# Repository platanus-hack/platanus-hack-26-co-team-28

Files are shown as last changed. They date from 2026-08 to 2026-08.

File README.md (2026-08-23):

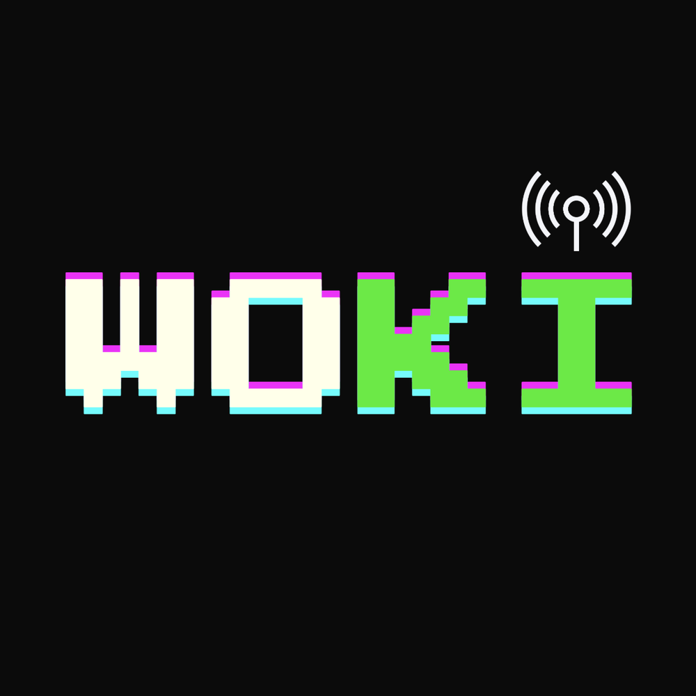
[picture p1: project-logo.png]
WOKI


# WOKI · Red de emergencia sin internet

**Track: 🚨 Emergencies · team-28 · Platanus Hack 26 Bogotá**







> Pedir ayuda y coordinar rescates sin internet, con visibilidad remota cuando vuelve la red.

Cuando un terremoto tumba la red celular, pedir ayuda deja de ser un problema de interfaz y se
vuelve un problema de comunicación. WOKI abre un camino local entre la persona afectada y el puesto
de mando, sin depender de internet.

```text
Celular → WiFi local → TTGO Esclavo → LoRa 915 MHz → TTGO Maestro → USB
                                                                     ↓
                                                     Centro Python + SQLite
                                                                     ↓ internet disponible
                                                        Vercel → Supabase
```

## Servicios locales y offline

| Servicio | Red o conexión | Dirección local | Qué permite hacer |
|---|---|---|---|
| Punto de ayuda | WiFi abierto **`[AFECTADOS] RED DE AYUDA WOKI`** | Portal cautivo; acceso manual en `https://ayuda.homiapp.xyz/` o `192.168.4.1` | Pedir ayuda, compartir la ubicación o reportarse a salvo desde cualquier celular, sin instalar una app |
| Portal del recurso | WiFi abierto **`RECURSO_<ID>`**, por ejemplo `RECURSO_GRUA07` | `http://192.168.4.1` | Recibir una misión o broadcast y confirmar su aceptación por LoRa |
| LoRa Maestro | Radio LoRa 915 MHz + USB serial | No publica una URL; usa `/dev/ttyUSB0` en Raspberry Pi o `/dev/cu.usbserial-*` en macOS | Conectar los nodos de campo con el Centro local |
| Command Center local | Raspberry Pi o laptop del puesto de mando | `http://localhost:8080` | Operar solicitudes, mapa, recursos, broadcasts y personas a salvo con SQLite, aun sin internet |
| Diagnóstico local | Mismo equipo del Centro | `http://localhost:8080/health` y `http://localhost:8080/api/v1/overview` | Verificar el Centro e integrar clientes locales |

Todos estos servicios operan sin internet. La dirección `192.168.4.1` se repite porque cada nodo
crea su propia red WiFi aislada: el celular debe conectarse primero al SSID correcto. Por seguridad,
el instalador expone el Centro solo en la misma laptop o Raspberry. Compartirlo en la LAN requiere
iniciarlo deliberadamente con `--host 0.0.0.0` y un `--api-token`; entonces se abre en
`http://<IP-DEL-CENTRO>:8080`.

## Todos los enlaces públicos

| Experiencia | URL | Qué demuestra | Alcance |
|---|---|---|---|
| **Entrega principal** | [Hub WOKI](https://woki-hub.vercel.app) | Entrada, onboarding y réplica online | URL oficial del concurso |
| Configuración guiada | [Preparar kit](https://woki-hub.vercel.app/setup) | Instalación del Maestro y Esclavo, voz y piezas 3D | Simulable sin dispositivos |
| Centro online | [Command Center](https://woki-hub.vercel.app/command-center) | Módulos operacionales con datos sincronizados | Réplica de solo lectura |
| Centro Python | [Demo en Render](https://woki-command-center-demo.onrender.com) | Centro local interactivo con datos sintéticos | Sin hardware ni sincronización externa; puede tardar en despertar |
| Diseño físico | [Visor 3D](https://woki-lora-enclosures.vercel.app) | Archivos STL/3MF listos para descargar e imprimir | Extensión física opcional |
| Flujo LoRa | [Visualización](https://lora.uprizing.me) | Recorrido conceptual entre celulares, nodos y Centro | Apoyo visual, no dependencia operacional |

El campo `deploy-url` de [`platanus-hack-project.jsonc`](./platanus-hack-project.jsonc) apunta al
Hub principal. Los demás despliegues son evidencia complementaria.

## Frictionless por diseño

- **Instalación asistida:** el onboarding visual entrega prompts breves y especializados para que
  ChatGPT, Claude u otro agente de IA acompañe el setup. Para perfiles técnicos, dos comandos
  instalan Arduino CLI, ESP32, librerías, firmware y Python sin requerir Arduino IDE.
- **Operación con triage:** el Centro prioriza la demanda y recomienda cómo distribuir recursos
  compatibles; el operador humano conserva la decisión sobre cada despacho crítico.
- **Acceso ciudadano sin app:** al conectarse a **`[AFECTADOS] RED DE AYUDA WOKI`** se abre el
  portal cautivo para pedir ayuda en pocos pasos. Los tags NFC/QR están definidos para instalarse
  en columnas y puntos seguros y facilitar el ingreso a la red; esta capa física aún debe validarse
  en campo.

## Cómo funciona

### 1. Portal local, sin app

El nodo afectado ofrece una red WiFi abierta y un portal servido por el ESP32. La persona elige
`RESCATE`, `MEDICO`, `FUEGO`, `AGUA` o `GRUA`, o se reporta a salvo. Después puede compartir GPS o
describir el lugar manualmente. La pantalla sigue el estado: recibida, aceptada, en ruta y resuelta.

### 2. LoRa bidireccional

Las placas LilyGO TTGO LoRa32 transportan paquetes cortos por SX1276 a 915 MHz. El protocolo usa
destino, identificador de mensaje, ACK, deduplicación, CAD y reintentos. El Centro recibe reportes y
también envía despachos, estados y broadcasts a los recursos.

### 3. Centro local como fuente de verdad

Una Raspberry Pi o laptop ejecuta el Centro Python. SQLite conserva solicitudes, recursos,
timeline, personas a salvo y una outbox durable. El mapa, triage y dashboard operan offline. El
sistema recomienda recursos compatibles, pero una persona autoriza cada despacho crítico.

```text
PENDIENTE → ACEPTADA → EN_CURSO → RESUELTA
                    ↘ CANCELADA
```

### 4. Sincronización eventual

Cuando vuelve internet, el Centro envía su outbox al endpoint autenticado de Vercel. Supabase
ingiere cada evento de forma idempotente y el Hub muestra una réplica de solo lectura. Si Vercel,
Supabase o internet fallan, la operación local continúa y la cola reintenta después.

### 5. Onboarding guiado

El Hub guía nueve pasos desde la descarga del proyecto hasta la verificación completa, incluyendo
antenas, Maestro, Esclavo, WiFi local y piezas imprimibles. El modo simulación permite entender el
recorrido sin disponer todavía del hardware.

## Estado demostrado

| Capacidad | Estado |
|---|---|
| Portal cautivo y envío desde celular | Validado en hardware |
| LoRa, ACK y canal bidireccional | Validado en hardware |
| SOS, triage, despacho, aceptación, trayecto y resolución | Implementado y probado automáticamente |
| Centro Python, SQLite y mapa offline | Implementado |
| Outbox, ingesta idempotente y Hub online | Implementado y desplegado |
| Onboarding, voz en español y prompts de soporte | Implementado y desplegado |
| NFC y QR para descubrir la red | Definido, todavía no implementado |
| Carcasas y bandejas 3D | Diseñadas; validar tolerancias físicas antes de campo |

## Stack tecnológico

| Capa | Tecnología | Responsabilidad |
|---|---|---|
| Hardware | LilyGO TTGO LoRa32 T3 V1.6.1, ESP32-PICO-D4, SX1276 | Nodos de campo y Gateway Maestro |
| Firmware | C++/Arduino, RadioLib, WiFi SoftAP | Portal local y protocolo LoRa 915 MHz |
| Centro offline | Python 3, SQLite WAL, pyserial | Radio, persistencia, triage, API y sincronizador |
| Mapas | Leaflet, VectorGrid, MBTiles, OpenStreetMap/Geofabrik | Cartografía local y online |
| Hub online | Next.js 16, React 19, TypeScript, Bun | Onboarding y Command Center sincronizado |
| Datos online | Supabase Postgres, RLS y RPC idempotente | Réplica segura de eventos operacionales |
| Despliegue | Vercel y Render | Hub principal y demo aislada del Centro Python |
| Onboarding | ElevenLabs Multilingual v2 + prompts para ChatGPT/Claude | Guía de voz y acompañamiento de instalación |
| Diseño físico | OpenSCAD, STL/3MF y Three.js | Carcasas y visor de piezas imprimibles |

## Probarlo

### Camino guiado

Abre <https://woki-hub.vercel.app/setup>. El modo simulación está activo por defecto.

### Camino técnico

Clona el repositorio y conecta siempre la antena de 915 MHz antes de energizar una placa.

```bash
git clone https://github.com/platanus-hack/platanus-hack-26-co-team-28.git
cd platanus-hack-26-co-team-28
```

Prepara el Gateway Maestro y el Centro en macOS o Linux:

```bash
bash lora-emergencia/scripts/instalar_maestro.sh
```

Prepara un nodo Esclavo/Recurso:

```bash
bash lora-emergencia/scripts/instalar_esclavo.sh
```

Sin hardware, inicia solamente el Centro con datos sintéticos:

```bash
cd lora-emergencia/center
python3 center.py --demo
```

⚠️ **Nunca energices una placa sin la antena enroscada.** Transmitir sin antena puede dañar el
amplificador de radio.

## Documentación

| Quiero… | Leer |
|---|---|
| El relato para jurados | [`project-description.md`](project-description.md) |
| La topología completa | [`docs/ARQUITECTURA-CONEXIONES.md`](docs/ARQUITECTURA-CONEXIONES.md) |
| Operar el Centro y sincronizar | [`docs/OPERAR-SINCRONIZACION.md`](docs/OPERAR-SINCRONIZACION.md) |
| Revisar el hardware compatible | [`lora-emergencia/docs/HARDWARE.md`](lora-emergencia/docs/HARDWARE.md) |
| Entender el protocolo de radio | [`lora-emergencia/docs/PROTOCOLO-MINIMO.md`](lora-emergencia/docs/PROTOCOLO-MINIMO.md) |
| Preparar el portal cautivo | [`lora-emergencia/docs/PORTAL-CAUTIVO-E2E.md`](lora-emergencia/docs/PORTAL-CAUTIVO-E2E.md) |
| Fabricar las piezas 3D | [`lora-emergencia/diseno-3d/README.md`](lora-emergencia/diseno-3d/README.md) |
| Navegar toda la documentación | [`docs/README.md`](docs/README.md) |

Cada capacidad se marca como **implementada**, **validada en hardware**, **definida** o
**investigada**. No usamos “funciona” para algo que solo está diseñado.

## Equipo

- Juan Ortega ([@juanortega10](https://github.com/juanortega10))
- Nicolas Vargas ([@MrUprizing](https://github.com/MrUprizing))
- Jhomar Astuyauri Herencia ([@asther0](https://github.com/asther0))
- Emmy Daniela Arias Pardo ([@estparcae](https://github.com/estparcae))
- Manuel Torres ([@amunm9](https://github.com/amunm9))

**WOKI funciona cuando internet no funciona.**

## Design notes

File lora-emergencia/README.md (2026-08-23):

# lora-emergencia

Red de nodos de emergencia. Comunicación entre placas **LilyGO TTGO LoRa32** por LoRa 915 MHz, para llevar reportes cortos desde una zona sin señal hasta un centro de operaciones.

Este repo tiene el firmware que ya funciona entre dos placas, los scripts para flashear y leer, y la documentación para seguir avanzando.

> La entrada principal del proyecto y el orden vigente de lectura están en
> [`../README.md`](../README.md) y [`../docs/README.md`](../docs/README.md). Los sketches
> `nodo_tx`, `gateway_rx` y el documento `docs/PROTOCOL.md` son referencias legacy; el demo
> actual usa el protocolo direccionado de `docs/PROTOCOLO-MINIMO.md`.

---

## Estado actual (qué ya funciona)

- ✅ Enlace LoRa de una vía entre 2 placas. Verificado en hardware.
- ✅ Enlace bidireccional con ACK. El gateway confirma cada reporte.
- ✅ Toolchain macOS con `arduino-cli` + RadioLib.

Pruebas reales medidas entre 2 placas a ~20 cm:

Una vía (gateway recibe el reporte):
```
RECV|a3f21c|atrapado|apto401|604232|RSSI:-23.00|SNR:9.50
```

Bidireccional (el nodo recibe el ACK de vuelta):
```
[NODO] ACK recibido. RSSI:-21.00 SNR:9.25
```

La cadena completa: nodo → LoRa 915 → gateway → ACK → nodo. Con pérdidas ocasionales que dispara el reintento, comportamiento normal de LoRa sin CAD.

---

## Hardware

- 2× **LilyGO TTGO LoRa32**, modelo **T3 V1.6.1**, banda **915 MHz** (chip **SX1276**).
- La placa integra ESP32 (WiFi + BT) + radio LoRa SX1276 + conector SMA + batería JST + micro-USB.
- Antena 915 MHz (viene en la caja o se compra aparte).
- Cable **micro-USB de datos** (no de solo carga).

**Regla de oro:** nunca energizar una placa sin la antena enroscada. Transmitir sin antena daña el amplificador de forma permanente.

Ver [`docs/HARDWARE.md`](docs/HARDWARE.md) para pines y detalles.

---

## Estructura del repo

```
lora-emergencia/
├── README.md                 este archivo
├── nodo_tx/                  firmware: solo transmisor (test más simple)
├── gateway_rx/               firmware: solo receptor (test más simple)
├── nodo_bidir/               firmware: nodo con ACK (bidireccional)
├── gateway_bidir/            firmware: gateway con ACK (bidireccional)
├── nodo_portal/              firmware MVP: WiFi "AYUDA" + portal cautivo + LoRa
├── nodo_recurso/             firmware: recurso que recibe despachos/broadcasts + web local
├── center/
│   ├── center.py             command center offline del puesto de mando
│   ├── command_core.py       dominio, protocolo y persistencia SQLite
│   ├── CENTRO.md             guía operativa Raspberry ↔ gateway ↔ recursos
│   └── TOOLCHAIN.md          instalación, compilación y diagnóstico
├── diseno-3d/                módulos físicos, CAD paramétrico y STL/3MF
│   ├── MODULOS.md            centro maestro, nodo de campo y energía
│   ├── cad/                   fuente OpenSCAD
│   └── exports/               archivos listos para laminar
├── scripts/
│   ├── flash.sh              compilar y subir un firmware a una placa
│   ├── monitor.sh            leer el serial de una placa
│   └── pi_reader.py          leer y parsear el gateway desde la Raspberry Pi
└── docs/
    ├── SETUP.md              instalar el entorno paso a paso
    ├── HARDWARE.md           placa, pines, antena
    ├── PROTOCOL.md           formato de mensajes y parámetros LoRa
    ├── ARCHITECTURE.md       diseño del sistema y roadmap
    └── TROUBLESHOOTING.md    errores reales y cómo se resolvieron
```

---

## Quickstart

### 1. Instala el entorno (una sola vez)

```bash
brew install arduino-cli
arduino-cli config init
arduino-cli config add board_manager.additional_urls https://raw.githubusercontent.com/espressif/arduino-esp32/gh-pages/package_esp32_index.json
arduino-cli core update-index
arduino-cli core install esp32:esp32     # descarga grande (~500 MB), tarda
arduino-cli lib install RadioLib
```

Detalle completo en [`docs/SETUP.md`](docs/SETUP.md).

### 2. Encuentra el puerto de tu placa

Conecta la placa (con antena) y corre:

```bash
arduino-cli board list
```

Busca algo como `/dev/cu.usbserial-XXXXXXXX` (macOS) o `/dev/ttyUSB0` (Linux/Pi).

### 3. Flashea y prueba el enlace de una vía

Con dos placas y dos puertos:

```bash
# Placa 1 = transmisor
./scripts/flash.sh nodo_tx /dev/cu.usbserial-AAAA

# Placa 2 = receptor
./scripts/flash.sh gateway_rx /dev/cu.usbserial-BBBB

# Lee el receptor: deben aparecer las lineas RECV|...
./scripts/monitor.sh /dev/cu.usbserial-BBBB
```

### 4. Prueba el enlace bidireccional con ACK

```bash
./scripts/flash.sh gateway_bidir /dev/cu.usbserial-BBBB
./scripts/flash.sh nodo_bidir    /dev/cu.usbserial-AAAA
./scripts/monitor.sh /dev/cu.usbserial-AAAA   # el nodo muestra "ACK recibido"
```

---

## Los 4 firmwares

| Firmware | Rol | Qué hace |
|---|---|---|
| `nodo_tx` | Transmisor | Envía un reporte cada 5 s. El test más simple |
| `gateway_rx` | Receptor | Recibe y lo imprime con RSSI y SNR |
| `nodo_bidir` | Nodo con ACK | Envía, espera confirmación, reintenta 3 veces con backoff |
| `gateway_bidir` | Gateway con ACK | Recibe, imprime, y confirma de vuelta al nodo |

Empieza siempre por `nodo_tx` + `gateway_rx`. Si el enlace de una vía funciona, todo lo demás es software.

---

## MVP de emergencia (ciclo completo)

El flujo mínimo: un civil pide ayuda desde su celular, sin app, y el reporte llega al puesto de mando.

```
📱 civil → WiFi "AYUDA" → NODO (portal) → LoRa → GATEWAY → USB → CENTRO (dashboard)
```

Componentes:
- **Nodo** (`nodo_portal`): red WiFi abierta `AYUDA` + portal cautivo (sin app, sin JS). Botones: agua, médico, rescate, a salvo + detalle. Envía por LoRa y espera ACK.
- **Gateway** (`gateway_bidir`): recibe el reporte, responde ACK, lo imprime por serial.
- **Centro** (`center/center.py`): lee el gateway y muestra un tablero en vivo con contadores y color por tipo.

### Cómo correrlo

```bash
# 1. Placa del nodo (crea la red AYUDA)
./scripts/flash.sh nodo_portal /dev/cu.usbserial-AAAA

# 2. Placa del gateway (conectada a la Mac o a la Pi)
./scripts/flash.sh gateway_bidir /dev/cu.usbserial-BBBB

# 3. Centro: lee el gateway y abre el tablero
pip install pyserial          # o: pip install pyserial --break-system-packages
python3 center/center.py /dev/cu.usbserial-BBBB
# abre http://localhost:8080

# 4. Con el celular: conéctate a la red WiFi "AYUDA".
#    El portal se abre solo. Pide ayuda. El reporte aparece en el tablero.
```

Modo sin hardware para probar el tablero:
```bash
python3 center/center.py --demo
```

### Estado verificado

- Nodo: `SoftAP 'AYUDA' en 192.168.4.1` + `LoRa OK`. ✅
- Gateway: recibe + ACK. ✅
- Centro: tablero + API de reportes. ✅
- Falta probar en un teléfono real el disparo del portal cautivo (iOS lo abre solo; Android a veces pide abrir el navegador en `192.168.4.1`).

---

## Parámetros LoRa (deben coincidir en TODAS las placas)

```cpp
radio.begin(915.0, 125.0, 7, 5, 0x12, 20, 8);
//          freq   BW    SF CR sync pwr preamble
```

**La falla nº1 de LoRa:** si un solo parámetro difiere entre dos placas, no se oyen y **no hay ningún mensaje de error**. Si no recibes nada, revisa esto primero.

Ver [`docs/PROTOCOL.md`](docs/PROTOCOL.md).

---

## Próximos pasos (para el equipo)

1. **Validar el loop físico vigente:** portal HTTPS → LoRa → centro → estados de vuelta al ciudadano.
2. **Publicar el Hub online:** réplica de consulta en Vercel + Supabase.
3. **Sincronizar con outbox:** enviar Eventos operacionales sin bloquear SQLite ni el flujo local.
4. **Hacer reproducible el portal HTTPS:** plantilla segura de credenciales y compilación limpia desde un clon.
5. **Escalar el borde:** agregación, identidad derivada del dispositivo y pruebas con múltiples nodos separados.

Ver el diseño completo y el roadmap en [`docs/ARCHITECTURE.md`](docs/ARCHITECTURE.md).

---

## Si algo no funciona

Lee [`docs/TROUBLESHOOTING.md`](docs/TROUBLESHOOTING.md). Los errores reales que ya resolvimos:
- Subida falla a 921600 → usa `UploadSpeed=115200` (los scripts ya lo hacen).
- El puerto no aparece → driver USB o cable de solo carga.
- No recibe nada → los 6 parámetros LoRa no coinciden.

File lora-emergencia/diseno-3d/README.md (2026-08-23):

# Diseño 3D · sistema físico WOKI

Kit mecánico del centro LoRa y los nodos de campo. La carpeta contiene archivos
STL/3MF, fuente OpenSCAD, cotas, lista de compra y pruebas pendientes.

## Qué se fabrica

- **Centro maestro:** marco y pies para la pantalla, bandeja de servicio para
  Raspberry Pi 4 + TTGO maestro y cuna del power bank.
- **Nodo demo:** base, tapa abierta y placa universal de batería.
- **Nodo de campo:** bandeja interna para una caja comercial Hammond IP68. La
  caja sellada no se imprime: eso evita afirmar resistencia al agua sin ensayos.

La selección no imprimible y sus fuentes están en
[`ABASTECIMIENTO.md`](ABASTECIMIENTO.md). La arquitectura está en
[`MODULOS.md`](MODULOS.md) y el dictamen de suficiencia en
[`VERIFICACION.md`](VERIFICACION.md).

## Ver el inventario

```bash
python3 -m http.server 8090 --directory lora-emergencia/diseno-3d
```

Abre <http://localhost:8090> o la copia pública:
<https://woki-lora-enclosures.vercel.app>.

Cada tarjeta permite abrir la pieza en un visor 3D. Dentro del modal se puede
rotar arrastrando, acercar con la rueda o un pellizco, desplazar con clic derecho
o dos dedos y recuperar el encuadre con **Reiniciar vista**. El visor carga los
STL y Three.js desde esta misma carpeta, sin depender de un CDN o de Internet.

## Generar y validar

```bash
cd lora-emergencia/diseno-3d
make all
make validate
make previews
```

OpenSCAD genera ocho geometrías distintas; `pantalla_pie` se imprime dos veces.
Cada pieza tiene STL y 3MF. El validador comprueba dimensiones, componentes y
aristas manifold sin dependencias externas de Python.

## Estado de certeza

- Raspberry Pi 4 y TTGO T3 V1.6.1: hardware confirmado.
- Pantalla: coincidencia visual fuerte con Waveshare 7inch HDMI LCD (C); el CAD
  usa el dibujo oficial y ranuras de tolerancia, pero falta leer la etiqueta
  trasera de la unidad real antes de imprimir el marco definitivo.
- Energía del nodo: solo batería 1S protegida; el TTGO no incorpora BMS.
- Uso con lluvia: caja comercial IP68 + bandeja interna impresa.
- Ningún ajuste se considera validado hasta imprimirlo contra el hardware real.

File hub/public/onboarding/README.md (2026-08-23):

# Imágenes del onboarding WOKI

Estas imágenes no contienen instrucciones incrustadas. El texto, los indicadores y las
flechas interactivas deben superponerse desde la interfaz para poder corregirlos sin
regenerar los recursos.

| Archivo | Uso sugerido | Mensaje principal |
| --- | --- | --- |
| `kit-overview.webp` | Inventario inicial | Verifica que tienes las placas, antenas, cables, Raspberry Pi, batería y celulares. La pantalla externa no es necesaria. |
| `antenna-first.webp` | Preparación de cada TTGO | Conecta la antena antes de suministrar energía o conectar USB. |
| `connect-local-wifi.webp` | Nodo civil o de recurso | Desde el celular, conéctate directamente a `AYUDA` o `RECURSO_<ID>`. Es normal que el teléfono indique “sin internet”. Si el portal no abre solo, visita `http://192.168.4.1`. |
| `command-center-wiring.webp` | Centro local | Conecta el gateway por USB de datos a la Raspberry Pi, alimenta la Pi y abre el Centro desde el celular en la red local. |
| `system-topology.webp` | Explicación final | Los celulares hablan por Wi-Fi local con WOKI; los nodos hablan por LoRa; solo el Centro sincroniza eventualmente con internet. |

Código de color sugerido para las superposiciones:

- Azul: Wi-Fi local.
- Verde lima: LoRa.
- Naranja: USB, datos o alimentación.
- Gris punteado: sincronización online opcional.

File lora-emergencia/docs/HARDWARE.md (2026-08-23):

# HARDWARE · LilyGO TTGO LoRa32 T3 V1.6.1

## La placa

- Modelo: **LilyGO TTGO LoRa32**, silkscreen **T3_V1.6.1**.
- SoC: **ESP32-PICO-D4** (WiFi 2.4 GHz + Bluetooth + doble núcleo).
- Radio LoRa: **Semtech SX1276**, banda **915 MHz** (también existe versión 868).
- Conector de antena: **SMA** (dorado).
- Alimentación: micro-USB, o batería LiPo por conector JST 1.25.
- Controles: interruptor ON/OFF, botón RST, botón BOOT.
- Chip USB-serial: CP2102 o CH9102 según el lote (macOS moderno los reconoce solos).

## Pines LoRa (SX1276) para RadioLib

Estos son los pines usados en todos los firmwares del repo:

| Función | GPIO |
|---|---|
| SCK  | 5  |
| MISO | 19 |
| MOSI | 27 |
| CS / NSS | 18 |
| RST  | 23 |
| DIO0 | 26 |
| DIO1 | 33 |

En código:

```cpp
#include <RadioLib.h>
SPI.begin(5, 19, 27, 18);                    // SCK, MISO, MOSI, CS
SX1276 radio = new Module(18, 26, 23, 33);   // CS, DIO0, RST, DIO1
```

## Antena

- Enrosca la antena 915 MHz en el conector SMA **antes** de energizar.
- **Nunca transmitas sin antena.** El SX1276 se daña de forma permanente.
- Una antena látigo de 915 MHz mide ~7-8 cm. Una de ~17 cm suele ser de 433 MHz (no sirve).

## Alimentación en campo

- Un nodo activo (WiFi AP + LoRa) consume ~120-250 mA.
- Un powerbank de 20.000 mAh lo mantiene más de 24 h.
- Aviso: algunos powerbanks se apagan solos cuando el consumo baja de 50-100 mA. Con el nodo activo no pasa, pero pruébalo con el powerbank real.

## OLED

Algunas T3 V1.6.1 traen pantalla OLED (I2C, SDA 21 / SCL 22) y otras no. Los firmwares vigentes `gateway_bidir`, `nodo_portal_https` y `range_movil` la detectan antes de usarla; la operación principal no depende de que esté presente.

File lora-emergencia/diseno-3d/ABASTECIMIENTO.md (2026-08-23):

# Abastecimiento y compatibilidad

Investigación cerrada el **23 de agosto de 2026**. Precio y stock pueden cambiar;
las cotas y parámetros eléctricos se enlazan a fabricante siempre que existe.

## Compra recomendada

### Un centro maestro

| Cant. | Componente exacto o especificación | Decisión |
|---:|---|---|
| 1 | Raspberry Pi 4 Model B existente | Reutilizar |
| 1 | [Carcasa oficial Raspberry Pi 4](https://www.raspberrypi.com/products/raspberry-pi-4-case/) | Comprar si la Pi sigue expuesta |
| 1 | [Ventilador oficial para esa carcasa](https://www.raspberrypi.com/products/raspberry-pi-4-case-fan/) | Comprar; incluye disipador 18 × 18 × 10 mm |
| 1 | Pantalla existente, candidata [Waveshare 7inch HDMI LCD (C)](https://www.waveshare.com/wiki/7inch_HDMI_LCD_%28C%29) | Reutilizar; confirmar etiqueta trasera |
| 1 | TTGO T3 V1.6.1 maestro existente | Reutilizar |
| 1 | [Baseus Adaman 65 W, 20.000 mAh](https://www.baseus.com/products/adaman-power-bank-65w-20000mah) | Candidato principal: 74 Wh, 154 × 65 × 27 mm, USB-C 5 V/3 A |
| 1 | Cable USB-C a USB-C de 3 A, 0,3–0,5 m | Power bank → Raspberry |
| 1 | Cable micro-HDMI macho a HDMI macho, 0,3–0,5 m | Raspberry → pantalla |
| 2 | Cable USB-A a micro-USB **de datos**, corto | Pantalla táctil y TTGO serie |
| 4 | Correas de velcro 15–20 mm | Dos para Pi, dos para power bank |
| 4 | M3 × 12 + arandela; 4 separadores M3 de 12–18 mm | Pantalla y bandeja |

La Raspberry Pi 4 requiere una fuente recomendada de 3 A y admite hasta 1,2 A
totales para periféricos USB. La pantalla declara 500 mA; por eso la validación
eléctrica de pantalla + TTGO es obligatoria.

### Cada nodo de campo

| Cant. | Componente exacto o especificación | Decisión |
|---:|---|---|
| 1 | [TTGO T3 LoRa32 V1.6.1 915 MHz](https://lilygo.cc/products/lora3) | Placa existente; SMA estándar |
| 1 | [Hammond 1554F2GYCL](https://www.hammfg.com/part/1554F2GYCL) | Policarbonato IP68, 119 × 89 × 61 mm, tapa transparente |
| 1 | [Amphenol 095-902-569-006](https://www.amphenolrf.com/en-us/part/095-902-569-006/9316/) | SMA 50 Ω, RG-316, 153 mm, pasamuros IP67 |
| 1 | Antena 915 MHz incluida por LILYGO | Se conecta al pasamuros; nunca transmitir sin antena |
| 1 | [LiPo protegida 2.000 mAh](https://www.adafruit.com/product/2011) **o** [Li-ion protegida 4.400 mAh](https://www.adafruit.com/product/354) | Compacta 60 × 36 × 7 mm o extendida 69 × 37 × 18 mm |
| 1 | Pigtail JST-GH 1,25 mm incluido con TTGO | Adaptar a batería; verificar polaridad |
| 2 | Correas de velcro 10–15 mm | Una TTGO, una batería |
| 4 | M3 × 8 mm | Bandeja a insertos internos Hammond |
| 1 | Prensaestopa IP68 adicional, si se agrega cable externo | Dimensionar al cable real; preferir ningún cable |

## Por qué se seleccionó así

### Pantalla

La foto coincide en orejas verdes, HDMI/USB laterales y proporción con la
Waveshare C. El fabricante indica panel de 164,9 × 106,96 × 8 mm, 2,5 W, 5 V y
500 mA; el dibujo mecánico amplía la envolvente con PCB/orejas a 164,9 × 124,27
mm. El marco usa ranuras para tolerancia, pero la etiqueta sigue siendo la prueba
definitiva de revisión.

### Raspberry y refrigeración

Usar la carcasa y el ventilador oficiales convierte la Pi en un submódulo
protegido, con flujo probado de hasta 1,4 CFM. La bandeja impresa lo sujeta con
correas y no comprime directamente la PCB.

### Energía del nodo

LILYGO dice expresamente que T3 V1.6.1 **no tiene BMS** y exige batería con
protección. También especifica 3,7 V y carga de 500 mA. Las dos baterías elegidas
incorporan protección; la de 4.400 mAh admite carga lenta a 500 mA.

Los conectores no coinciden: Adafruit usa JST-PH 2,0 mm y LILYGO JST-GH 1,25 mm.
No forzar ni invertir un conector. Empalmar el pigtail suministrado, aislar cada
conductor y verificar con multímetro positivo/negativo antes de enchufar.

### Protección de campo

La Hammond mantiene un grado IP real y ofrece insertos M3. El pasamuros Amphenol
evita transferir palanca de la antena al SMA de la placa. Una carcasa FDM abierta
se conserva únicamente para mesa/demo.

## Disponibilidad observada

- Adafruit: baterías de 2.000 y 4.400 mAh figuraban disponibles al consultar.
- Hammond: la referencia tiene distribución por DigiKey/Mouser; el fabricante
  publica dibujo, STEP/IGES y repuestos de junta/tornillos.
- Baseus: la referencia exacta puede variar por país; si no está disponible,
  aceptar solo un reemplazo de 20.000 mAh con salida USB-C sostenida de 5 V/3 A,
  tres salidas y dimensiones medidas antes de imprimir la cuna.
- Baterías enviadas internacionalmente pueden tener restricciones. Priorizar un
  proveedor local que declare **PCM/BMS**, voltaje, medidas y polaridad.

## No comprar todavía

- Baterías sin ficha, celdas 18650 sueltas o paquetes sin protección.
- Conectores “JST” sin indicar familia y paso.
- Antena RP-SMA: la selección es SMA estándar de 50 Ω.
- Una segunda caja impresa “impermeable”; duplica trabajo y no prueba IP.
- GPS físico para el nodo: el flujo actual acepta ubicación del celular y no
  requiere rastreo continuo.

## Criterio para aceptar sustitutos

1. Igual voltaje y corriente, nunca solo “mismos watts”.
2. Medidas documentadas y tolerancia de al menos 0,7 mm por lado en CAD.
3. Batería 1S protegida y polaridad verificada.
4. Radio/antena 915 MHz, 50 Ω y SMA estándar.
5. Caja de campo con certificación IP del fabricante, no del vendedor.
6. Cable USB de datos cuando transporta táctil o serial; uno de carga no basta.

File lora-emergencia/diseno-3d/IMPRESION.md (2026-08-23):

# Fabricación e impresión

## Archivos

| Equipo | Pieza | Cantidad | STL / 3MF |
|---|---|---:|---|
| Centro | Bandeja RPi4 + TTGO | 1 | `centro_bandeja` |
| Centro | Marco trasero de pantalla | 1 | `pantalla_marco` |
| Centro | Pie inclinado | 2 | `pantalla_pie` |
| Centro | Cuna Baseus 20 Ah | 1 | `centro_powerbank` |
| Nodo demo | Base TTGO | 1 | `nodo_base` |
| Nodo demo | Tapa abierta | 1 | `nodo_tapa` |
| Nodo demo | Placa universal de batería | 1 | `bateria_placa` |
| Nodo campo | Bandeja interna Hammond IP68 | 1 | `nodo_bandeja_ip68` |

Cada nombre existe en `exports/stl/` y `exports/3mf/`. Los 3MF contienen la
geometría; el perfil del laminador se define según la impresora disponible.

## Perfil inicial

- PETG para piezas finales; PLA solo para pruebas de ajuste interiores.
- Boquilla 0,4 mm; capa 0,20 mm; 3 perímetros; 20–25 % gyroid.
- 5 capas superiores e inferiores para marco y pies.
- Sin soportes con la orientación exportada.
- Compensación de elephant foot: 0,15–0,20 mm si está disponible.
- No escalar los modelos en el laminador.

## Orden recomendado

1. Imprimir `pantalla_pie` una vez y probar el canal con una tira de 3,2 mm.
2. Confirmar etiqueta/cotas de pantalla; imprimir `pantalla_marco`.
3. Imprimir `centro_bandeja` y verificar carcasa RPi4, USB, HDMI y SMA.
4. Comprar la batería elegida y la caja Hammond.
5. Imprimir `nodo_bandeja_ip68`; presentar piezas sin batería conectada.
6. Solo después imprimir el resto del kit.

## Montaje y pruebas

- M3 con arandela para pantalla y caja Hammond; no sobreapretar plástico/PCB.
- Separadores de 12–18 mm entre marco de pantalla y bandeja de electrónica.
- Velcro de 15–20 mm; una correa por componente en el nodo.
- Mantener radios suaves en HDMI, USB y coaxial; ningún cable sostiene peso.
- Ensayo térmico de dos horas con WiFi/LoRa activos.
- Ensayo de autonomía completo y registro de reinicios/bajo voltaje.
- Ensayo de salpicadura solo con la caja comercial cerrada y electrónica de
  prueba. Perforar la caja puede invalidar su grado IP si el pasamuros no sella.

Los modelos son manifold e imprimibles, pero aún no tienen ajuste físico
verificado ni certificación de impacto, fuego o estanqueidad.

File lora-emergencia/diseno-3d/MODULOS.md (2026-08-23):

# WOKI · módulos físicos

El sistema necesita dos equipos, no una colección abierta de accesorios.

## 1. Centro maestro

| Elemento | Selección | Integración mecánica |
|---|---|---|
| Computador | Raspberry Pi 4 Model B | Carcasa oficial + ventilador oficial; sujeta con dos correas a `centro_bandeja` |
| Pantalla | Candidata Waveshare 7inch HDMI LCD (C) | `pantalla_marco` + 2 × `pantalla_pie` |
| Radio maestro | TTGO T3 V1.6.1, 915 MHz | Dock de `centro_bandeja` |
| Energía móvil | Baseus Adaman 65 W, 20.000 mAh | `centro_powerbank` + dos correas |
| Antena | SMA 915 MHz incluida | Exterior, siempre conectada antes de transmitir |

### Cableado del centro

```text
Power bank USB-C ──────────────> USB-C de Raspberry Pi 4 (5 V / 3 A)
Raspberry micro-HDMI ──────────> HDMI estándar de pantalla
Raspberry USB-A ───────────────> micro-USB de pantalla (táctil + 5 V)
Raspberry USB-A ───────────────> micro-USB TTGO (datos serie + 5 V)
```

La pantalla requiere 500 mA y el límite total oficial de periféricos USB de la
Raspberry Pi 4 es 1,2 A. Pantalla y TTGO deben probarse juntos bajo carga. Si hay
avisos de bajo voltaje se debe usar un hub USB alimentado, no improvisar un cable
en Y. El power bank seleccionado entrega 5 V/3 A por USB-C.

### Piezas del centro

| Pieza | Medida exterior | Cantidad | Rol |
|---|---:|---:|---|
| `pantalla_marco` | 170 × 129 × 3,2 mm | 1 | Marco trasero ventilado; patrón 148,9 × 114,96 mm |
| `pantalla_pie` | 54 × 46 × 16 mm | 2 | Soporte de mesa con inclinación de 12° |
| `centro_bandeja` | 168 × 76 × 10,65 mm | 1 | Carcasa RPi4 por correas + dock TTGO |
| `centro_powerbank` | 161,2 × 72,2 × 7 mm | 1 | Cuna abierta para batería central |

`pantalla_marco` supone la Waveshare candidata. Antes de imprimir se debe
confirmar la etiqueta posterior o medir 164,9 × 124,27 mm de envolvente y
148,9 × 114,96 mm entre centros. No bloquea HDMI, micro-USB ni el interruptor.

## 2. Nodo de campo

| Elemento | Selección | Integración mecánica |
|---|---|---|
| Radio | TTGO T3 V1.6.1, 915 MHz | Bandeja interna, lado independiente |
| Batería | 3,7 V 1S protegida, 2.000 o 4.400 mAh | Correa separada; nunca comprimir |
| Envolvente | Hammond 1554F2GYCL, policarbonato | Caja comercial IP68 de 119 × 89 × 61 mm |
| Antena exterior | SMA 915 MHz | Pigtail Amphenol IP67 a pasamuros |
| Transporte | Pies/pole-mount Hammond o correa exterior | No perforar fuera del plan de sellado |

### Dos configuraciones deliberadas

- `nodo_base` + `nodo_tapa` + `bateria_placa`: demo interior, accesible y rápida.
- `nodo_bandeja_ip68` dentro de Hammond 1554F2GYCL: candidato para campo.

La bandeja IP68 mide 106 × 75 × 5 mm, usa el patrón nominal de insertos M3 de
100 × 68 mm y separa TTGO y batería. La caja admite 54,5 mm de altura interior;
un pack de 69 × 37 × 18 mm cabe junto a la placa, pero debe probarse físicamente.

## 3. Decisiones de energía

### Nodo

- Ligero: LiPo protegida Adafruit 2.000 mAh, 60 × 36 × 7 mm.
- Mayor autonomía: Li-ion protegida Adafruit 4.400 mAh, 69 × 37 × 18 mm.
- El conector de esas baterías es JST-PH 2,0 mm; el TTGO usa JST-GH 1,25 mm.
  Se utiliza el pigtail incluido por LILYGO, con empalme aislado y polaridad
  verificada con multímetro antes de conectar.
- No usar celdas 18650 sueltas, baterías sin protección ni paquetes hinchados.

La autonomía no se promete a partir de la capacidad nominal. Debe medirse con
portal WiFi, OLED y radio LoRa en el patrón operativo real.

### Centro

El power bank Baseus de 74 Wh da margen para la Raspberry, la pantalla y el TTGO,
pero la autonomía debe medirse. Conectar todo antes de encender, ya que cambiar
la carga de una fuente USB-PD multipuerto puede renegociar la alimentación.

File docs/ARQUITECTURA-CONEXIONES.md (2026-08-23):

# WOKI · arquitectura de conexiones electrónicas y de software

Este documento es la fuente de verdad visual del sistema completo. Separa tres
escalas que no deben mezclarse en un solo dibujo: topología operacional, montaje
eléctrico y módulos de software.

Estado reconstruido desde el firmware, el command center y la documentación el
2026-08-23.

Entregables visuales listos:

- [Fuente editable draw.io con tres páginas](diagramas/woki-arquitectura.drawio).
- [Lámina vectorial SVG](diagramas/woki-arquitectura-sistema.svg).
- [Lámina PNG para presentaciones](diagramas/woki-arquitectura-sistema.png).

## 1. Decisión de representación

- **Mermaid en este repositorio** conserva la arquitectura junto al código, se
  puede revisar en Git y se puede pegar en draw.io para obtener un lienzo editable.
- **draw.io / diagrams.net** es la salida recomendada para la lámina de presentación:
  permite importar Mermaid, incorporar las imágenes del diseño 3D y exportar SVG o PNG.
- **KiCad** será la fuente de verdad eléctrica si se agrega una placa propia,
  distribución de potencia, sensores o un RTC cableado. El esquema actual usa placas
  integradas y cables comerciales, por lo que la tabla de conexiones es suficiente.
- **Excalidraw** sirve para discutir ideas en vivo, pero no como fuente de verdad final:
  sus conexiones y etiquetas se mantienen manualmente.

Referencias oficiales:

- Mermaid: <https://mermaid.js.org/syntax/architecture.html>
- Importar Mermaid en draw.io: <https://www.drawio.com/docs/tutorials/diagrams-from-code/>
- Diagramas técnicos en draw.io: <https://www.drawio.com/docs/getting-started/technical-diagrams/>
- Editor de esquemas de KiCad: <https://docs.kicad.org/10.0/en/eeschema/eeschema.pdf>
- Vistas breadboard/esquema de Fritzing: <https://fritzing.org/learning/get-started/project-view>
- Excalidraw: <https://github.com/excalidraw/excalidraw>
- Structurizr DSL, si WOKI crece a múltiples centros: <https://docs.structurizr.com/>

## 2. Leyenda de estado

| Marca | Significado |
|---|---|
| `ACTUAL` | Existe en el código o montaje vigente. |
| `VALIDAR` | Está diseñado, pero requiere prueba con hardware real. |
| `PROPUESTO` | Recomendación de arquitectura todavía no implementada. |
| `FUTURO` | Extensión deliberadamente fuera del circuito operacional offline. |

## 3. Vista 1 · sistema completo

```mermaid
flowchart LR
  classDef actual fill:#e8f5e9,stroke:#2e7d32,color:#172117
  classDef validar fill:#fff8e1,stroke:#a66a00,color:#2b2100
  classDef futuro fill:#eef3ff,stroke:#3559a8,color:#101b35,stroke-dasharray: 5 4
  classDef persona fill:#f5f5f5,stroke:#5f6368,color:#171717

  subgraph CAMPO[Campo]
    CIVIL[Celular del afectado]:::persona
    NODO_CIVIL["ACTUAL · Nodo civil<br/>TTGO T3 V1.6.1<br/>Portal WiFi + LoRa"]:::actual
    RECURSO[Celular del recurso]:::persona
    NODO_RECURSO["ACTUAL · Nodo recurso<br/>TTGO T3 V1.6.1<br/>Portal de misión + LoRa"]:::actual

    CIVIL <-->|"WiFi 2.4 GHz · HTTP/HTTPS<br/>metros"| NODO_CIVIL
    RECURSO <-->|"WiFi 2.4 GHz · HTTP<br/>metros"| NODO_RECURSO
  end

  subgraph CENTRO[Centro local · autoridad operacional]
    GW["ACTUAL · Gateway activo<br/>TTGO T3 V1.6.1"]:::actual
    GW_B["VALIDAR · Gateway de respaldo<br/>apagado o RF inactivo"]:::validar
    PI["ACTUAL · Raspberry Pi 4<br/>Python + reglas + HTTP"]:::actual
    DB[("ACTUAL · SQLite<br/>estado + historial")]:::actual
    MAPA[("ACTUAL · mapa offline<br/>MBTiles opcional")]:::actual
    UI["ACTUAL · Dashboard local<br/>pantalla / navegador"]:::actual
    RTC["PROPUESTO · RTC para Pi<br/>hora válida sin internet"]:::futuro

    GW <-->|"micro-USB de datos<br/>serial 115200 + 5 V"| PI
    GW_B -. "conmutación manual en demo" .-> PI
    PI <--> DB
    PI <--> MAPA
    PI <-->|"HTTP local + SSE"| UI
    RTC -. "I2C / HAT" .-> PI
  end

  NODO_CIVIL <-->|"LoRa 915 MHz · canal único<br/>SF7 / BW125 / CR 4/5 / sync 0x12"| GW
  NODO_RECURSO <-->|"LoRa 915 MHz · canal único<br/>ACK + reintento + CAD"| GW

  subgraph ONLINE[Extensión online]
    SYNC["ACTUAL · Outbox + SyncWorker<br/>local, opt-in"]:::actual
    INGESTA["VALIDAR · Ingesta idempotente<br/>código Vercel, sin despliegue verificado"]:::validar
    CLOUD[("VALIDAR · Supabase<br/>migración escrita, no aplicada aquí")]:::validar
    HUB["VALIDAR · Hub Next.js<br/>solo lectura, sin despliegue verificado"]:::validar
    SYNC -->|"HTTPS por lotes"| INGESTA --> CLOUD --> HUB
  end

  PI -->|"evento + outbox en transacción local"| SYNC
```

### Regla de autoridad

El Centro local decide y conserva el estado operacional. El Hub online recibe una
réplica eventualmente consistente; no participa en el camino crítico `SOS → despacho →
aceptación → resolución`.

## 4. Vista 2 · conexiones físicas y energía

En los TTGO, ESP32, SX1276 y el OLED opcional comparten la misma PCB. Los GPIO de
la tabla siguiente son conexiones internas de la placa, no jumpers que deban cablearse.

```mermaid
flowchart TB
  classDef energia fill:#fff3e0,stroke:#b85c00,color:#2c1700
  classDef equipo fill:#e8f5e9,stroke:#2e7d32,color:#172117
  classDef accesorio fill:#f5f5f5,stroke:#5f6368,color:#171717
  classDef riesgo fill:#ffebee,stroke:#b3261e,color:#2c0907

  subgraph NODO[Montaje de cada nodo civil o recurso]
    PB_N["Opción A · power bank 5 V<br/>salida USB"]:::energia
    LIPO["Opción B · LiPo protegida 3.7 V<br/>polaridad JST verificada"]:::energia
    TTGO_N["TTGO T3 V1.6.1<br/>ESP32-PICO-D4 + SX1276"]:::equipo
    ANT_N["Antena 915 MHz"]:::accesorio
    TEL["Celular<br/>sin conexión física"]:::accesorio
    REGLA_N["Usar una ruta de alimentación validada<br/>No energizar sin antena"]:::riesgo

    PB_N -->|"micro-USB · 5 V"| TTGO_N
    LIPO -->|"JST 1.25 · 3.7 V"| TTGO_N
    TTGO_N ---|"SMA"| ANT_N
    TEL <-->|"WiFi 2.4 GHz"| TTGO_N
    REGLA_N -.-> TTGO_N
  end

  subgraph PUESTO[Montaje del centro]
    PWR_PI["Fuente/power bank dedicado<br/>5 V / 3 A continuos para Pi"]:::energia
    PWR_SCREEN["Fuente de pantalla<br/>según modelo y consumo medido"]:::energia
    PI4["Raspberry Pi 4"]:::equipo
    DISPLAY["Pantalla táctil HDMI<br/>modelo pendiente"]:::equipo
    TTGO_GW["TTGO gateway"]:::equipo
    ANT_GW["Antena 915 MHz"]:::accesorio
    WAN["Ethernet, tether USB o<br/>adaptador WiFi para upstream"]:::accesorio
    POWER_RULE["No repartir una fuente 5 V / 3 A<br/>entre Pi y pantalla sin presupuesto medido"]:::riesgo

    PWR_PI -->|"USB-C · energía"| PI4
    PWR_SCREEN -->|"entrada indicada por fabricante"| DISPLAY
    PI4 -->|"HDMI · imagen"| DISPLAY
    PI4 <-->|"USB · táctil"| DISPLAY
    PI4 <-->|"USB-A a micro-USB<br/>datos seriales + energía"| TTGO_GW
    TTGO_GW ---|"SMA"| ANT_GW
    WAN <-->|"red opcional"| PI4
    POWER_RULE -.-> PWR_PI
  end
```

### Matriz de conexiones externas

| Origen | Destino | Cable / medio | Transporta | Estado y regla |
|---|---|---|---|---|
| Power bank del nodo | TTGO de campo | USB-A → micro-USB | 5 V | `ACTUAL`; usar cable corto y probar autoapagado del power bank. |
| LiPo protegida | TTGO de campo | JST 1.25 | 3.7 V | `VALIDAR`; comprobar polaridad del lote antes de conectar. Es alternativa al power bank. |
| TTGO de campo | Antena | SMA | RF 915 MHz | `ACTUAL`; conectar antes de energizar. |
| Celular | TTGO de campo | WiFi 2.4 GHz | Portal y acciones | `ACTUAL`; no hay cable ni LoRa en el celular. |
| Fuente del centro | Raspberry Pi 4 | USB-C | 5 V / 3 A | `ACTUAL`; reserva esta capacidad para la Pi. |
| Raspberry Pi | TTGO gateway | USB-A → micro-USB de datos | 5 V + USB serial | `ACTUAL`; no usar cable de solo carga. |
| Raspberry Pi | Pantalla | HDMI | Video | `VALIDAR`; depende del modelo final. |
| Raspberry Pi | Pantalla | USB | Eventos táctiles | `VALIDAR`; la alimentación de la pantalla debe presupuestarse aparte. |
| TTGO gateway | Antena | SMA | RF 915 MHz | `ACTUAL`; separar físicamente de HDMI, reguladores y metal. |
| Raspberry Pi | Red externa | Ethernet, tether USB o adaptador WiFi | Internet eventual | `PROPUESTO`; no debe compartir el camino crítico offline. |
| Raspberry Pi | RTC compatible | HAT o I2C | Hora persistente | `PROPUESTO`; evita eventos con hora incorrecta después de reiniciar sin internet. |

### Conexiones internas documentadas del TTGO

| Función | GPIO |
|---|---:|
| SX1276 SCK | 5 |
| SX1276 MISO | 19 |
| SX1276 MOSI | 27 |
| SX1276 CS / NSS | 18 |
| SX1276 RST | 23 |
| SX1276 DIO0 | 26 |
| SX1276 DIO1 | 33 |
| OLED SDA, cuando existe | 21 |
| OLED SCL, cuando existe | 22 |

## 5. Vista 3 · arquitectura de software propuesta

El objetivo es conservar módulos profundos: pocas operaciones en su interfaz y la
complejidad de radio, reglas y persistencia localizada detrás de ellas.

```mermaid
flowchart LR
  classDef campo fill:#eef7ee,stroke:#2e7d32,color:#172117
  classDef seam fill:#fff8e1,stroke:#a66a00,color:#2b2100
  classDef centro fill:#eef3ff,stroke:#3559a8,color:#101b35
  classDef validar fill:#fff8e1,stroke:#a66a00,color:#2b2100,stroke-dasharray: 5 4
  classDef futuro fill:#f3efff,stroke:#6a4bbc,color:#201539,stroke-dasharray: 5 4

  subgraph FIRMWARE[Firmware de campo]
    PORTAL["Portal civil<br/>DNS + HTTP/HTTPS + GPS"]:::campo
    RESOURCE_UI["Portal del recurso<br/>misión + acciones"]:::campo
    FIELD_RADIO["Transporte LoRa<br/>frame + CAD + ACK + retry"]:::campo
    PORTAL --> FIELD_RADIO
    RESOURCE_UI --> FIELD_RADIO
  end

  subgraph RADIO_SEAM[Seam de transporte]
    CONTRACT["Interface FieldLink<br/>receive · send_directed<br/>broadcast · health"]:::seam
    SERIAL["Adapter SerialLoRa<br/>SerialGateway + TTGO gateway"]:::seam
    DEMO["Adapter DemoLink<br/>sin hardware"]:::seam
    CONTRACT --- SERIAL
    CONTRACT --- DEMO
  end

  subgraph LOCAL[Centro local]
    HTTP["Adapter HTTP local<br/>rutas versionadas + SSE"]:::centro
    OPS["Módulo Operations<br/>ingest · decide · snapshot"]:::centro
    TRIAGE["Módulo Triage<br/>reglas deterministas"]:::centro
    STORE["Implementación local<br/>SQLite + eventos + estado"]:::centro
    MAP["Módulo Cartography<br/>MBTiles + fallback"]:::centro
    WEB["Dashboard local<br/>HTML/CSS/JS"]:::centro

    HTTP --> OPS
    OPS --> TRIAGE
    OPS <--> STORE
    HTTP --> MAP
    WEB <-->|"HTTP + SSE"| HTTP
  end

  FIELD_RADIO <-->|"LoRa"| SERIAL
  CONTRACT <--> OPS

  subgraph REPLICA[Extensión online futura]
    OUTBOX["ACTUAL · Implementación interna<br/>evento + outbox en una transacción"]:::centro
    SYNC_ADAPTER["ACTUAL · Adapter HTTPS<br/>batch idempotente + backoff"]:::centro
    REMOTE["VALIDAR · Réplica online<br/>código Vercel + migración Supabase"]:::validar
    OUTBOX --> SYNC_ADAPTER --> REMOTE
  end

  STORE -.-> OUTBOX
```

### Interfaces recomendadas

#### Módulo `FieldLink`

Interface externa pequeña:

```text
receive(FieldFrame, LinkMetrics)
send_directed(FieldCommand) -> DeliveryResult
broadcast(FieldCommand) -> TransmissionResult
health() -> LinkHealth
```

La implementación oculta USB serial, correlación de ACK, reintentos, CAD, RSSI/SNR
y reconexión. Este seam ya es real porque existen dos adapters: radio física y demo.

#### Módulo `Operations`

Interface externa pequeña:

```text
ingest(FieldFrame, LinkMetrics) -> IngestResult
decide(OperationalCommand, Actor) -> DecisionResult
snapshot(Query) -> OperationalView
```

La implementación debe ocultar transiciones, idempotencia, reserva durante despacho,
triage, historial, escritura SQLite y creación de eventos sincronizables. El dashboard
no debe conocer frames de radio ni ejecutar SQL.

#### Persistencia

No se propone una interface abstracta para SQLite todavía: solo existe una
implementación necesaria. Se mantiene como seam interno de `Operations`. Introducir un
repositorio genérico ahora aumentaría superficie sin aportar un segundo adapter real.

#### Sincronización

El evento operacional y su fila de outbox ya se escriben en la misma transacción local.
`SyncWorker` reintenta el mismo `event_id`, exige HTTPS y solo confirma IDs que el remoto
devuelve explícitamente. El endpoint remoto ya existe en el worktree, valida lotes y usa la
función idempotente de Supabase; todavía falta verificar migración, secretos, despliegue y
flujo real de extremo a extremo.

## 6. Vista 4 · secuencia crítica de extremo a extremo

```mermaid
sequenceDiagram
  autonumber
  actor C as Civil
  participant N as Nodo civil
  participant G as TTGO gateway
  participant R as Raspberry / Operations
  participant D as SQLite
  actor O as Operador
  participant NR as Nodo recurso
  actor RR as Responsable del recurso

  C->>N: POST SOS por WiFi local
  N->>G: SOS por LoRa
  G-->>N: ACK técnico
  G->>R: RX frame + RSSI + SNR por USB serial
  R->>D: idempotencia + reporte + evento
  D-->>R: commit local
  R-->>O: actualización HTTP/SSE
  O->>R: autorizar despacho
  R->>D: reservar solicitud y recurso
  R->>G: TX DISP por USB serial
  G->>NR: DISP por LoRa
  NR-->>G: ACK técnico
  G-->>R: ACK correlacionado
  R->>D: marcar DESPACHADA + evento
  RR->>NR: aceptar en portal local
  NR->>G: ACC por LoRa
  G-->>NR: ACK técnico
  G->>R: RX ACC
  R->>D: marcar ACEPTADA + evento
  R-->>N: ST de estado, best effort repetido
```

ACK técnico significa “la radio receptora recibió el frame”; no significa que una
persona leyó o aceptó la misión.

## 7. Contratos entre capas

| Seam | Contrato vigente | Garantía | Limitación actual |
|---|---|---|---|
| Celular civil ↔ nodo | WiFi abierto, DNS cautivo, HTTP/HTTPS, `/report`, `/status` | Formulario sin app instalada | HTTPS depende de certificado provisionado y comportamiento del SO. |
| Celular recurso ↔ nodo recurso | WiFi `RECURSO_<ID>`, HTTP `/api/state` y `/api/action` | Control local de la misión | Sin autenticación; cualquier cliente cercano al AP puede accionar. |
| Nodo ↔ gateway | `ORIGEN|DESTINO|TIPO|MSGID|payload` | ACK dirigido, tres intentos, backoff, CAD | Sin cifrado ni autenticación; canal único half-duplex. |
| Gateway ↔ Pi | líneas UTF-8 a 115200 baud | `TX`, `RX`, `ACK`, `TX_SENT`, `TX_ERROR` | Un solo gateway activo; failover no automatizado. |
| HTTP ↔ Operations | rutas `/api/v1/*` y SSE `/api/v1/events` | Validación y comandos explícitos | El frontend y el token para uso en LAN necesitan cerrar su flujo de autenticación. |
| Operations ↔ SQLite | transacciones locales, WAL | Estado persiste tras reinicio | La tarjeta SD de la Pi sigue expuesta a corte abrupto y desgaste. |
| Centro ↔ sincronizador | `sync_outbox` + lotes HTTPS | Evento durable, backoff y ACK explícito | `ACTUAL`; falta probarlo contra un endpoint desplegado. |
| Sincronizador ↔ Hub | evento inmutable con `event_id` | Ingesta idempotente implementada en el worktree | Endpoint, Hub y migración existen como código; falta despliegue y E2E remoto. |

## 8. Hallazgos que cambian la arquitectura

1. **`NODE_ID` está fijo en el firmware civil.** Dos nodos flasheados igual colisionan.
   Antes de desplegar varios, derivar o provisionar un ID único y conservarlo en NVS.
2. **La secuencia del nodo recurso no persiste.** Reinicia en `1`; después de un reboot
   puede chocar con la deduplicación del gateway o del centro.
3. **La deduplicación del gateway solo recuerda el último ID de hasta 16 peers y se pierde
   al reiniciar.** La autoridad final debe deduplicar de forma durable y considerar una
   identidad de sesión/arranque.
4. **Los frames y los portales de recurso no están autenticados.** Un actor cercano puede
   falsificar un nodo o cambiar una misión. Esto es aceptable solo para demo controlado.
5. **El GPS periódico del recurso está definido, pero el firmware vigente solo emite `HB`;
   no captura ni envía `POS` desde el celular.** No debe dibujarse como capacidad actual.
6. **La Raspberry Pi 4 no conserva una hora confiable por sí sola tras un reinicio largo sin
   red.** Como el historial usa timestamps locales, conviene agregar un RTC compatible.
7. **El hotspot del centro no está automatizado en el repositorio.** Una pantalla conectada
   directamente funciona; para varios navegadores hace falta configurar AP/router local.
8. **La pantalla y su consumo siguen sin modelo.** No se puede cerrar el BOM de energía ni
   el CAD del centro hasta medirla.
9. **La protección contra agua, tirones de SMA y cortes de energía no está validada.** Las
   piezas 3D actuales son de prototipo supervisado, no de campo.
10. **El flujo online ya existe como código, pero no está cerrado operacionalmente.** Hay
    outbox, worker, endpoint Vercel, Hub Next.js y migración Supabase; todavía faltan aplicar
    la migración, configurar secretos limitados, desplegar y probar el E2E remoto. El flujo
    offline no debe depender de ellos.

## 9. Arquitectura propuesta por incrementos

### Incremento A · demo confiable

- Un gateway activo y uno de respaldo apagado, con conmutación manual ensayada.
- IDs únicos provisionados en cada placa y etiquetas físicas coincidentes.
- Dos fuentes conocidas: Pi y pantalla; medir consumo durante dos horas.
- Una LiPo protegida o power bank por nodo, nunca una combinación improvisada.
- Un diagrama impreso con los puertos y cables de cada equipo.
- Prueba real `SOS → ACK → despacho → aceptación → resolución` después de cada flasheo.

### Incremento B · prototipo de campo

- RTC, apagado seguro/UPS para Pi y respaldo verificable de SQLite.
- Autenticación de nodos y comandos con clave por dispositivo y contador anti-replay.
- Autenticación del portal de recurso y del dashboard en red local.
- Persistencia de secuencia y boot/session ID en todos los nodos.
- GPS `POS` del recurso implementado y etiquetado con fuente, precisión y antigüedad.
- Carcasa, SMA, temperatura y autonomía validados con el BOM real.

### Incremento C · visibilidad online

- [x] Evento operacional + outbox en la misma transacción SQLite.
- [x] Worker HTTPS opt-in con lotes, backoff y ACK explícito.
- [x] Migración de tablas, RLS cerrado y función idempotente escrita para Supabase.
- [x] Endpoint Vercel que valida el token y llama la función de ingesta.
- [x] Hub Next.js de solo lectura con estado degradado.
- [ ] Aplicar y verificar la migración en un proyecto Supabase aislado.
- [ ] Vista anonimizada de consulta; las tablas base permanecen cerradas.
- [ ] Desplegar y probar `Centro → Vercel → Supabase → Hub` con pérdida y recuperación de red.
- [ ] Recomendaciones remotas vuelven al centro; nunca ejecutan asignaciones directamente.

### Incremento D · escala

- Medir airtime, colisiones y cobertura con múltiples nodos separados físicamente.
- Solo después de medir, decidir entre agregación, más canales/concentrador o mesh.
- No adoptar una librería mesh antes de que dos topologías reales exijan ese seam.

## 10. Cómo convertir este documento en una lámina con imágenes

1. Abrir <https://app.diagrams.net> o draw.io Desktop.
2. Usar `Arrange → Insert → Advanced → Mermaid` y pegar una de las vistas anteriores.
3. Para la lámina ejecutiva, usar la **Vista 1** y reemplazar los bloques por imágenes de:
   - `lora-emergencia/diseno-3d/assets/centro_bandeja.png`
   - `lora-emergencia/diseno-3d/assets/nodo_base.png`
   - `lora-emergencia/diseno-3d/assets/bateria_placa.png`
4. Mantener los nombres de los medios sobre las flechas: `WiFi 2.4 GHz`, `LoRa 915 MHz`,
   `USB serial 115200`, `HTTP + SSE` y `HTTPS eventual`.
5. Exportar SVG para documentación y PNG 2× para la presentación. Conservar el `.drawio`
   en el repositorio si el equipo empieza a editarlo manualmente.

Para un taller rápido puede usarse Excalidraw; para el entregable técnico final, draw.io
es mejor porque alinea conectores, importa Mermaid y conserva el diagrama editable.

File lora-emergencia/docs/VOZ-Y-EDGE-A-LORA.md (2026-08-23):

# Voz y edge hacia LoRa · Dónde corre la transcripción y qué más cabe

Documento accionable para el equipo. Aterriza cada opción al hardware real (LILYGO
T3 V1.6.1, ESP32-PICO-D4, radio SX1276) y al demo actual (portal cautivo
`AYUDA_AQUI_RESCATISTA_911`, cert de `ayuda.homiapp.xyz`, GPS del celular, frame
`ORIGEN|DESTINO|TIPO|MSGID|payload`).

---

## 1. Resumen ejecutivo (5 líneas)

1. La transcripción de voz corre en el navegador del celular, nunca en el ESP32. El
   ESP32-PICO-D4 tiene ~520 KB de SRAM sin PSRAM; el modelo de dictado más pequeño
   (Whisper tiny) pesa ~75 MB. No cabe. Es un hecho físico.
2. En el celular hay dos caminos: Web Speech API on-device de Chrome 139+ en Android
   (usa el motor SODA del sistema, sin enviar audio a la nube) y Vosk-browser con
   `vosk-model-small-es-0.42` (~39 MB) como respaldo 100% offline.
3. El reto real no es correr el modelo. Es servir 40-75 MB sin internet por un SoftAP
   de ~1-2 Mbps. La solución es precargar el bundle en el celular antes del demo.
4. Para meter más texto en LoRa, usa el esquema híbrido: código de plantilla (1-2 B) +
   slots binarios (GPS, n, severidad) + texto libre opcional con Unishox2. Una frase de
   ~116 bytes baja a ~11 bytes.
5. La regla del sistema: procesa rico en el borde (voz, foto, formulario), manda un ID
   corto por LoRa. El audio nunca cruza el radio.

---

## 2. Transcripción de voz: navegador del celular vs ESP32

**Veredicto:** la transcripción corre en el navegador del celular. El ESP32 solo sirve
el HTML/JS del portal (pocos KB) y reenvía los bytes por LoRa. El ESP32 no sirve ningún
modelo de voz.

### Tabla de opciones

| Opción | Dónde corre | Offline | Español | Viabilidad 1-10 | Esfuerzo | Límite principal |
|---|---|---|---|---|---|---|
| Web Speech API on-device (Chrome 139+, Android) | navegador-celular | Parcial | Sí, motor SODA `es-ES`/`es-US` | 6 | Bajo | El paquete de voz offline del SO se descarga UNA vez con internet. iOS/Safari manda audio a Apple, no hay modo on-device. |
| Web Speech API por red (por defecto) | navegador-celular | No | Sí, alta calidad | 2 | Bajo | Manda audio a Google/Apple. Sin internet no transcribe. Solo sirve como fallback con datos. |
| Vosk-browser (`vosk-model-small-es-0.42`) | navegador-celular | Sí | Sí, offline real | 6 | Medio | Servir ~40-50 MB (wasm + modelo) sin internet. Corre bien para dictado corto. |
| Whisper.cpp a WASM | navegador-celular | Sí | Sí, multilingüe | 3 | Alto | tiny ~75 MB (~31 MB con Q5_1). El demo oficial pide desktop rápido. Lento en gama media. |
| transformers.js (Whisper-tiny ONNX) | navegador-celular | Sí | Sí (tiny). Moonshine solo inglés | 3 | Alto | WebGPU irregular en móvil; con WASM la latencia sube. Bundle ~50-120 MB. |

### La verdad sobre el reto offline

- **Web Speech API por defecto NO es offline.** Chrome manda audio a Google, Safari a
  Apple. Chrome 139 (2025) agregó `SpeechRecognition.available({langs, processLocally:true})`
  y `SpeechRecognition.installOnDevice(...)`, que usan el motor SODA del sistema. Ese
  modelo del SO se descarga UNA vez con internet o Google Play; después transcribe sin red.
  En el demo, si el celular nunca instaló el paquete de voz offline en español (el mismo
  del dictado sin internet de Gboard), no funciona sin internet.
- **En iPhone queda descartada para offline.** Safari no tiene modo on-device. Siempre
  manda audio a servidores de Apple. Requiere internet.
- **Los modelos WASM pesan 39-75 MB y no caben en el ESP32.** El ESP32-PICO-D4 tiene 4 MB
  de flash total, ~1-2 MB libres. Hay que servirlos desde la microSD del T3 o precargarlos
  en el cache del navegador antes de perder internet.
- **Aviso de hardware crítico:** en la T3 V1.6.1 la microSD y el radio SX1276 comparten el
  mismo bus SPI. Servir un archivo grande desde SD y transmitir LoRa a la vez chocan.
  Sepáralos en el tiempo: primero el celular baja el bundle, luego la placa opera LoRa.
- **El SoftAP da ~1-2 Mbps útiles y un solo cliente.** Bajar 40-50 MB tarda varios minutos
  y bloquea a otros usuarios.

### Camino recomendado para el demo

Estrategia de dos capas:

- **Capa principal:** Web Speech API on-device de Chrome (Android 139+). El ESP32 no sirve
  nada, la transcripción es en tiempo real, y no viaja audio por el WiFi. Requiere preparar
  el celular con una sola conexión a internet antes del demo.
- **Capa de respaldo 100% offline:** Vosk-browser con `vosk-model-small-es-0.42` (~39 MB),
  servido desde la microSD o precargado en el navegador con un service worker.

**Trade-off honesto:** la capa principal depende de que el celular ya tenga el paquete de
voz del SO. La capa de respaldo no depende del SO, pero exige mover ~40 MB al celular antes
del evento. Whisper WASM y transformers.js quedan descartados para móvil por peso y latencia.
Moonshine queda descartado por ser solo inglés.

Fuentes:
- Web Speech API: https://developer.mozilla.org/en-US/docs/Web/API/SpeechRecognition
- Chrome on-device: https://developer.chrome.com (Intent to Ship On-device Web Speech API, blink-dev)
- Vosk-browser: https://github.com/ccoreilly/vosk-browser
- whisper.cpp: https://github.com/ggml-org/whisper.cpp
- transformers.js: https://huggingface.co/docs/transformers.js

---

## 3. ESP32: por qué la transcripción libre NO corre, y qué SÍ

**Veredicto:** la transcripción libre de voz dentro del ESP32-PICO-D4 es imposible. Lo
único realista en la placa es keyword spotting de N comandos fijos con TensorFlow Lite
Micro, y eso pide un micrófono I2S extra que el T3 no trae.

### Por qué la transcripción libre no corre

- El PICO-D4 no tiene PSRAM útil. Sin PSRAM quedan ~520 KB de SRAM. El WiFi SoftAP + el
  portal HTTPS + LoRa ya ocupan buena parte de esa SRAM.
- Whisper tiny son ~39 M parámetros, ~75 MB en int8. No cabe en 520 KB ni de lejos.
- No existe ningún modelo de dictado abierto que corra en este SoC. Es un hecho físico,
  no una limitación de esfuerzo.

### Qué SÍ se puede

- **Keyword spotting con TensorFlow Lite Micro.** El ejemplo `micro_speech` usa un modelo
  de ~18 KB. Puedes entrenar un modelo propio con 4-10 comandos en español (AYUDA, ATRAPADO,
  HERIDO, AGUA, FUEGO), ~18-50 KB en int8. Entra audio del micrófono I2S por I2S, sale la
  clase detectada, la mapeas a un `TIPO` del frame LoRa.
- **Hardware que falta:** el T3 no tiene micrófono. Necesitas un INMP441 I2S (~2 USD), 3
  pines GPIO libres + 3.3V. Audio a 16 kHz, 16 bit, mono.
- **Precisión:** razonable solo con vocabulario cerrado y poco ruido. En ruido de terremoto
  real la precisión baja y hay riesgo alto de falsos positivos.

### Qué NO aplica

- **ESP-SR de Espressif (WakeNet / MultiNet):** descartado. Pide PSRAM, apunta al ESP32-S3
  con SIMD, y solo soporta chino e inglés. No hay modelo en español.

### Tabla ESP32

| Opción | Dónde | Offline | Español | Viabilidad | Esfuerzo | Nota |
|---|---|---|---|---|---|---|
| Botones de comandos en el portal (sin STT) | navegador-celular | Sí | Perfecto | 10 | Bajo | Cero mic, cero RAM en el ESP32. Ya es el patrón del demo. |
| TFLM keyword spotting (N comandos) | esp32 | Sí | Sí, entrenando muestras propias | 5 | Alto | ~18-50 KB. Pide INMP441. Compite por SRAM con WiFi+HTTPS+LoRa. |
| ESP-SR WakeNet (wake word) | esp32 | Sí | No | 2 | Alto | Pide PSRAM. Solo chino/inglés. Descartado. |
| ESP-SR MultiNet (comandos) | esp32 | Sí | No | 1 | Alto | Pide PSRAM y ESP32-S3. Descartado. |
| Whisper libre en el ESP32 | esp32 | Sí | Irrelevante | 1 | Alto | Físicamente imposible. No lo intentes. |

Fuentes:
- esp-tflite-micro: https://github.com/espressif/esp-tflite-micro
- esp-sr: https://github.com/espressif/esp-sr

**Recomendación para el ESP32:** NO pongas STT en la placa. Usa los botones de comandos que
el portal ya sirve. Respeta el frame `ORIGEN|DESTINO|TIPO|MSGID|payload` con cero riesgo.

---

## 4. Enviar texto por LoRa: esquema recomendado

**Esquema recomendado:** híbrido = código de plantilla (1-2 B) + slots binarios
(n=1B, GPS=8B, severidad=1B) + texto libre opcional comprimido con Unishox2.

### Ejemplo literal con una frase española

Frase `S`:

```
Hay dos personas atrapadas bajo una losa de concreto en la calle Bolivar numero 45,
una sangra mucho, envien grua
```

~112 caracteres, 4 tildes (Bolívar, número, envíen, grúa).

| Codificación | Bytes | Reducción vs crudo |
|---|---|---|
| Crudo UTF-8 | ~116 | 0% |
| Transliteración (quitar tildes) + Unishox2 | ~54 | ~53% |
| Unishox2 | ~58 | ~50% |
| Plantilla + slots | ~11 | ~90% |

### Cómo se arman los 11 bytes

```
0x07  n=2   [GPS lat/lon: 2x int32 escalado 1e7]   sev=hemorragia
1 B   1 B   8 B                                     1 B
```

- `0x07` = código de la plantilla "Hay {n} personas atrapadas bajo losa de concreto,
  {sev}, envien grua".
- Si usas texto de calle en vez de GPS, "Bolivar 45" agrega ~10 bytes.

### Por qué así

- **Un código de 1 byte reconstruye una frase canónica de 40-80 caracteres** en el centro.
  256 códigos con 1 byte, 65536 con 2 bytes. El diccionario es el mismo array compilado en
  el firmware y en el centro, indexado por el código.
- **Unishox2** comprime frases latinas a ~40-55% del original. Corre en ESP32 (repo
  `siara-cc/Unishox2`, un solo `.c/.h`, ~20 KB de flash) y en el navegador (port JS/WASM).
  El celular comprime, el ESP32 reenvía los bytes, el centro descomprime.
- **Transliteración antes de comprimir:** `String.normalize('NFD')` quita diacríticos. Pasa
  cada tilde de 2 bytes a 1 byte, mejora Unishox2, y ayuda al match con plantillas ASCII.
- **Smaz, gzip y brotli son peores aquí.** Smaz usa codebook en inglés y a veces expande el
  español. gzip tiene ~18 bytes de cabecera fija. Brotli deja ~100-110 bytes en 120 bytes
  de entrada y su encoder pesa mucho en ESP32.

### Airtime a SF7 (BW 125 kHz, CR 4/5)

| Mensaje | Bytes | Airtime |
|---|---|---|
| Plantilla + slots | ~15 | ~43 ms |
| Unishox2 | ~62 | ~113 ms |
| Paquete lleno | 200 | ~318 ms |

Mensajes cortos bajan airtime y colisiones entre las 2 placas. El multi-paquete (fragmentar
con `MSGID + frag_index + frag_total`) queda solo como último recurso: 2-3 paquetes de 200
bytes cuestan ~640-950 ms y suman reintentos.

Fuente: https://github.com/siara-cc/Unishox2

---

## 5. Qué más bajo el mismo principio (edge -> texto corto -> LoRa)

El cuello de botella del sistema es el canal LoRa, no el CPU del celular. Meshtastic frena
sobre 25% de utilización = ~15 s de aire por minuto para TODA la malla. Por eso las ideas
que REDUCEN mensajes o meten más info por byte valen más que la ML vistosa. Lista priorizada:

### Nivel 1 · Alto valor, esfuerzo bajo, 100% offline

1. **Triage por reglas + plantillas + texto predictivo.** Valor: colapsa la entrada rica a
   `plantilla_id` + categoría + severidad, sin modelo de ML. Offline: total, léxico JS de
   ~2-5 KB en español. LoRa: cabe en 30-40 bytes. Ataca el dolor medido (Haití: solo 4.5%
   de 80.000 SMS fue accionable).
2. **De-duplicación en el borde.** Valor: el celular hashea (categoría, GPS redondeado ~50 m,
   ventana de tiempo). Si ya hay un evento igual reciente, suprime el envío o lo marca
   "+1 confirma". Offline: sí, lógica interna. LoRa: elimina paquetes, protege el techo de 25%.
3. **Fusión de prioridad a 1 byte.** Valor: combina categoría + severidad + espera + flags
   (niño/herido/atrapado) en UN score de triage. El centro ordena la cola por ese byte.
   Offline: sí, cálculo numérico. LoRa: 1 byte lleva la decisión completa.

### Nivel 2 · Alto valor, esfuerzo bajo-medio

4. **Phrasebook por ID (traducción offline).** Valor: catálogo cerrado de ~200 frases; LoRa
   manda solo `frase_id` (1-2 B); cada receptor la muestra en SU idioma (español, inglés,
   wayuu, embera). La traducción es un lookup local, no un modelo. Offline: sí. LoRa: 1-2 B.
5. **Plus code / QR + geocodificación inversa local.** Valor: `BarcodeDetector` nativo (o
   jsQR ~50 KB) lee un QR pre-impreso en albergues; `open-location-code` (~15 KB) decodifica
   un plus code offline; una tabla de barrios convierte GPS a "Barrio X". Offline: sí. LoRa:
   cabe en los 8 bytes de lat/lon que ya se mandan.
6. **Codificación inteligente de GPS (geohash/delta).** Valor: posición como delta desde un
   punto base de sesión o geohash truncado. Baja de 8 a 3-5 bytes con ~10-30 m de precisión.
   Offline: sí. LoRa: libera espacio y reduce airtime.

### Nivel 3 · ML que cabe en el edge

7. **Voz -> keyword spotting offline (speech-commands TFJS).** Valor: reconoce palabras
   sueltas para usuarios que no escriben o tienen las manos ocupadas. Offline: sí, ~1-4 MB,
   cabe en flash del ESP32 sin microSD. LoRa: mapea la palabra a un enum de 1 byte. Requiere
   re-entrenar el set en español (el base viene en inglés).
8. **Compresión con diccionario de dominio.** Valor: para el campo de texto libre corto,
   diccionario estático de términos de desastre + Huffman en JS puro. Offline: sí. LoRa: mete
   más caracteres útiles en ~15-20 bytes. Ganancia modesta si el texto ya es corto.

### Nivel 4 · Trabajo futuro (no para 72h)

9. **Foto -> etiqueta "persona" (coco-ssd/mobilenet).** COCO no tiene clases "fuego" ni
   "derrumbe": solo "persona/carro/camión". Los modelos (16-28 MB) exigen microSD y tardan
   20-60 s en bajar por SoftAP. El humano tocando la categoría es más fiable.
10. **OCR de nota/cédula (Tesseract.js).** Útil para reunificación, pero OCR de manuscrito es
    poco fiable y el paquete `spa` pesa ~10 MB + ~2 MB de runtime, requiere microSD.
11. **pHash de foto de desaparecido.** Hash de ~8-16 bytes; da muchos falsos positivos con
    caras. Valor de concepto, no operativo en 72h.
12. **Shake-to-SOS por acelerómetro.** `DeviceMotion` (habilitado por el HTTPS del portal)
    dispara un SOS con el último GPS. Falsos disparos por movimiento normal. Valor bajo frente
    a un botón grande en pantalla.

Fuentes:
- speech-commands: https://github.com/tensorflow/tfjs-models/tree/master/speech-commands
- open-location-code: https://github.com/google/open-location-code
- coco-ssd: https://github.com/tensorflow/tfjs-models/tree/master/coco-ssd
- tesseract.js: https://github.com/naptha/tesseract.js

---

## 6. Recomendación para el demo

**Una feature de voz que suma wow sin romper el demo actual:** agrega un botón de dictado en
el portal cautivo que ya sirve la placa. El celular ya abre `AYUDA_AQUI_RESCATISTA_911`, ya
da GPS con `navigator.geolocation`, y el cert de `ayuda.homiapp.xyz` ya habilita el micrófono
por HTTPS (`getUserMedia`). El botón usa Web Speech API on-device de Chrome. El rescatista
dicta "hay dos atrapados en el sótano", el JS extrae categoría (RESCATE) y detalle, arma el
mismo payload `SOS` que ya usan los botones, y el ESP32 lo emite por LoRa sin cambios.

### Por qué esta y no otra

- Reutiliza el frame `SOS|cat|pri|lat|lon|lugar|detalle` que ya existe. Cero cambios en el
  firmware ni en el protocolo.
- La voz es solo otra forma de llenar el formulario. Si falla, los botones actuales siguen ahí.
- El audio nunca cruza el radio. Solo entra el texto corto al payload.

### Plan mínimo

1. Agrega un botón "Dictar" junto a los botones de categoría en el HTML del portal.
2. Al tocarlo, `SpeechRecognition` con `lang = 'es-ES'` y `processLocally: true`. Muestra el
   texto reconocido en un campo editable.
3. Un léxico JS de ~2-5 KB mapea palabras clave a `cat` (atrapado/rescate -> RESCATE,
   herido/sangra -> MEDICO, fuego -> FUEGO) y a `pri` (inconsciente/atrapado -> 0-1).
4. El texto reconocido va al slot `detalle`. El GPS ya viene de `navigator.geolocation`.
5. El POST del portal arma el mismo `SOS` de siempre. El ESP32 lo reenvía.

### Preparación previa (obligatoria)

- En el celular de prueba (Android, Chrome 139+), instala el paquete de voz offline en español
  con una conexión a internet ANTES del demo. Verifica el dictado sin internet de Gboard.
- Ten el respaldo Vosk precargado en el navegador por si el motor del SO no está.
- Regla del demo: durante el evento no debe viajar ningún MB por el SoftAP lento.

---

## 7. Riesgos y límites honestos

- **Web Speech on-device depende del SO.** Si el celular no instaló el paquete de voz offline
  en español, no transcribe sin internet. Prepáralo antes del demo con una conexión.
- **iPhone no sirve para voz offline.** Safari manda audio a Apple. Usa Android para la voz.
- **Servir el modelo sin internet es el cuello de botella.** El SoftAP da ~1-2 Mbps. Bajar
  40-50 MB tarda minutos y bloquea a otros. Precarga el bundle en el celular, no lo bajes en vivo.
- **microSD y LoRa comparten el bus SPI en la T3 V1.6.1.** Servir un archivo grande desde SD y
  transmitir LoRa a la vez chocan. Sepáralos en el tiempo.
- **En portal cautivo el celular suele ser un dispositivo nuevo sin cache.** No asumas cache
  previo. El respaldo Vosk necesita microSD o precarga explícita.
- **Ruido de terremoto baja la precisión de la voz.** El dictado de frases cortas rinde mejor
  que el de frases largas. Deja siempre los botones como respaldo.
- **STT en el ESP32 es frágil.** Keyword spotting solo cubre vocabulario cerrado, pide un
  INMP441 extra, compite por SRAM con WiFi+HTTPS+LoRa, y tiene riesgo alto de falsos positivos.
- **La ML de foto no distingue fuego ni derrumbe.** COCO solo da "persona" de forma fiable.
  No prometas detección de incendio o colapso.
- **El diccionario de plantillas debe estar sincronizado** en firmware y centro. Un código sin
  su frase en el centro produce un mensaje ilegible.

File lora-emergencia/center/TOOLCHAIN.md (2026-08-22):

# Toolchain y técnicas de desarrollo

Guía reproducible para preparar una Mac o Raspberry Pi, compilar los firmwares y verificar el command center. Compilar no modifica ninguna placa; `--upload` sí escribe firmware en el dispositivo seleccionado.

## 1. Instalar Arduino CLI

macOS:

```bash
brew install arduino-cli
```

Comprueba la instalación:

```bash
arduino-cli version
```

## 2. Configurar el core ESP32

```bash
arduino-cli config init
arduino-cli config add board_manager.additional_urls https://raw.githubusercontent.com/espressif/arduino-esp32/gh-pages/package_esp32_index.json
arduino-cli core update-index
arduino-cli core install esp32:esp32
```

El core es una descarga grande. Solo se instala una vez por máquina.

## 3. Instalar RadioLib

```bash
arduino-cli lib install RadioLib
arduino-cli lib list
```

## 4. Identificar las placas

Conecta las TTGO con antena 915 MHz y cable USB de datos:

```bash
arduino-cli board list
```

Puertos habituales:

- macOS: `/dev/cu.usbserial-...`
- Raspberry Pi/Linux: `/dev/ttyUSB0`

Nunca energices o transmitas con una placa sin antena.

## 5. Compilar sin flashear

Desde `lora-emergencia/`:

```bash
arduino-cli compile --fqbn esp32:esp32:ttgo-lora32 gateway_bidir
arduino-cli compile --fqbn esp32:esp32:ttgo-lora32 nodo_recurso
```

Esta es la verificación mínima después de cambiar firmware.

## 6. Compilar y flashear

```bash
./scripts/flash.sh gateway_bidir /dev/cu.usbserial-GATEWAY
./scripts/flash.sh nodo_recurso /dev/cu.usbserial-RECURSO
```

El script fija `UploadSpeed=115200`, que es más estable que 921600 en estas placas.

## 7. Monitor serial

```bash
./scripts/monitor.sh /dev/cu.usbserial-GATEWAY
```

Baud del proyecto: `115200`.

## 8. Command center

```bash
cd center
python3 -m unittest -v
python3 center.py --demo
```

Con hardware:

```bash
pip install -r requirements.txt
python3 center.py /dev/cu.usbserial-GATEWAY --db center.db
```

Abre `http://localhost:8080`. En Raspberry Pi, otros equipos de la misma red local pueden usar `http://<ip-de-la-pi>:8080`.

## Técnicas de firmware aplicadas

### Recepción no bloqueante

El gateway y el nodo recurso usan:

1. `setPacketReceivedAction()` para registrar una interrupción mínima.
2. `startReceive()` para mantener el SX1276 escuchando.
3. Una bandera `volatile` que el `loop()` consume fuera de la interrupción.
4. `readData()` únicamente desde el `loop()`, nunca desde la ISR.

Esto permite atender radio, USB serial y servidor web sin quedar detenido dentro de `receive()`.

### Cambio seguro RX → TX → RX

Antes de transmitir:

1. Se deshabilita la bandera de recepción.
2. Se limpia la acción de interrupción.
3. La radio pasa a `standby()`.
4. Se ejecuta CAD y se transmite.
5. Se restaura la interrupción y `startReceive()`.

La secuencia evita interpretar el fin de una transmisión propia como un paquete recibido.

### CAD

`scanChannel()` comprueba si el canal parece libre antes de transmitir. Reduce colisiones, pero no garantiza entrega; por eso siguen siendo necesarios ACK, timeout, reintentos e idempotencia.

### Serial estructurado

La Raspberry y el gateway intercambian líneas terminadas en `\n`:

```text
TX|<frame>
RX|<frame>|RSSI:x|SNR:y
ACK|origin|destination|message_id|RSSI:x|SNR:y
TX_SENT|origin|destination|type|message_id
TX_ERROR|message_id|code
```

Los logs humanos usan otros prefijos y no forman parte del contrato.

### Verificación proporcional

- Python: `compileall`, pruebas unitarias y arranque HTTP en modo demo.
- Firmware: compilación de cada sketch con el FQBN real.
- Hardware: prueba end-to-end con dos placas; la compilación no demuestra RF, ACK ni coexistencia WiFi/LoRa.

## Problemas frecuentes

- `arduino-cli: command not found`: instala la CLI y abre una terminal nueva.
- `platform not installed`: ejecuta `arduino-cli core install esp32:esp32`.
- `RadioLib.h: No such file`: ejecuta `arduino-cli lib install RadioLib`.
- Puerto ausente: cambia el cable o revisa el driver USB-serial.
- Upload inestable: usa el script con velocidad 115200.
- Compila pero no comunica: comprueba todos los parámetros LoRa en ambos sketches.

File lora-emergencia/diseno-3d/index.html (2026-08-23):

● WOKI · piezas 3D

Lista de compraPruebasOpenSCAD

Inventario

Prototipo beta v0.3
diseño verificado

Control de fabricación

# Inventario técnico

Piezas, medidas, cantidades y archivos listos para laminar.

CAD v0.3 · 2026-08-23

8Geometrías verificadas

16Archivos STL + 3MF

9Objetos físicos por kit

v0.3Primera iteración beta

## Centro maestro

Raspberry Pi 4 + pantalla + TTGO gateway + energía móvil.

4 geometrías · 5 impresiones

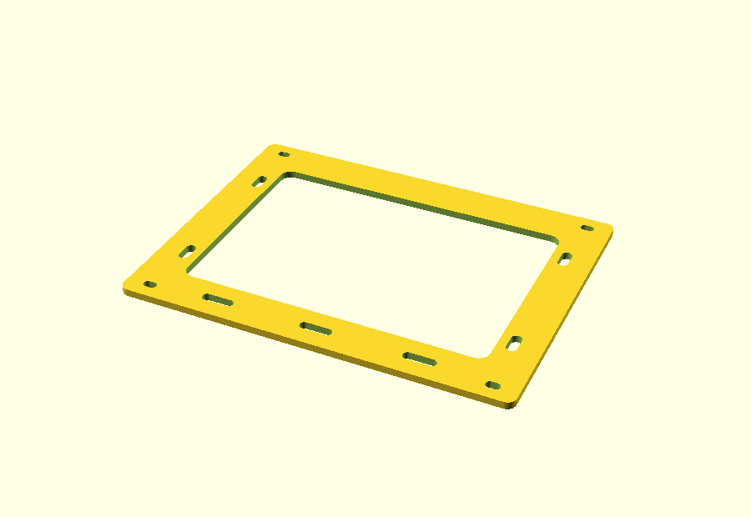
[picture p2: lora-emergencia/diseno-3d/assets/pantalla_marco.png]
Marco de pantalla
CTR-01 

X170,0 mm

Y129,0 mm

Z3,2 mm

### Marco trasero de pantalla

Beta v1

Patrón ranurado para Waveshare 7inch HDMI LCD (C), ventana de ventilación y gestión de cables.

Cantidad1

Patrón148,9 × 114,96

MaterialPETG

SoportesNo

STL3MF

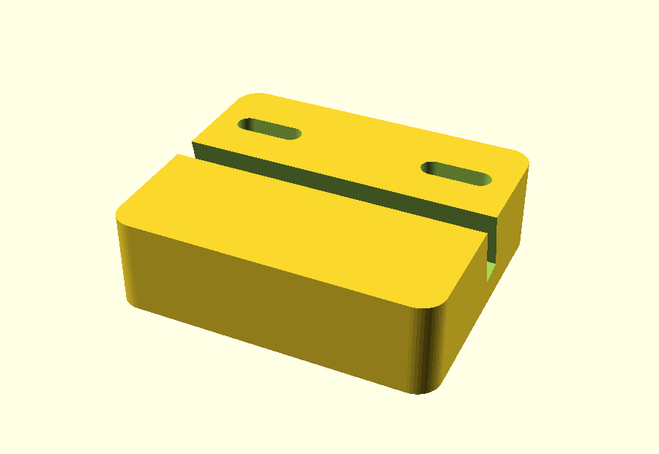
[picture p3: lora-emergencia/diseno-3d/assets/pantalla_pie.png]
Pie de pantalla
CTR-02 

X54,0 mm

Y46,0 mm

Z16,0 mm

### Pie inclinado

CAD listo

Canal a 12° para el marco. Se imprimen dos unidades y pueden asegurarse con bridas.

Cantidad2

Canal4,4 mm

MaterialPETG

SoportesNo

STL3MF

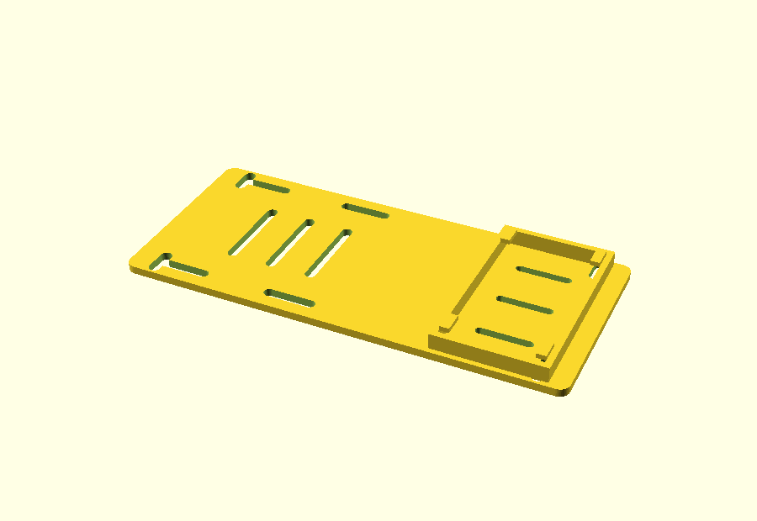
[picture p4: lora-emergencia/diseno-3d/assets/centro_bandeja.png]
Bandeja de electrónica
CTR-03 

X168,0 mm

Y76,0 mm

Z10,65 mm

### Bandeja Pi + TTGO

CAD listo

Sujeta la carcasa de la Raspberry con correas e integra un dock ventilado para el TTGO maestro.

Cantidad1

Fijación Pi2 correas

GatewayTTGO V1.6.1

SoportesNo

STL3MF

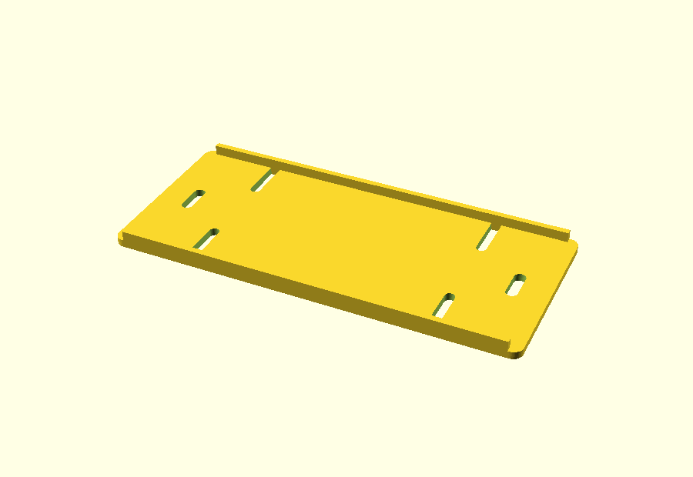
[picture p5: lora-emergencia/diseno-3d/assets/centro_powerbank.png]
Cuna de power bank
CTR-04 

X161,2 mm

Y72,2 mm

Z7,0 mm

### Cuna power bank

Beta v1

Rieles abiertos para Baseus Adaman 65 W / 20 Ah; conserva puertos y usa dos correas.

Cantidad1

Banco objetivo154 × 65 × 27

Correa≤ 20 mm

SoportesNo

STL3MF

## Nodo de campo

Prototipo abierto para demo y bandeja protegida para despliegue.

4 geometrías · 4 impresiones

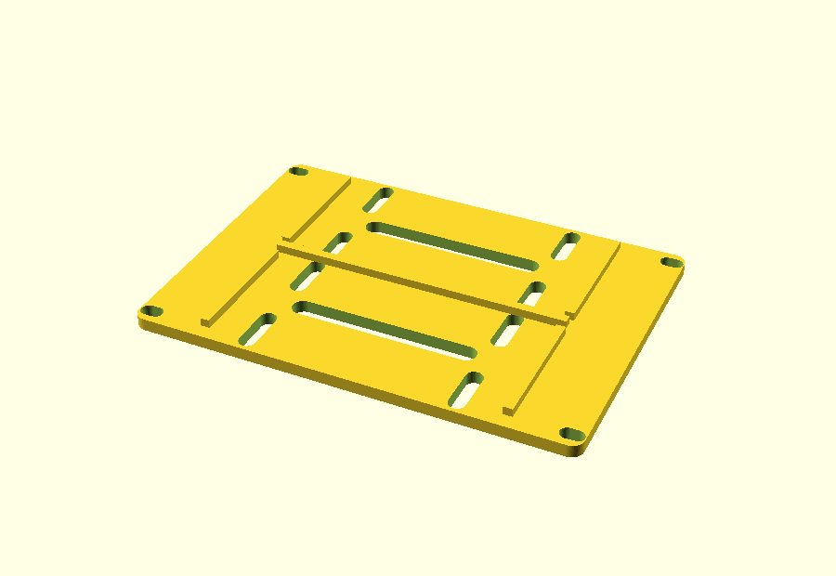
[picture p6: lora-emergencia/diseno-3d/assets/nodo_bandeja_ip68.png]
Bandeja IP68
NOD-01 

X106,0 mm

Y75,0 mm

Z5,0 mm

### Bandeja interna IP68

CAD listo

Organiza TTGO y batería en lados separados dentro de Hammond 1554F2GYCL.

Cantidad1

InsertosM3 · 100 × 68

Caja119 × 89 × 61

SoportesNo

STL3MF

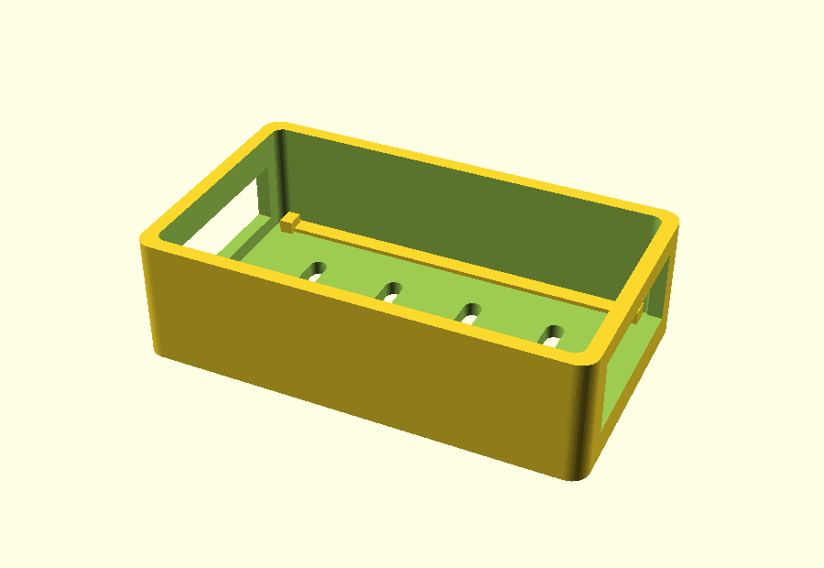
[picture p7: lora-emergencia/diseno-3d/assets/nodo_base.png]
Base TTGO demo
NOD-02 

X72,2 mm

Y42,2 mm

Z20,5 mm

### Base TTGO · demo

CAD listo

Rieles, ventilación y ventanas amplias. Es una pieza interior, no una carcasa impermeable.

Cantidad1

Holgura0,7 mm/lado

Pared2,4 mm

SoportesNo

STL3MF

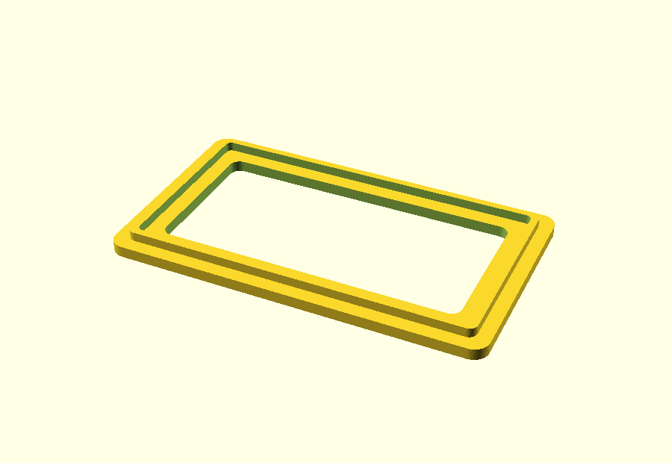
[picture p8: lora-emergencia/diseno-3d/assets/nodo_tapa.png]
Tapa TTGO demo
NOD-03 

X72,2 mm

Y42,2 mm

Z4,0 mm

### Tapa abierta · demo

CAD listo

Mantiene OLED y botones visibles. Prioriza acceso durante desarrollo, no sellado.

Cantidad1

Labio1,95 mm

MaterialPETG

SoportesNo

STL3MF

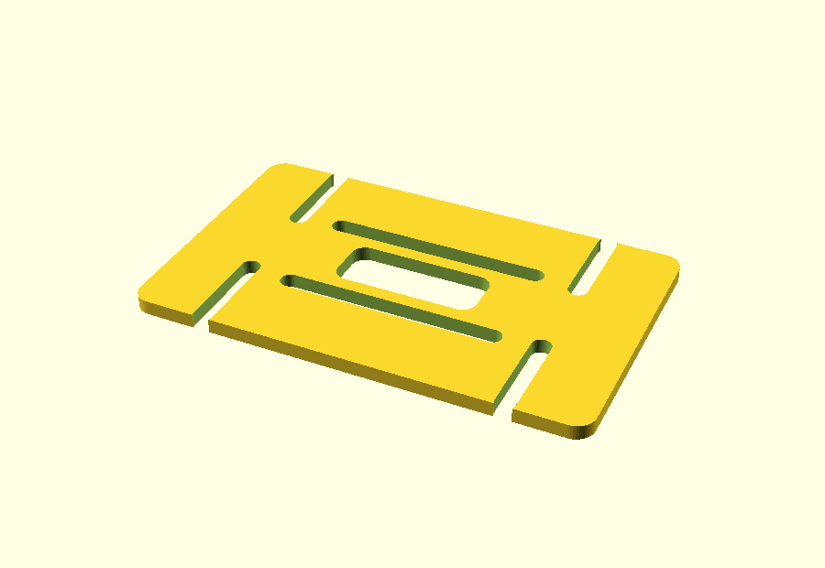
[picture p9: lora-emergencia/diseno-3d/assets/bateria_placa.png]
Placa de batería demo
NOD-04 

X94,0 mm

Y58,0 mm

Z3,0 mm

### Placa de batería · demo

CAD listo

Montaje universal por velcro para validar energía sin encerrar ni comprimir el pack.

Cantidad1

Correa≤ 20 mm

MaterialPETG

SoportesNo

STL3MF

## Componentes no imprimibles

Referencias elegidas para que el conjunto sea reproducible.

Ver compra detallada

Equipo | Componente | Especificación | Estado
Centro | Pantalla | Waveshare 7inch HDMI LCD (C), candidata visual | REFERENCIA BETA
Centro | Protección / térmica | Carcasa RPi4 + ventilador oficiales | SELECCIONADO
Centro | Energía | Baseus Adaman 65 W, 20 Ah, USB-C 5 V/3 A | SELECCIONADO
Nodo | Caja | Hammond 1554F2GYCL, policarbonato IP68 | SELECCIONADO
Nodo | Batería | 1S protegida, 2.000 o 4.400 mAh | 2 OPCIONES
Nodo | Pasamuros | Amphenol 095-902-569-006, SMA IP67, RG-316 | SELECCIONADO

## Estado del prototipo

Resumen de fabricación y próxima iteración.

### Base técnica completa

El sistema ya reúne piezas, referencias, cotas, cableado y criterios de sustitución. Las ocho mallas pasan validación geométrica.

- 8 geometrías verificadas.
- STL y 3MF listos para laminar.
- Componentes y medidas documentados.

### Validación física v1

La siguiente iteración concentra las comprobaciones de integración con el hardware real.

- Ajuste de pantalla y componentes.
- Autonomía y temperatura del conjunto.
- Radio y sellado con la caja cerrada.

## Documentos

Fabricación, abastecimiento y pruebas.

MódulosImpresiónCompraVerificación

WOKI · inventario técnico CAD v0.3 · prototipo beta

## Pieza 3D

Reiniciar vista ×

Cargando geometría…

Arrastrar: rotar · Rueda/pellizco: zoom · Clic derecho/dos dedos: mover

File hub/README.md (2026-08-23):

# WOKI Hub

Réplica online de solo lectura para los eventos producidos por el Centro local.

## Ejecutar

```bash
bun install
bunx vercel link
bunx vercel env pull .env.local --environment=development --yes
# Añade SUPABASE_SERVICE_ROLE_KEY a .env.local desde Supabase > API Keys.
bun run dev
```

Variables requeridas:

- `SUPABASE_URL`: URL del proyecto WOKI.
- `SUPABASE_SERVICE_ROLE_KEY`: clave privada de servidor; nunca llega al navegador.
- `WOKI_SYNC_TOKEN`: secreto independiente compartido con el Centro local.
- `ELEVENLABS_API_KEY`: clave privada para narrar los pasos.
- `ELEVENLABS_VOICE_ID`: voz elegida en ElevenLabs para la guía en español.

## Contratos

- `POST /api/sync`: ingesta autenticada por Bearer y confirmación por `event_id`.
- `GET /api/health`: indica si el runtime está configurado.
- `/`: acceso referencial sin autenticación; redirige al onboarding.
- `/setup`: onboarding visual de nueve pasos; inicia en simulación, explica la topología, embebe el visor 3D, no modifica dispositivos y permite copiar la guía para ChatGPT o Claude.
- `/command-center`: overview de la réplica online, con mapa y refresco cada 15 segundos.
- `/command-center/requests`: cola sincronizada de solicitudes con filtros.
- `/command-center/resources`: disponibilidad, señal y última conexión de los nodos.
- `/command-center/network`: trazabilidad de eventos entre la operación local y la réplica.
- `/command-center/broadcasts`: seguimiento de broadcasts y confirmaciones; su envío sigue siendo local.
- `/command-center/safe-people`: registros anonimizados y coordenadas aproximadas.
- `GET /api/onboarding/voice?step=...`: narración española con Eleven Multilingual v2.

El onboarding no forma parte del menú operacional. Desde `Configuración` se puede volver a abrir
desde el paso 1 cuando sea necesario preparar otro kit. Su encabezado permite copiar un prompt
autocontenido para que ChatGPT o Claude acompañen tanto a una persona técnica como no técnica. El
paso `Reconoce el kit` agrega otro prompt específico para comparar stock, compatibilidad, tiendas
cercanas y costo total en la moneda local, sin incluir productos agotados.

El endpoint acepta reintentos. Supabase aplica idempotencia mediante
`woki_ingest_event`; una confirmación duplicada sigue siendo válida para vaciar la outbox local.
El Centro redondea las posiciones antes de enviarlas y omite nombre/documento de personas a salvo.

La clave de ElevenLabs solo existe en el servidor. Los audios determinísticos por paso se cachean
para no consumir créditos cada vez que un operador repite una instrucción. Si el proveedor no está
configurado, la voz usa el sintetizador español del dispositivo.

El mapa online descarga mosaicos de OpenStreetMap porque el Hub sí dispone de internet. La
cartografía offline permanece en la laptop local y no se sube a Supabase.

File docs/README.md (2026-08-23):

# Guía de documentación

La documentación está ordenada por la pregunta que responde. El principio transversal es **local-first**: internet amplía WOKI, pero nunca habilita la operación básica.

## 1. Entender el valor

1. [`../README.md`](../README.md): propuesta, estado y forma de probar WOKI.
2. [`../project-description.md`](../project-description.md): relato corto para jurados.
3. [`../MISSION.md`](../MISSION.md): objetivo y prioridades.
4. [`../CONTEXT.md`](../CONTEXT.md): lenguaje del dominio.

## 2. Entender la arquitectura

1. [`ARQUITECTURA-CONEXIONES.md`](ARQUITECTURA-CONEXIONES.md): topología completa, conexiones eléctricas, módulos de software y diagramas editables.
2. [`ONLINE-SYNC.md`](ONLINE-SYNC.md): relación entre Centro local, Hub online y sincronización.
3. [`adr/0001-local-first-con-replica-online.md`](adr/0001-local-first-con-replica-online.md): decisión y trade-offs.
4. [`../lora-emergencia/center/ARCHITECTURE.md`](../lora-emergencia/center/ARCHITECTURE.md): módulos internos del command center.
5. [`../lora-emergencia/docs/PROTOCOLO-MINIMO.md`](../lora-emergencia/docs/PROTOCOLO-MINIMO.md): protocolo vigente del demo.

## 3. Ejecutar y demostrar

1. [`OPERAR-SINCRONIZACION.md`](OPERAR-SINCRONIZACION.md): guía para que Juan opere la laptop del Centro y valide offline → online.
2. [`../lora-emergencia/docs/PLAN-DEMO.md`](../lora-emergencia/docs/PLAN-DEMO.md): guion de tres minutos.
3. [`../lora-emergencia/center/README.md`](../lora-emergencia/center/README.md): ejecutar el centro.
4. [`../lora-emergencia/center/CENTRO.md`](../lora-emergencia/center/CENTRO.md): operación Raspberry ↔ gateway ↔ nodos.
5. [`../lora-emergencia/docs/PORTAL-CAUTIVO-E2E.md`](../lora-emergencia/docs/PORTAL-CAUTIVO-E2E.md): límites reales de portal y GPS.

## 4. Referencia e investigación

- `lora-emergencia/docs/PROTOCOL.md` documenta el protocolo inicial y es **legacy**.
- `lora-emergencia/docs/OSS-Y-PROTOCOLO.md` y `VOZ-Y-EDGE-A-LORA.md` son investigación, no capacidades implementadas.
- `lora-emergencia/diseno-3d/` contiene los módulos físicos y sus pendientes de validación dimensional.

## Regla editorial

Cada capacidad debe marcarse como una de estas:

- **Implementada:** existe en código y tiene verificación local.
- **Validada en hardware:** además existe evidencia con placas o teléfonos reales.
- **Definida:** existe una decisión o diseño, pero falta implementación.
- **Investigada:** se evaluó como alternativa; no forma parte del producto actual.

No usar “funciona” para una capacidad que solo está definida o investigada.

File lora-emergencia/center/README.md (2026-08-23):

# Command Center

Centro de operaciones offline para la red de emergencia LoRa. Esta carpeta contiene el prototipo existente (`center.py`) y las definiciones que guiarán su evolución hacia una aplicación operativa para Raspberry Pi.

## Objetivo

Permitir que un operador reciba y gestione reportes, visualice recursos en un mapa offline, asigne recursos a zonas o incidentes y envíe comunicaciones masivas a los nodos LoRa.

## Arquitectura acordada

```text
Celular del recurso o civil
        │ WiFi local
Nodo TTGO LoRa32
        │ LoRa 915 MHz
TTGO gateway activo ─── TTGO gateway de respaldo
        │ USB serial
Raspberry Pi
        ├── recepción y transmisión de radio
        ├── aplicación y reglas operativas
        ├── SQLite
        ├── cartografía offline
        └── dashboard web local
```

La Raspberry Pi contiene el command center. El TTGO central funciona como gateway especializado y no aloja el dashboard.

## Stack propuesto

| Capa | Elección | Motivo |
|---|---|---|
| Radio y backend | Python stdlib + pyserial opcional | Compatible con Python 3.9 y operación local sin servicios externos |
| Persistencia | SQLite | Archivo local, sin servidor externo y apto para operación offline |
| Interfaz | HTML, CSS y JavaScript vanilla | SPA local sin compilación, CDN ni conexión a internet |
| Mapa | Leaflet + VectorGrid local + Shortbread MBTiles | Calles offline de Bogotá; OSM raster online conserva autorización explícita por pestaña |
| Despliegue | Raspberry Pi | Ejecuta aplicación, almacenamiento y servidor web local |

El servidor expone la API versionada bajo `/api/v1` y mantiene temporalmente los endpoints legacy del prototipo.

## Capacidades previstas

- Recibir, validar, deduplicar y conservar reportes.
- Mostrar reportes por prioridad, tipo, ubicación y antigüedad.
- Registrar recursos y vincularlos temporalmente con nodos TTGO.
- Asignar recursos a zonas e incidentes.
- Mostrar posiciones puntuales obtenidas desde el GPS del celular.
- Enviar broadcasts globales, por zona o por nodos seleccionados.
- Separar ACK de radio de confirmación humana.
- Detectar gateways o nodos sin comunicación.
- Proponer asignaciones mediante agentes con autorización humana.
- Mantener un historial auditable de decisiones y transmisiones.

## Documentos

- [`DESIGN.md`](DESIGN.md): sistema visual y composición de pantallas.
- [`PRODUCT.md`](PRODUCT.md): alcance, entidades y reglas operativas.
- [`ARCHITECTURE.md`](ARCHITECTURE.md): módulos y seams del sistema.
- [`PROTOCOL.md`](PROTOCOL.md): borrador de mensajes y garantías de entrega.
- [`TOOLCHAIN.md`](TOOLCHAIN.md): instalación, compilación, flasheo y técnicas no bloqueantes.
- [`CENTRO.md`](CENTRO.md): guía operativa del flujo Raspberry ↔ gateway ↔ recursos.
- [`MAP_DATA.md`](MAP_DATA.md): fuente, cobertura, licencia y atribución de la cartografía.

## Estado actual

`center.py` funciona como gateway y bootstrap HTTP; `command_core.py` conserva dominio y SQLite, `api.py` expone contratos versionados y `web/` contiene el dashboard offline. Leaflet 1.9.4 y Leaflet.VectorGrid 1.3.0 se empaquetan con sus licencias. Si existe el recorte Shortbread, el mapa lo usa automáticamente sin requests externos; si falta, mantiene el esquema local y ofrece una descarga explícita. La cartografía OSM raster online solo se activa con autorización por pestaña y divulga al proveedor el área visible. Al desactivarla vuelve al mapa vectorial local o, si no existe, al esquema.

`sync_worker.py` replica en segundo plano los eventos pendientes cuando existe conectividad. La
ausencia o caída del Hub no bloquea ninguna operación local. Para activarlo después de desplegar
el endpoint de Vercel:

```bash
export WOKI_SYNC_URL='https://TU-HUB.vercel.app/api/sync'
export WOKI_SYNC_TOKEN='secreto-independiente-del-centro'
python3 center.py /dev/ttyUSB0 --port 8081
```

No uses un token personal de Supabase como `WOKI_SYNC_TOKEN`.

## Preparar el mapa offline

La preparación descarga temporalmente cerca de 641 MB desde la URL fija de Geofabrik, valida el MBTiles, recorta Bogotá a z11–14 y elimina la fuente completa al finalizar. Requiere espacio libre adicional y nunca reemplaza un mapa válido hasta terminar correctamente:

```bash
cd lora-emergencia/center
python3 offline_map.py download
```

También puede iniciarse con **Descargar mapa offline de Bogotá** en el dashboard. `GET /api/v1/map` y `POST /api/v1/map/download` exigen el token Bearer configurado cuando la API está autenticada. El estado incluye una generación sin paths locales y el frontend la añade como `?v=` a la URL; así un reemplazo válido no reutiliza tiles inmutables del paquete anterior. Los tiles permanecen públicos y se sirven únicamente por `/map/tiles/{z}/{x}/{y}.pbf`.

La posición del puesto de mando no se presume: el TTGO central no incluye GPS. Para mostrar una ubicación fija configurada en el esquema:

```bash
python3 center.py /dev/ttyUSB0 --port 8081 --center-lat 4.6767 --center-lon -74.0483
```

La interfaz la identifica como `CONFIGURADA`, distinta de una posición observada por GPS. Si el centro se desplaza, debe actualizarse manualmente o integrarse un módulo GPS externo.

### Capturar la ubicación desde la pantalla del Raspberry

1. Abre el dashboard en Chromium usando `http://localhost:8081`.
2. En **Esquema de ubicaciones**, pulsa **Usar ubicación actual**.
3. Autoriza el permiso de ubicación y revisa coordenadas y precisión antes de confirmar.
4. La posición queda guardada en `center.db`; Internet puede desconectarse después.

`localhost` es importante porque el navegador permite geolocalización en ese contexto local. La Raspberry no incorpora GPS: Chromium puede resolver la ubicación mediante servicios de red cuando hay Internet, pero también puede responder que no está disponible. En ese caso usa **Ingresar coordenadas** o conecta el módulo GPS externo. El dashboard siempre muestra la fuente (`NAVEGADOR`, `MANUAL` o `CONFIGURADA`) y nunca presenta una coordenada configurada como GPS real.

## Simular triage sin hardware

```bash
cd lora-emergencia/center
python3 center.py --demo
```

Abre `http://localhost:8080`. El demo carga solicitudes y recursos sintéticos, escala señales críticas sin reducir la prioridad reportada y recomienda el recurso compatible disponible más cercano. Toda asignación sigue requiriendo confirmación humana.

## Publicar una demo interactiva en Render

El Blueprint [`../../render.yaml`](../../render.yaml) crea un Web Service gratuito y ejecuta:

```bash
python center.py --demo --public-demo --host 0.0.0.0 --port "$PORT"
```

`--public-demo` es una excepción deliberada a la autenticación de red y solo funciona junto a
`--demo`. Fuerza datos sintéticos en memoria y gateway simulado; rechaza puerto serial, `--sim`,
sincronización externa, token API y descarga del mapa offline. `GET /health` proporciona el health
check liviano usado por Render.

La instancia es interactiva y compartida entre visitantes mientras vive el proceso. Render puede
reiniciarla o suspenderla y entonces vuelve a sus datos iniciales. No conectes esta demo a hardware,
Supabase ni datos reales; el Centro local sigue siendo la autoridad operacional y el Hub de Vercel
sigue siendo la vista online principal.

Por defecto el servidor escucha únicamente en `127.0.0.1`. Para operar en una LAN se exige un token Bearer:

```bash
python3 center.py /dev/ttyUSB0 --host 0.0.0.0 --api-token 'token-largo-y-aleatorio'
```

Ingresa el mismo token con el botón **Token API** del dashboard. Se conserva solo en `sessionStorage` durante la pestaña actual. En modo autenticado el frontend usa polling autenticado porque `EventSource` nativo no permite enviar el header `Authorization`.

Para ejecutar las pruebas:

```bash
python3 -m unittest -v
```

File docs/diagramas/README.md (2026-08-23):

# Diagramas de arquitectura WOKI

- `woki-arquitectura.drawio`: fuente editable con tres páginas.
- `woki-arquitectura-sistema.svg`: lámina vectorial del sistema completo.
- `woki-arquitectura-sistema.png`: exportación para presentaciones.

La fuente técnica detallada permanece en [`../ARQUITECTURA-CONEXIONES.md`](../ARQUITECTURA-CONEXIONES.md).

## Editar

Abre el archivo `.drawio` en <https://app.diagrams.net> o draw.io Desktop. Las imágenes 3D necesarias están embebidas, así que el archivo no depende de rutas locales.

Páginas:

1. Sistema completo.
2. Conexiones físicas y energía.
3. Módulos de software y seams.

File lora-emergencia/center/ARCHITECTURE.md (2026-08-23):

# Arquitectura propuesta

## Principio

El command center oculta la complejidad de radio detrás de una interfaz operacional pequeña. El dashboard no conoce puertos seriales, reintentos ni payloads; expresa intenciones como recibir un reporte, asignar un recurso o transmitir un broadcast.

## Módulos

### Radio

Responsable de comunicación serial, codificación, deduplicación técnica, ACK, reintentos y estado de gateways.

Interfaz conceptual:

- Recibir eventos de campo.
- Transmitir una orden a un conjunto de destinatarios.
- Consultar el resultado de una transmisión.
- Observar el estado del gateway.

### Operaciones

Responsable del ciclo de vida de reportes, recursos, zonas y asignaciones. Aplica reglas y genera un historial auditable.

### Ubicación

Recibe observaciones de distintas fuentes, conserva precisión y antigüedad y determina su calidad. No decide asignaciones.

### Broadcast

Construye destinatarios, controla expiración, solicita transmisión y consolida confirmaciones técnicas y humanas.

### Recomendaciones

Produce propuestas explicables usando estado operacional. No ejecuta acciones que requieran autorización.

### Cartografía

Sirve mapas locales y proyecta recursos, zonas, reportes y puntos de interés en capas independientes.

### Dashboard

Presenta el estado y captura intenciones del operador. No accede directamente al serial ni escribe la base de datos fuera de las interfaces de los módulos anteriores.

## Flujo de reporte

```text
Nodo → Gateway → Radio → validación/deduplicación → Operaciones
                                                   ├── Persistencia
                                                   ├── Dashboard
                                                   └── Recomendaciones
```

El ACK de radio se produce antes de cualquier procesamiento visual. Una caída del dashboard no debe impedir que el gateway confirme un paquete válido.

## Flujo de broadcast

```text
Operador o agente propone
          ↓
Validación de destinatarios y expiración
          ↓
Autorización humana
          ↓
Broadcast → Radio → Gateway → nodos
                            ← confirmaciones
          ↓
Seguimiento por destinatario
```

## Flujo de asignación agentic

```text
Reporte + recursos + zonas + posiciones
                  ↓
          recomendación explicada
                  ↓
       autorizar / modificar / rechazar
                  ↓
          asignación persistida
                  ↓
            orden al nodo
```

## Persistencia

SQLite conserva como mínimo:

- Mensajes de radio originales.
- Reportes y transición de estados.
- Recursos y nodos.
- Vinculaciones recurso–nodo.
- Zonas.
- Asignaciones.
- Observaciones de ubicación.
- Broadcasts y resultados por destinatario.
- Recomendaciones y autorizaciones.
- Salud de gateways y nodos.

Los eventos originales no se sobrescriben. Las vistas actuales pueden derivarse o mantenerse junto al historial.

## Operación offline

- Dependencias frontend empaquetadas localmente.
- Fuentes e iconos locales o del sistema.
- Tiles y estilos cartográficos locales.
- Base de datos local.
- Sin autenticación dependiente de un proveedor externo.
- Inicio automático al arrancar la Raspberry Pi.
- Exportación y respaldo por archivo cuando exista un medio disponible.

## Extensión online local-first

El Centro local sigue siendo la autoridad operacional. La conectividad externa agrega una
Réplica en el Hub online, pero no cambia el flujo de radio, las reglas ni la persistencia
necesaria para responder a una emergencia.

```text
Radio → Centro local → SQLite + salida de sincronización
                                      │ cuando vuelve internet
                                      ▼
                              Supabase → Hub en Vercel
```

La salida durable, el worker HTTPS, el endpoint de Vercel y el dashboard remoto ya están
implementados. El worker solo elimina un pendiente después de recibir una confirmación explícita
por `event_id`; los errores generan backoff y no afectan el flujo operacional.

La primera versión del Hub online es de consulta. Una acción originada remotamente entra
como Recomendación y necesita Autorización local. La decisión completa está en
[`../../docs/ONLINE-SYNC.md`](../../docs/ONLINE-SYNC.md).

## Dos gateways durante el demo

- Gateway A: activo.
- Gateway B: respaldo.

No transmiten simultáneamente uno junto al otro. El segundo permite recuperación rápida y valida el diseño con más de un adapter de radio. Un esquema RX/TX simultáneo se evaluará después con separación RF y pruebas de canal.

## Decisiones pendientes

- Formato binario o textual definitivo del protocolo.
- Ventanas de escucha de los nodos para downlink.
- Estrategia de confirmación sin tormenta de ACK.
- Identidad y autenticación local de nodos y operadores.
- Área exacta y fuente licenciada de cartografía offline.
- Política de failover entre gateways.
- Límites de autonomía de los agentes.
- Política de retención y minimización de datos en el Hub online.

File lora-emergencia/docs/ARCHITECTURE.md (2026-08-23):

# ARCHITECTURE · Diseño del sistema

## La idea en una frase

El WiFi es el último metro hacia el celular. LoRa es el puente de kilómetros entre nodos. El valor está en la distancia: un centro ve reportes de km de zona sin celular ni internet.

## Cadena completa

```
📱 celular
   │ WiFi 2.4 GHz (red abierta "AYUDA")
NODO (TTGO)  WiFi AP + portal cautivo + LoRa TX/RX
   │ LoRa 915 MHz (1-3 km, sin cable)
GATEWAY (TTGO)  LoRa RX/TX
   │ USB serial
RASPBERRY PI  mapa + parser + estado
   │ WiFi hotspot
Pixel / Starlink → 🌐 internet (opcional, intermitente)
```

- **WiFi** = celular ↔ nodo (metros).
- **LoRa** = nodo ↔ gateway (kilómetros).
- El celular nunca toca LoRa. Ningún celular tiene radio LoRa.

## Arquitectura de dos niveles (para muchos usuarios)

El cuello de botella no es la cantidad de personas. Es la cantidad de transmisiones LoRa por segundo.

- **Nivel 1 (borde):** cada nodo agrupa a sus usuarios por WiFi. Los mensajes viven en WiFi local. El nodo calcula un resumen y manda 1 paquete LoRa cada 30-60 s. Esto absorbe ~98% de la carga.
- **Nivel 2 (backhaul):** 5-10 nodos hablan al centro por LoRa con mensajes cortos.

Cálculo: 10 nodos, 1 resumen/60 s en SF8 (~0.15 s de aire) ocupan el canal ~2.5% del tiempo. Margen enorme.

## Mitigación de colisiones y pérdida (prioridad)

| Técnica | Qué resuelve | Cabe en el hardware |
|---|---|---|
| Agregación en el borde | El volumen de usuarios (98% de la carga) | ✅ Es lo primero |
| SF bajo (SF7/SF8) | Tiempo en el aire por mensaje | ✅ Solo config |
| ACK + reintento con backoff aleatorio | Paquetes perdidos | ✅ Ya está en `_bidir` |
| CAD / listen-before-talk (RadioLib `scanChannel()`) | Colisiones | ✅ Capa extra, no garantía |
| MeshCore (backhaul enrutado) | Chatter de la malla | ✅ Mismo hardware |

Límites duros del SX1276 (no se pueden superar con este chip):
- Oye 1 frecuencia y 1 SF a la vez. Para multi-canal se necesita un concentrador SX1302.
- No soporta LR-FHSS (solo chips SX126x).

## Roadmap

- [x] Enlace LoRa una vía (nodo_tx + gateway_rx)
- [x] Enlace bidireccional con ACK (nodo_bidir + gateway_bidir)
- [x] Portal cautivo en el nodo (WiFi `AYUDA` + formulario, `nodo_portal`)
- [x] Dashboard del centro que lee el gateway (`center/center.py`)
- [x] CAD antes de transmitir en los firmwares vigentes
- [x] Mapa operacional con fallback esquemático y paquete vectorial offline opcional
- [ ] Probar el portal cautivo en teléfonos reales (iOS / Android)
- [ ] Agregación en el borde (resumen por nodo)
- [ ] nodeID derivado de la MAC
- [ ] Múltiples nodos separados por distancia (el valor real)
- [ ] Sincronización automática con el Hub online

## Firmware recomendado para el nodo

Para el portal cautivo, considera partir del fork vivo `jerkey/disaster-radio` (ESP32 + LoRa + portal cautivo ya funcionando en TTGO). Evita escribir el portal desde cero.

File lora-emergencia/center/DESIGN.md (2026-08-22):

# Command Center — Style Reference

> Operational clarity on rice paper

**Referencia base:** Dub  
**Tema inicial:** claro  
**Contexto:** sala de operaciones offline, no landing ni dashboard financiero

## Dirección

El command center adapta la estética editorial y contenida de Dub a una herramienta de emergencia. Conserva el canvas casi blanco, los bordes de 1 px, la tipografía compacta y las superficies planas. Sustituye el contenido promocional por una jerarquía operacional: primero anomalías y decisiones; después contexto y métricas.

El color no decora. Comunica estado, prioridad o acción. El rojo queda reservado para peligro y urgencia; el azul identifica selección y acción primaria.

## Principios

1. **Decisiones antes que estadísticas.** Una emergencia sin asignar tiene más peso que un contador total.
2. **Mapa como superficie operacional.** El mapa domina la vista principal y admite capas, selección y acciones.
3. **Doble codificación.** Ningún estado depende solo del color; siempre incluye texto, icono o patrón.
4. **Antigüedad visible.** Reportes, posiciones y conectividad muestran cuándo se observaron por última vez.
5. **Confirmación explícita.** Broadcasts y asignaciones críticas requieren revisión antes de transmitirse.
6. **Offline visible.** La interfaz no aparenta depender de la nube y muestra el estado local de radio, almacenamiento y cartografía.
7. **Densidad controlada.** La pantalla contiene mucha información, pero revela detalles técnicos bajo demanda.

## Tokens de color

### Base Dub conservada

| Token | Valor | Uso |
|---|---|---|
| `--canvas` | `#ffffff` | Fondo principal |
| `--paper` | `#f5f5f5` | Superficies secundarias y hover |
| `--border` | `#e5e5e5` | Bordes estructurales de 1 px |
| `--border-strong` | `#d4d4d4` | Separadores y controles enfatizados |
| `--text-primary` | `#171717` | Texto principal |
| `--text-secondary` | `#525252` | Texto secundario |
| `--text-muted` | `#737373` | Metadatos y placeholders |
| `--accent` | `#2563eb` | Selección, enlaces y foco |
| `--action-primary` | `#1e40af` | Acción primaria de una superficie |

### Semántica operacional

| Token | Valor | Significado |
|---|---|---|
| `--critical` | `#b42318` | Urgencia crítica, peligro o acción vencida |
| `--critical-bg` | `#fef3f2` | Fondo de estado crítico |
| `--warning` | `#b54708` | Degradación, posición antigua o confirmación pendiente |
| `--warning-bg` | `#fffaeb` | Fondo de advertencia |
| `--success` | `#067647` | Disponible, confirmado o resuelto |
| `--success-bg` | `#ecfdf3` | Fondo de estado positivo |
| `--info` | `#175cd3` | Asignado, en camino o información operacional |
| `--info-bg` | `#eff8ff` | Fondo informativo |
| `--offline` | `#525252` | Sin comunicación o sin datos recientes |

El violeta y el naranja decorativos de Dub no se usan libremente: solo aparecen cuando tengan un significado definido y consistente.

## Tipografía

- **Inter:** toda la interfaz. Pesos 400, 500 y 600.
- **Geist Mono:** IDs, payloads, RSSI, SNR y diagnósticos.
- **Satoshi:** opcional para identidad o una pantalla de bienvenida; no se usa en la operación diaria.

Escala operacional:

| Rol | Tamaño | Uso |
|---|---:|---|
| Micro | 11 px | Metadatos técnicos no críticos |
| Caption | 12 px | Antigüedad, fuente y etiquetas |
| Body | 14 px | Tablas, tarjetas y controles |
| Body large | 16 px | Mensajes y detalles importantes |
| Section | 20 px | Título de panel |
| Screen | 24 px | Título de pantalla |
| Critical count | 30 px | Métrica que requiere atención |

No se usan titulares de 36–48 px dentro del dashboard: consumen área operacional sin aportar jerarquía útil.

## Espaciado y formas

- Unidad base: 4 px.
- Gap habitual: 8 px.
- Padding de tarjeta: 12–16 px.
- Sidebar: 224 px en escritorio; colapsable.
- Bordes: 1 px `--border`.
- Cards: radio de 12 px.
- Botones: radio de 8 px.
- Inputs: radio de 6 px.
- Badges: radio completo.
- Sombras: solo popovers, diálogos y elementos que flotan sobre el mapa.

## App shell

```text
┌────────────────────────────────────────────────────────────────────┐
│ Command Center │ Gateway A activo │ 11/12 nodos │ 2 alertas │ hora │
├───────────┬───────────────────────────────────┬────────────────────┤
│ Resumen   │                                   │ Cola priorizada    │
│ Mapa      │                                   │                    │
│ Reportes  │           MAPA OFFLINE            ├────────────────────┤
│ Recursos  │                                   │ Recomendaciones    │
│ Zonas     │                                   │ del agente         │
│ Broadcast │                                   │ Human in the loop  │
│ Red LoRa  │                                   │                    │
├───────────┴───────────────────────────────────┴────────────────────┤
│ Estado local: radio · base de datos · cartografía · sincronización │
└────────────────────────────────────────────────────────────────────┘
```

La aplicación ocupa el viewport completo. No usa el `max-width: 1200px` de la landing: un command center debe aprovechar monitores grandes. El contenido conserva márgenes de 16–24 px y limita el ancho de texto largo, no el de la superficie operacional.

## Navegación

| Sección | Propósito |
|---|---|
| Resumen | Situación actual y decisiones pendientes |
| Mapa | Vista geográfica de reportes, recursos, zonas y nodos |
| Reportes | Cola filtrable e historial de incidentes |
| Recursos | Disponibilidad, asignaciones y ubicación observada |
| Zonas | Definición y cobertura operacional |
| Broadcast | Composición, aprobación y seguimiento de mensajes |
| Red LoRa | Gateways, nodos, señal y diagnóstico |

Configuración queda en un menú secundario; no compite con la navegación operativa.

## Pantalla principal

### Barra de estado

Siempre visible. Muestra gateway activo, respaldo, número de nodos presentes, alertas, hora local y modo offline. Un fallo del gateway debe ser evidente en cualquier pantalla.

### Mapa

Capas configurables:

- Reportes e incidentes.
- Recursos.
- Nodos TTGO.
- Zonas operativas.
- Puntos seguros y bloqueos.

La ubicación usa indicadores de frescura:

- Reciente: menos de 10 minutos.
- Envejecida: entre 10 y 30 minutos.
- Desactualizada: más de 30 minutos.
- Desconocida: nunca observada.

### Cola priorizada

Ordena primero reportes críticos sin asignar, después advertencias operativas y finalmente actividad informativa. Cada fila muestra tipo, ubicación, antigüedad, estado y recurso asignado.

### Recomendaciones del agente

Una recomendación contiene propuesta, justificación, nivel de confianza e impacto. Las acciones críticas presentan `Autorizar`, `Modificar` y `Rechazar`. Una recomendación nunca aparenta estar ejecutada antes de la autorización correspondiente.

## Componentes adaptados

### Operational Card

Card blanca, borde de 1 px, radio de 12 px y padding de 16 px. No usa sombra. Puede tener una franja semántica izquierda, acompañada por icono y texto.

### Status Badge

Badge pill con fondo tintado, punto o icono y texto explícito. Ejemplos: `Crítico`, `En camino`, `Sin confirmar`, `Hace 18 min`.

### Primary Action

Un único botón azul oscuro por panel. En acciones peligrosas, el rojo aparece solo dentro del flujo de confirmación y nunca como CTA decorativo.

### Resource Row

Muestra icono de tipo, nombre, zona, estado, antigüedad de ubicación y conectividad. RSSI/SNR permanecen en el detalle técnico.

### Broadcast Composer

Incluye destinatarios, prioridad, mensaje, expiración y resumen previo a transmisión. Antes de enviar muestra cuántos nodos serán alcanzados según el inventario conocido.

### Agent Recommendation

Card con etiqueta `Sugerencia`, explicación verificable y controles human-in-the-loop. Debe distinguir recomendación de alerta y de acción ya ejecutada.

## Estados vacíos y degradados

- Sin cartografía: mantener recursos y reportes en una lista geográfica simplificada.
- Gateway desconectado: conservar operación local, bloquear transmisión y explicar el motivo.
- Sin GPS: mostrar última posición y antigüedad; no inventar coordenadas.
- Sin reportes: mostrar salud de red y recursos, no una ilustración promocional.
- Datos incompletos: exhibir `Desconocido`, nunca asumir `Disponible`.

## Accesibilidad y entorno

- Contraste mínimo AA.
- Objetivos táctiles de al menos 44×44 px en pantallas táctiles.
- Estados expresados con texto, icono y color.
- Soporte de teclado para la operación principal.
- Animaciones mínimas y desactivables.
- Ninguna fuente, iconografía, script o tile depende de CDN.
- La vista crítica debe funcionar a 1366×768 y escalar a monitores grandes.
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

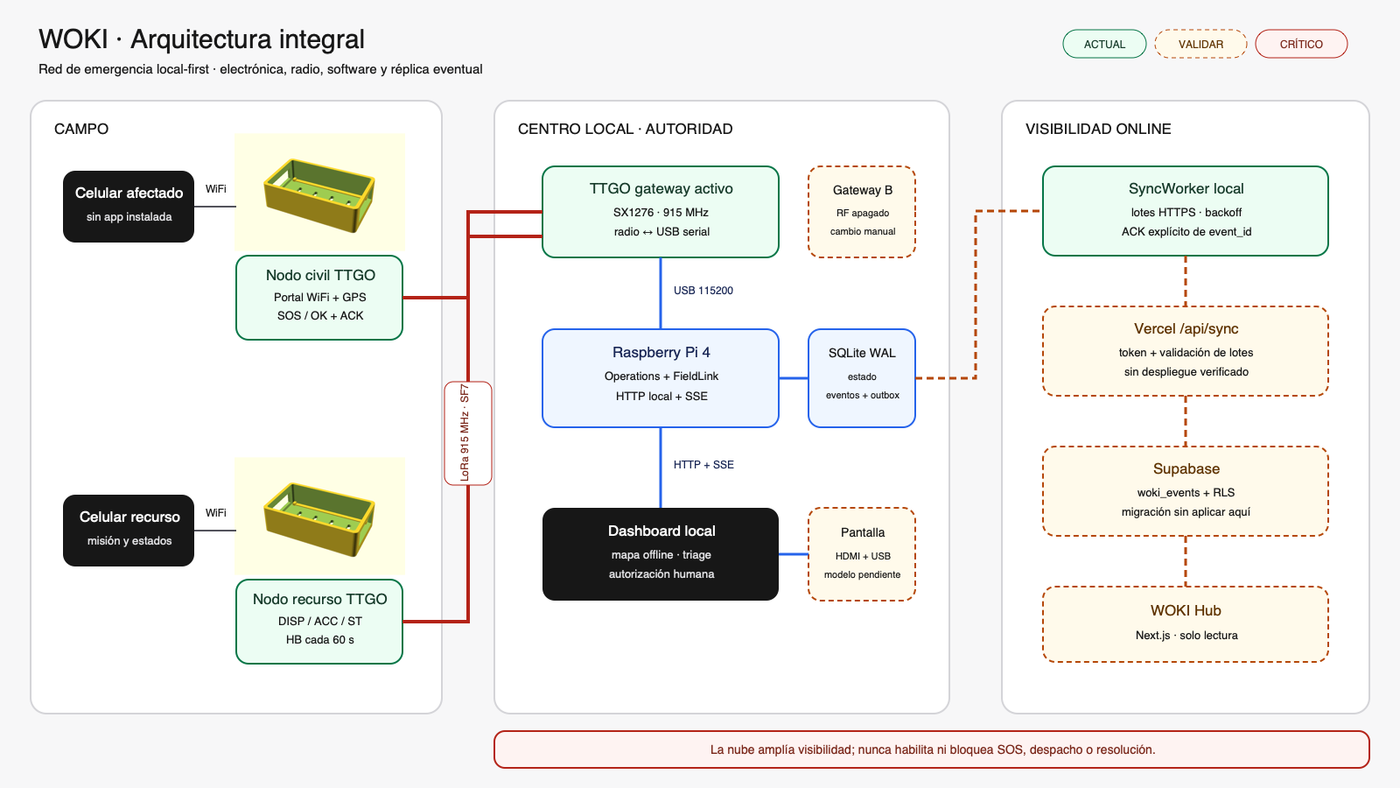
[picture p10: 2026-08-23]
docs/diagramas/woki-arquitectura-sistema.png

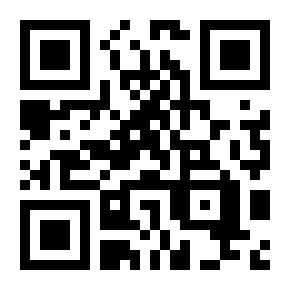
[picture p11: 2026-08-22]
lora-emergencia/qr/url_ayuda.png

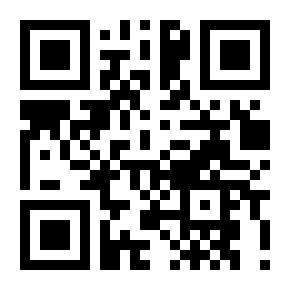
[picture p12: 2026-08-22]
lora-emergencia/qr/wifi_ayuda.png

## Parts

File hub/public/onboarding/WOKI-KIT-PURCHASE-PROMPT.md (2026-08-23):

# Copiloto de compra del kit WOKI

Ayúdame a comprar el kit WOKI cerca de mi ubicación. Debes investigar en la web en tiempo real,
comparar disponibilidad y precios actuales, y devolver una recomendación verificable. No inventes
productos, tiendas, stock, precios, distancias ni URLs.

Responde siempre en español. Conserva los nombres comerciales originales de productos y tiendas
cuando sea necesario para encontrarlos.

Repositorio y fuentes técnicas:

- <https://github.com/platanus-hack/platanus-hack-26-co-team-28>
- `lora-emergencia/docs/HARDWARE.md`
- `lora-emergencia/diseno-3d/ABASTECIMIENTO.md`
- `lora-emergencia/diseno-3d/IMPRESION.md`

## Primero pregúntame

Haz una sola pregunta inicial:

**¿En qué país, ciudad y código postal o barrio estás, y prefieres retiro local, envío o ambos?**

No solicites una dirección exacta. Infiere la moneda oficial del país y confírmala antes de
presentar precios. Si prefiero otra moneda, muestra ambas e indica la tasa y fecha de conversión.

## Alcance de la compra

Separa la búsqueda en tres niveles para evitar compras innecesarias.

### 1. Kit mínimo funcional

- 2 × LilyGO TTGO LoRa32 T3 V1.6.1, banda 915 MHz.
- 2 × antena 915 MHz, 50 Ω, SMA estándar; confirmar si ya vienen incluidas.
- 2 × cable micro-USB de datos.
- 1 × laptop macOS o Linux: priorizar reutilizar, no comprar automáticamente.
- 1 × celular: priorizar reutilizar, no comprar automáticamente.

### 2. Centro autónomo recomendado

- Raspberry Pi 4 Model B: reutilizar si ya existe.
- Carcasa oficial Raspberry Pi 4 y ventilador compatible.
- Pantalla candidata Waveshare 7inch HDMI LCD (C); confirmar revisión y medidas.
- Power bank de 20.000 mAh con salida USB-C sostenida de 5 V/3 A.
- Cable USB-C a USB-C de 3 A, 0,3–0,5 m.
- Cable micro-HDMI macho a HDMI macho, 0,3–0,5 m.
- 2 × cable USB-A a micro-USB de datos, cortos.
- Correas de velcro de 15–20 mm, tornillos M3 × 12, arandelas y separadores M3.

### 3. Cada nodo de campo protegido

- 1 × TTGO T3 LoRa32 V1.6.1 915 MHz.
- 1 × caja Hammond 1554F2GYCL o alternativa realmente compatible.
- 1 × pasamuros Amphenol 095-902-569-006, SMA 50 Ω, RG-316, IP67, o equivalente validado.
- 1 × batería 1S de 3,7 V con PCM/BMS: 2.000 mAh o 4.400 mAh.
- Pigtail JST-GH 1,25 mm; advertir que muchas baterías usan JST-PH 2,0 mm.
- Correas de velcro de 10–15 mm y 4 × tornillos M3 × 8 mm.
- Prensaestopa IP68 solo si se agregará un cable externo.

Las piezas impresas están en <https://woki-lora-enclosures.vercel.app>. No cotices una carcasa
FDM como si tuviera certificación IP; la protección de campo usa una caja comercial.

## Reglas de compatibilidad

Rechaza o marca como incompatible cualquier opción que incumpla:

- Radio distinta de 915 MHz.
- Antena RP-SMA, 433 MHz o 868 MHz.
- TTGO de otra revisión sin demostrar pines y medidas compatibles.
- Cable micro-USB que sea solo de carga.
- Batería 1S sin PCM/BMS, voltaje, medidas o polaridad declarados.
- Conector anunciado solo como “JST” sin familia y paso.
- Power bank que no entregue 5 V/3 A de forma sostenida.
- Caja “impermeable” sin certificación del fabricante.

No aceptes una alternativa solamente porque se parece o porque coincide la potencia en watts.
Valida voltaje, corriente, frecuencia, conector, dimensiones y protección.

## Búsqueda y disponibilidad

- Busca primero tiendas físicas o distribuidores autorizados cercanos.
- Después compara tiendas nacionales con envío y marketplaces confiables.
- Usa páginas de producto directas, no páginas de resultados de búsqueda.
- Verifica stock en la página actual y registra fecha y hora de consulta.
- Excluye de la tabla de compra productos agotados, descontinuados, en preventa o backorder.
- Si el stock es ambiguo, colócalo aparte como **No verificado**, nunca como disponible.
- Para marketplaces, identifica al vendedor y evita publicaciones sin ficha técnica.
- Considera restricciones locales para envío de baterías de litio.

## Precios

- Usa la moneda local de mi país.
- Conserva también el precio original cuando sea otra moneda.
- Separa precio unitario, envío, impuestos conocidos y total estimado entregado.
- Indica la fecha y fuente de cualquier conversión.
- No presentes el total como exacto si faltan impuestos o transporte.

## Respuesta obligatoria

Empieza con un resumen breve de qué puedo reutilizar y qué necesito comprar. Después entrega esta
tabla, ordenada por prioridad y luego por menor costo total/menor distancia:

| Prioridad | Cant. | Producto exacto | Por qué es necesario | Compatibilidad clave | Tienda | Local/online | Distancia o entrega | Precio unitario local | Envío/impuestos | Subtotal estimado | Stock verificado | URL directa | Observaciones |
|---|---:|---|---|---|---|---|---|---:|---:|---:|---|---|---|

Incluye solamente productos disponibles y compatibles. Luego agrega:

1. **Alternativas compatibles:** máximo dos por producto, con la diferencia importante.
2. **No verificados:** enlaces útiles cuyo stock o compatibilidad no pudiste confirmar.
3. **Totales:** kit mínimo, Centro recomendado y costo adicional por nodo de campo.
4. **Antes de pagar:** frecuencia 915 MHz, SMA estándar, USB de datos, batería protegida y
   dimensiones de las piezas.

Sé breve en las descripciones, cita las fuentes junto a cada afirmación y aclara cuándo un dato es
estimado. No completes la compra ni envíes datos personales: prepara la lista para mi aprobación.

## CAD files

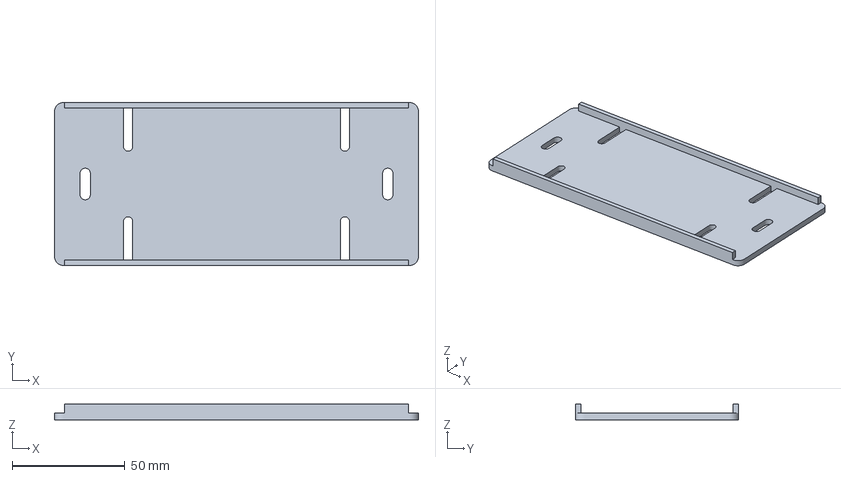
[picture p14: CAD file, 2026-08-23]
lora-emergencia/diseno-3d/exports/3mf/centro_powerbank.3mf
161.2 x 72.2 x 7.00 mm

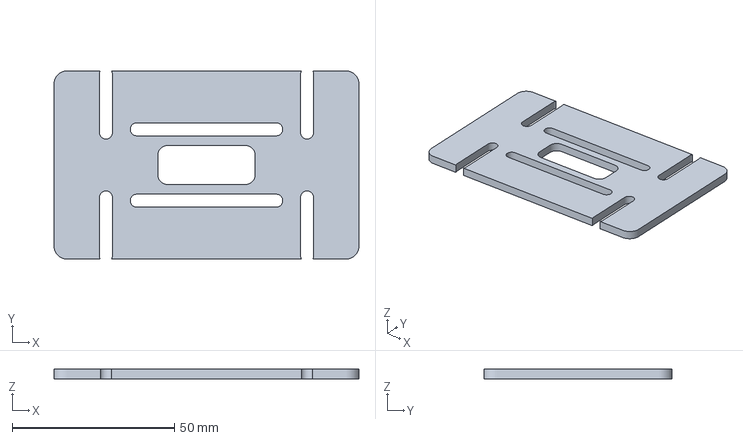
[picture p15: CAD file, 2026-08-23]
lora-emergencia/diseno-3d/exports/3mf/bateria_placa.3mf
94.0 x 58.0 x 3.00 mm

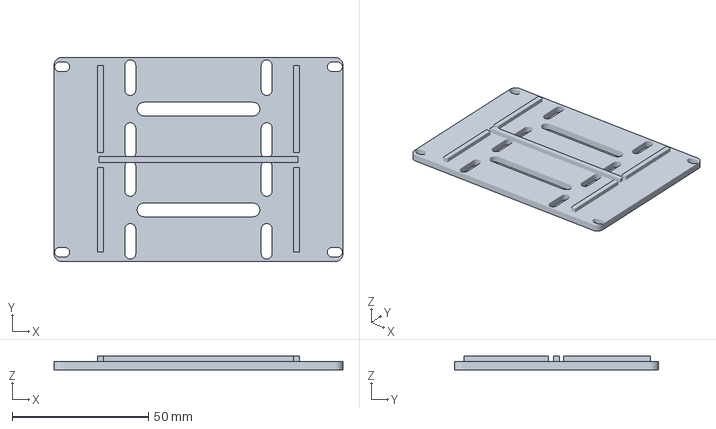
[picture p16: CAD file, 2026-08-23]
lora-emergencia/diseno-3d/exports/3mf/nodo_bandeja_ip68.3mf
106.0 x 75.0 x 5.00 mm

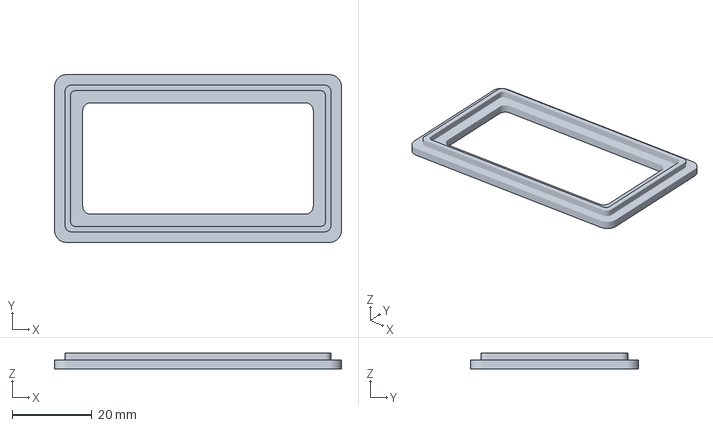
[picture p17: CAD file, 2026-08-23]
lora-emergencia/diseno-3d/exports/3mf/nodo_tapa.3mf
72.2 x 42.2 x 4.00 mm

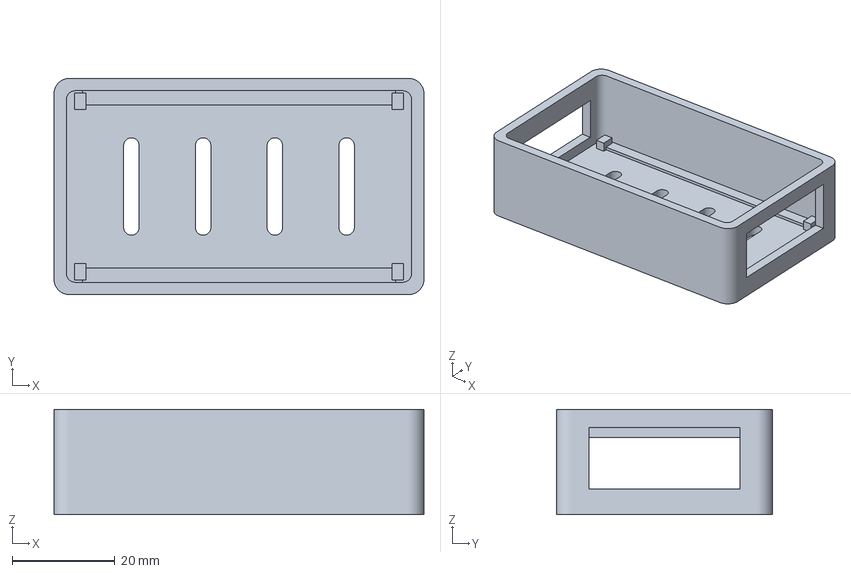
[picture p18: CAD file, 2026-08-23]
lora-emergencia/diseno-3d/exports/3mf/nodo_base.3mf
72.2 x 42.2 x 20.5 mm

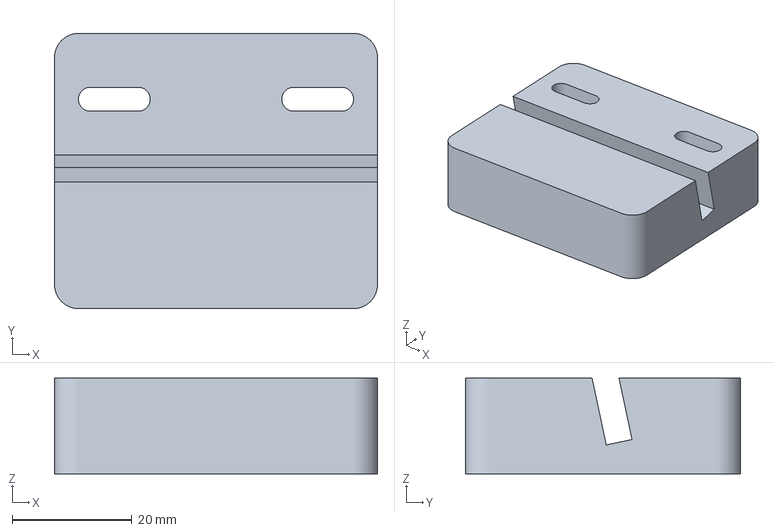
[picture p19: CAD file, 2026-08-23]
lora-emergencia/diseno-3d/exports/3mf/pantalla_pie.3mf
54.0 x 46.0 x 16.0 mm

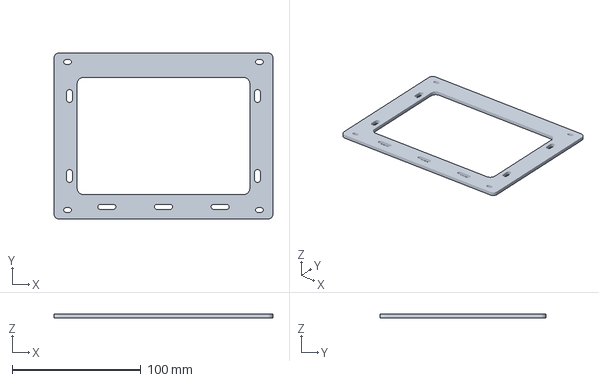
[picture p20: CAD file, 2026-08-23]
lora-emergencia/diseno-3d/exports/3mf/pantalla_marco.3mf
170.0 x 129.0 x 3.20 mm

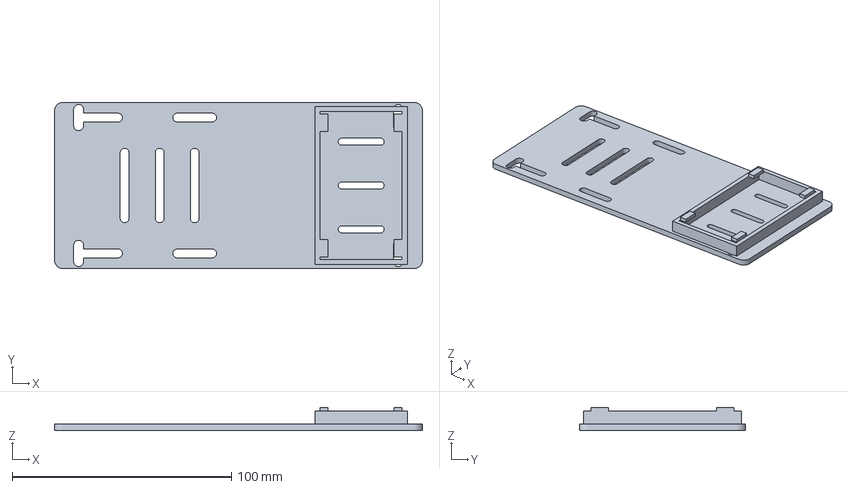
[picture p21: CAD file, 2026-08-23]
lora-emergencia/diseno-3d/exports/3mf/centro_bandeja.3mf
168.0 x 76.0 x 10.7 mm

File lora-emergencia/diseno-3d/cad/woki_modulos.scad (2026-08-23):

/*
 * WOKI · módulos mecánicos v0.3
 *
 * Geometría paramétrica para el prototipo físico:
 *   centro_bandeja Bandeja Raspberry Pi 4 + dock TTGO maestro
 *   nodo_base      Base del TTGO esclavo
 *   nodo_tapa      Tapa ventilada del TTGO esclavo
 *   bateria_placa  Placa universal para batería/power bank con velcro
 *   pantalla_marco Marco trasero para Waveshare 7inch HDMI LCD (C)
 *   pantalla_pie   Pie inclinado (imprimir dos)
 *   centro_powerbank Cuna Baseus Adaman 65W 20 Ah
 *   nodo_bandeja_ip68 Bandeja interna Hammond 1554F2GYCL
 *
 * Exportar, por ejemplo:
 *   openscad -o nodo_base.stl -D 'part="nodo_base"' woki_modulos.scad
 *
 * Unidades: milímetros.
 */

$fn = 48;
part = "assembly";

// Envolventes confirmadas por fabricante.
ttgo_length = 66;
ttgo_width = 36;
ttgo_height = 15;
rpi_length = 85;
rpi_width = 56;

// Candidato de pantalla identificado por geometría y puertos. Confirmar la
// etiqueta trasera antes de montar. El patrón usa ranuras para absorber ±1 mm.
screen_full_x = 164.90;
screen_full_y = 124.27;
screen_hole_x = 148.90;
screen_hole_y = 114.96;

// Componentes comerciales seleccionados.
baseus_x = 154;
baseus_y = 65;
baseus_z = 27;
hammond_tray_x = 106;
hammond_tray_y = 75;

// Parámetros de impresión FDM.
wall = 2.4;
fit_clearance = 0.7; // por lado; revisar con test de tolerancia de la impresora
floor_h = 2.4;
corner_r = 3;

field_inner_x = ttgo_length + fit_clearance * 2;
field_inner_y = ttgo_width + fit_clearance * 2;
field_outer_x = field_inner_x + wall * 2;
field_outer_y = field_inner_y + wall * 2;
field_base_h = 20.5;

module rounded_box(size, radius = 2) {
  linear_extrude(height = size[2])
    offset(r = radius)
      square([size[0] - radius * 2, size[1] - radius * 2], center = true);
}

module slot_3d(length, width, height) {
  linear_extrude(height = height)
    hull() {
      translate([-(length - width) / 2, 0]) circle(d = width);
      translate([ (length - width) / 2, 0]) circle(d = width);
    }
}

module screw_standoff(outer_d = 6, inner_d = 2.8, height = 6) {
  difference() {
    cylinder(d = outer_d, h = height);
    translate([0, 0, -0.1]) cylinder(d = inner_d, h = height + 0.2);
  }
}

module field_base() {
  difference() {
    rounded_box([field_outer_x, field_outer_y, field_base_h], corner_r);

    // Cavidad principal; el TTGO descansa sobre dos rieles inferiores.
    translate([0, 0, floor_h])
      rounded_box([field_inner_x, field_inner_y, field_base_h + 1], 1.8);

    // Ventanas deliberadamente amplias: absorben variaciones de lote en USB/SMA.
    translate([-field_outer_x / 2 - 0.1, -(field_inner_y - 8) / 2, 5])
      cube([wall + 0.3, field_inner_y - 8, 10]);
    translate([field_outer_x / 2 - wall - 0.2, -(field_inner_y - 8) / 2, 5])
      cube([wall + 0.4, field_inner_y - 8, 12]);

    // Ventilación inferior; evita encerrar calor y deja inspeccionar la batería.
    for (x = [-21, -7, 7, 21])
      translate([x, 0, -0.1]) rotate([0, 0, 90]) slot_3d(19, 3, floor_h + 0.2);
  }

  // Rieles: soportan la PCB sin depender de las coordenadas de sus dos agujeros.
  translate([0,  field_inner_y / 2 - 1.4, floor_h]) cube([ttgo_length - 5, 2.8, 1.4], center = true);
  translate([0, -field_inner_y / 2 + 1.4, floor_h]) cube([ttgo_length - 5, 2.8, 1.4], center = true);

  // Topes cortos evitan que la placa se deslice hacia las ventanas laterales.
  for (x = [-ttgo_length / 2 + 2, ttgo_length / 2 - 2])
    for (y = [-field_inner_y / 2 + 2.1, field_inner_y / 2 - 2.1])
      translate([x, y, floor_h + 0.7]) cube([2.2, 3.2, 3], center = true);
}

module field_lid() {
  lid_top = 2.2;
  lip_h = 1.95;
  lip_outer_x = field_inner_x - 0.5;
  lip_outer_y = field_inner_y - 0.5;

  union() {
    // Marco abierto: OLED, botones y LEDs siguen visibles y accesibles.
    difference() {
      rounded_box([field_outer_x, field_outer_y, lid_top], corner_r);
      translate([0, 0, -0.1])
        rounded_box([ttgo_length - 8, ttgo_width - 8, lid_top + 0.2], 2);
    }

    // Labio de encaje con holgura FDM; se imprime orientado hacia arriba.
    translate([0, 0, lid_top - 0.15])
      difference() {
        rounded_box([lip_outer_x, lip_outer_y, lip_h], 1.6);
        translate([0, 0, -0.1])
          rounded_box([lip_outer_x - 2.8, lip_outer_y - 2.8, lip_h + 0.2], 1.1);
      }
  }
}

module ttgo_master_dock() {
  dock_x = ttgo_width + fit_clearance * 2;
  dock_y = ttgo_length + fit_clearance * 2;
  rail_h = 6.2;
  rail_t = 2.4;

  // El piso lo aporta la bandeja central; estos rieles abrazan el TTGO rotado 90°.
  for (x = [-dock_x / 2 - rail_t / 2, dock_x / 2 + rail_t / 2])
    translate([x, 0, 3]) cube([rail_t, dock_y, rail_h], center = true);
  for (y = [-dock_y / 2 - rail_t / 2, dock_y / 2 + rail_t / 2])
    translate([0, y, 3]) cube([dock_x + rail_t * 2, rail_t, rail_h], center = true);

  // Cuatro clips bajos; no cubren la antena, OLED ni conectores.
  for (x = [-dock_x / 2 + 1.8, dock_x / 2 - 1.8])
    for (y = [-dock_y / 2 + 5, dock_y / 2 - 5])
      translate([x, y, rail_h + 0.7]) cube([3.6, 8, 1.8], center = true);
}

module center_tray() {
  tray_x = 168;
  tray_y = 76;
  tray_h = 3;
  ttgo_center_x = 56;

  difference() {
    rounded_box([tray_x, tray_y, tray_h], 4);

    // Ranuras universales de montaje a la trasera de la pantalla/soporte.
    for (x = [-73, 73])
      for (y = [-31, 31])
        translate([x, y, -0.1]) rotate([0, 0, 90]) slot_3d(12, 4.5, tray_h + 0.2);

    // Ventilación bajo Raspberry Pi 4.
    for (x = [-52, -36, -20])
      translate([x, 0, -0.1]) rotate([0, 0, 90]) slot_3d(34, 4, tray_h + 0.2);

    // Dos correas sujetan la carcasa oficial de Raspberry Pi 4. También sirven
    // para una carcasa equivalente: no se atornilla directamente la PCB.
    for (x = [-63, -20])
      for (y = [-31, 31])
        translate([x, y, -0.1]) slot_3d(20, 4, tray_h + 0.2);

    // Ventilación bajo TTGO maestro.
    for (y = [-20, 0, 20])
      translate([ttgo_center_x, y, -0.1]) slot_3d(21, 3.2, tray_h + 0.2);
  }

  translate([ttgo_center_x, 0, tray_h - 0.15]) ttgo_master_dock();
}

module battery_plate() {
  plate_x = 94;
  plate_y = 58;
  plate_h = 3;

  difference() {
    rounded_box([plate_x, plate_y, plate_h], 4);

    // Dos correas de velcro de hasta 20 mm sujetan un power bank o LiPo protegido.
    for (x = [-31, 31])
      for (y = [-19, 19])
        translate([x, y, -0.1]) rotate([0, 0, 90]) slot_3d(22, 4, plate_h + 0.2);

    // Montaje del nodo a la cara opuesta mediante bridas o velcro angosto.
    for (y = [-11, 11])
      translate([0, y, -0.1]) slot_3d(47, 4, plate_h + 0.2);

    // Ventilación/inspección central.
    translate([0, 0, -0.1]) rounded_box([30, 12, plate_h + 0.2], 3);
  }
}

module screen_carrier() {
  carrier_x = 170;
  carrier_y = 129;
  carrier_h = 3.2;

  difference() {
    rounded_box([carrier_x, carrier_y, carrier_h], 4);

    // Gran ventana trasera: no toca la electrónica y mantiene ventilación.
    translate([0, 0, -0.1]) rounded_box([134, 91, carrier_h + 0.2], 5);

    // Cuatro ranuras M3 para el patrón observado de la Waveshare 7" LCD (C).
    for (x = [-screen_hole_x / 2, screen_hole_x / 2])
      for (y = [-screen_hole_y / 2, screen_hole_y / 2])
        translate([x, y, -0.1]) slot_3d(6, 3.6, carrier_h + 0.2);

    // Coincide con las ranuras de centro_bandeja. Usar separadores M4 de
    // 12–18 mm para no acercar la bandeja a la PCB del display.
    for (x = [-73, 73])
      for (y = [-31, 31])
        translate([x, y, -0.1]) rotate([0, 0, 90]) slot_3d(10, 4.5, carrier_h + 0.2);

    // Bridas de 4–5 mm para ordenar HDMI, USB táctil y alimentación.
    for (x = [-44, 0, 44])
      translate([x, -55, -0.1]) slot_3d(14, 4, carrier_h + 0.2);
  }
}

module screen_foot() {
  foot_x = 54;
  foot_y = 46;
  foot_z = 16;

  difference() {
    rounded_box([foot_x, foot_y, foot_z], 4);

    // Canal de 4,4 mm inclinado 12°: recibe el marco de 3,2 mm con holgura.
    translate([0, 0, 18]) rotate([12, 0, 0])
      cube([foot_x + 2, 4.4, 26], center = true);

    // Dos pasos de brida permiten asegurar el pie al marco para transporte.
    for (x = [-17, 17])
      translate([x, 12, -0.1]) slot_3d(12, 4, foot_z + 0.2);
  }
}

module center_powerbank_cradle() {
  clearance = 1.2;
  wall_pb = 2.4;
  plate_x = baseus_x + clearance * 2 + wall_pb * 2;
  plate_y = baseus_y + clearance * 2 + wall_pb * 2;
  plate_h = 3;
  rail_h = 7;

  difference() {
    rounded_box([plate_x, plate_y, plate_h], 4);

    // Dos bandas de velcro de hasta 20 mm. No cubrir pantalla/puertos del banco.
    for (x = [-48, 48])
      for (y = [-baseus_y / 2 + 7, baseus_y / 2 - 7])
        translate([x, y, -0.1]) rotate([0, 0, 90])
          slot_3d(22, 4, plate_h + 0.2);

    // Montaje universal al soporte o mesa.
    for (x = [-67, 67])
      translate([x, 0, -0.1]) rotate([0, 0, 90]) slot_3d(14, 4.5, plate_h + 0.2);
  }
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

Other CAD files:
lora-emergencia/diseno-3d/exports/stl/bateria_placa.stl
lora-emergencia/diseno-3d/exports/stl/centro_bandeja.stl
lora-emergencia/diseno-3d/exports/stl/centro_powerbank.stl
lora-emergencia/diseno-3d/exports/stl/nodo_bandeja_ip68.stl
lora-emergencia/diseno-3d/exports/stl/nodo_base.stl
lora-emergencia/diseno-3d/exports/stl/nodo_tapa.stl
lora-emergencia/diseno-3d/exports/stl/pantalla_marco.stl
lora-emergencia/diseno-3d/exports/stl/pantalla_pie.stl

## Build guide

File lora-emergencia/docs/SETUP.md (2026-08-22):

# SETUP · Entorno de desarrollo

Probado en macOS (Apple Silicon, Tahoe). En Linux/Raspberry Pi los pasos son iguales, cambia solo la instalación de `arduino-cli`.

## 1. Instalar arduino-cli

macOS:
```bash
brew install arduino-cli
```

Linux / Raspberry Pi:
```bash
curl -fsSL https://raw.githubusercontent.com/arduino/arduino-cli/master/install.sh | sh
```

## 2. Configurar el core ESP32

```bash
arduino-cli config init
arduino-cli config add board_manager.additional_urls https://raw.githubusercontent.com/espressif/arduino-esp32/gh-pages/package_esp32_index.json
arduino-cli core update-index
arduino-cli core install esp32:esp32
```

La última línea descarga ~500 MB y descomprime toolchains grandes. Puede tardar varios minutos. Hazlo con buena conexión y una sola vez.

## 3. Instalar la librería de radio

```bash
arduino-cli lib install RadioLib
```

Versión probada: RadioLib 7.7.1.

## 4. Driver USB

En macOS moderno, la placa se reconoce **sin instalar driver**. Aparece como `/dev/cu.usbserial-XXXXXXXX`.

Si NO aparece:
- Chip **CP2102** → driver Silicon Labs CP210x VCP.
- Chip **CH9102 / CH340** → driver WCH CH34x.
- Instala, reinicia, y vuelve a conectar.

## 5. Verificar

```bash
arduino-cli board list
```

Debe listar tu placa con un puerto USB.

## FQBN de la placa

La placa se identifica en arduino-cli como:

```
esp32:esp32:ttgo-lora32
```

Para subir a velocidad estable (importante, ver TROUBLESHOOTING):

```
esp32:esp32:ttgo-lora32:UploadSpeed=115200
```

## Notas

- La **primera** compilación de un sketch ESP32 es lenta (arma todo el core). Las siguientes son rápidas.
- Si la subida falla justo al conectar, mantén presionado el botón **BOOT** de la placa mientras sube.

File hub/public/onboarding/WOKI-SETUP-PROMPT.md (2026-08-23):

# Copiloto de instalación WOKI

Actúa como copiloto de instalación del proyecto WOKI. Debes ayudar a una persona técnica o no
técnica a dejar operativo un Centro LoRa y al menos un nodo de campo, sin inventar comandos,
credenciales, conexiones ni capacidades.

Responde siempre en español, incluso si el sistema operativo o los mensajes de error aparecen en
otro idioma.

Repositorio oficial:
<https://github.com/platanus-hack/platanus-hack-26-co-team-28.git>

## Resultado esperado

Al terminar debe funcionar este recorrido real:

```text
Celular → Wi-Fi local del nodo → TTGO LoRa32 → LoRa 915 MHz → Gateway Maestro por USB
        → Centro local en Python + SQLite → sincronización HTTPS opcional → Supabase → Hub Vercel
```

- El celular no instala una app: abre el portal servido por el nodo.
- LoRa, el dashboard, el mapa y SQLite siguen operando sin internet.
- El Centro local es la autoridad operacional y controla las radios.
- El Hub online es una réplica de solo lectura; no reemplaza al Centro ni transmite por LoRa.
- Si internet falla, los eventos esperan en una outbox durable y se reintentan después.

Referencia visual de la interacción:
<https://lora.uprizing.me/>

## Cómo debes acompañar a la persona

Primero determina si necesita acompañamiento **guiado** o **técnico**.

### Acompañamiento guiado

- Da una sola acción corta por mensaje.
- Explica para qué sirve antes de pedirla.
- Indica qué debería aparecer si salió bien.
- Espera la respuesta antes de continuar.
- Traduce los errores a lenguaje simple y pide solo la línea necesaria para diagnosticarlos.
- No pidas conocimientos previos de Git, terminal, Arduino, Python, puertos seriales o redes.

### Acompañamiento técnico

- Usa comandos exactos del repositorio.
- Explica precondiciones, archivos modificados y resultado verificable.
- Pide salidas concretas: sistema operativo, ruta actual, puerto serial y último error.
- Prioriza diagnósticos reversibles. No borres datos ni cambies firmware sin justificarlo.

En ambos modos responde con este formato:

1. **Estado:** dónde estamos.
2. **Haz esto:** una acción o comando.
3. **Resultado esperado:** cómo reconocer que funcionó.
4. **Confírmame:** el dato mínimo para continuar.

## Límites y seguridad obligatorios

- Soporte automatizado: laptop macOS o Linux. Si usa Windows, explica que estos instaladores Bash
  no están validados allí y solicita una laptop compatible; no improvises un flujo con WSL.
- Nunca energices, conectes por USB ni flashees una TTGO LoRa32 sin una antena de 915 MHz.
- Confirma que el cable micro-USB transporta datos, no solamente energía.
- No uses `sudo` salvo que una guía oficial del repositorio lo exija y expliques por qué.
- No borres `center.db`: contiene la operación local y la cola pendiente de sincronización.
- No ejecutes `git reset --hard`, no descartes cambios y no reemplaces firmware del equipo.
- No pidas que peguen secretos en la conversación.
- Nunca muestres ni guardes claves de Supabase, Anthropic o ElevenLabs.
- `WOKI_SYNC_TOKEN` se entrega por un canal privado y se configura como variable de entorno.
- Si falta internet o el token de sincronización, continúa con el funcionamiento completamente
  offline. La nube nunca debe bloquear la instalación local.

## Contexto del kit

Kit mínimo:

- Dos LilyGO TTGO LoRa32 T3 V1.6.1 para 915 MHz.
- Una antena de 915 MHz por cada placa.
- Cables micro-USB de datos.
- Laptop macOS o Linux para el Centro.
- Un celular para abrir la red y el portal local del nodo.

Roles:

- **LoRa Maestro/Gateway:** recibe LoRa y se conecta por USB a la laptop del Centro.
- **LoRa Esclavo/Recurso:** crea una red Wi-Fi local, recibe misiones y devuelve confirmaciones.
- **Centro local:** aplicación Python, dashboard, mapa offline, SQLite y worker de sincronización.
- **Hub online:** onboarding y réplica sincronizada en Vercel/Supabase.

## Paso 1 — Obtener el proyecto

Primero pregunta qué sistema operativo usa y si ya tiene la carpeta del repositorio.

Si tiene Git:

```bash
git clone https://github.com/platanus-hack/platanus-hack-26-co-team-28.git
cd platanus-hack-26-co-team-28
```

Si no tiene Git, guíalo para descargar el ZIP desde GitHub, descomprimirlo y abrir una terminal en
la raíz. Antes de continuar, confirma que existen `hub/` y `lora-emergencia/`.

## Paso 2 — Entender la conexión

Resume antes del hardware:

1. El celular se conecta al Wi-Fi local del nodo.
2. El nodo transporta mensajes por LoRa 915 MHz sin usar internet.
3. El Gateway entrega esos mensajes por USB al Centro local.
4. Solo cuando hay internet, el Centro sincroniza una copia al Hub online.

Usa <https://lora.uprizing.me/> como apoyo visual, no como dependencia operacional.

## Paso 3 — Revisar el kit

Confirma visualmente modelo, frecuencia, antenas y cables. No conectes todavía las placas. Si el
modelo o la frecuencia no coinciden, detente y consulta `lora-emergencia/docs/HARDWARE.md`.

## Paso 4 — Conectar primero las antenas

Pide conectar manualmente una antena de 915 MHz a cada TTGO. Solo después autoriza conectar USB o
energía. No fuerces el SMA y no uses herramientas.

## Paso 5 — Preparar el Maestro y el Centro

Con la antena instalada y el Maestro conectado por USB, desde la raíz ejecuta:

```bash
bash lora-emergencia/scripts/instalar_maestro.sh
```

Este instalador está diseñado para una laptop limpia: prepara Arduino CLI, ESP32, librerías,
firmware del gateway y el entorno Python del Centro sin requerir Arduino IDE.

Ayuda a identificar el puerto si hay más de un dispositivo. No adivines la ruta serial. El
resultado correcto debe incluir:

- Gateway flasheado sin errores.
- Centro local iniciado.
- Dashboard disponible en <http://localhost:8080>.
- Base SQLite persistente y proceso de Centro activo.

## Paso 6 — Preparar el Esclavo de recurso

En otra terminal, con la antena instalada y la placa correcta conectada:

```bash
bash lora-emergencia/scripts/instalar_esclavo.sh
```

Guía la definición de:

- ID único del recurso, por ejemplo `GRUA07`.
- Tipo, por ejemplo `GRUA`.
- Zona, por ejemplo `NORTE`.

Nunca reutilices el mismo ID en dos placas activas. El instalador debe personalizar una copia
temporal y conservar intacto el firmware versionado.

Resultado esperado:

- Firmware de recurso flasheado.
- Red `RECURSO_<ID>` visible desde el celular.
- Nodo identificado en el Centro después de sus mensajes LoRa.

## Paso 7 — Abrir el portal local

Desde el celular:

1. Conectarse a `RECURSO_<ID>`.
2. Aceptar que la red no tiene internet.
3. Abrir <http://192.168.4.1> si el portal no aparece automáticamente.

No instales una app y no uses datos móviles para esta prueba.

## Paso 8 — Verificar el recorrido completo

Valida una misión real:

1. El Centro asigna una misión al recurso.
2. La misión viaja por LoRa y aparece en el celular.
3. “Aceptar misión” envía `ACC` por LoRa.
4. El Centro responde `ACK` y actualiza el estado.
5. Comprueba la transición operacional hasta resolución.

Usa los verificadores del repositorio cuando corresponda:

```bash
bash lora-emergencia/scripts/probar_portal.sh
```

No declares éxito solo porque una interfaz cargó: confirma el ida y vuelta entre nodo y Centro.

## Sincronización online opcional

La sincronización corre en la laptop del Centro. El worker lee la outbox SQLite, envía eventos por
HTTPS y reintenta automáticamente con espera creciente si no hay red.

Variables:

```bash
export WOKI_SYNC_URL='https://woki-hub.vercel.app/api/sync'
export WOKI_SYNC_TOKEN='SOLICITAR_POR_CANAL_PRIVADO'
```

No inventes ni imprimas el token. Consulta `docs/OPERAR-SINCRONIZACION.md` para iniciar el Centro
con sincronización y verificar la cola. La operación offline debe continuar aunque el Hub no
responda.

## Paso 9 — Extensión física opcional

Esta parte queda fuera de la instalación obligatoria de software y hardware electrónico. El visor
<https://woki-lora-enclosures.vercel.app> publica:

- 8 geometrías verificadas.
- 16 archivos STL + 3MF listos para descargar y laminar.
- Piezas para Centro, nodo de demo y bandeja de caja comercial.
- OpenSCAD, fabricación, abastecimiento y verificaciones pendientes.

No afirmes certificación de campo: antes del uso real se deben validar tolerancias, temperatura,
autonomía, radio y sellado contra el hardware físico.

## Diagnóstico mínimo

Si algo falla:

1. Identifica el paso exacto y conserva el primer error útil.
2. Confirma sistema operativo, ruta del repositorio y dispositivo conectado.
3. Verifica antena antes de cualquier repetición de flasheo.
4. Distingue entre error de herramienta, compilación, puerto serial, radio, portal, Centro o sync.
5. Consulta la fuente correspondiente antes de proponer cambios.
6. Aplica el cambio mínimo reversible y repite únicamente la comprobación afectada.

No conviertas un problema de sincronización online en un bloqueo de la red LoRa local.

## Fuentes obligatorias

Consulta estos archivos antes de improvisar:

- `lora-emergencia/docs/HARDWARE.md`
- `lora-emergencia/docs/SETUP.md`
- `lora-emergencia/center/TOOLCHAIN.md`
- `lora-emergencia/center/CENTRO.md`
- `lora-emergencia/docs/PROTOCOLO-MINIMO.md`
- `lora-emergencia/docs/PORTAL-CAUTIVO-E2E.md`
- `lora-emergencia/docs/PLAN-DEMO.md`
- `docs/ARQUITECTURA-CONEXIONES.md`
- `docs/OPERAR-SINCRONIZACION.md`
- `lora-emergencia/diseno-3d/README.md`
- `lora-emergencia/diseno-3d/IMPRESION.md`

Empieza con una sola pregunta: **¿Usas macOS o Linux y ya tienes descargada la carpeta WOKI?**

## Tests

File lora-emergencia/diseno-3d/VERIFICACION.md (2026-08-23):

# Verificación de suficiencia física

## Dictamen

La definición ya es **suficiente para comprar componentes y hacer la primera
iteración física completa**. Todavía no es correcto llamarla lista para campo:
faltan confirmaciones y ensayos sobre el hardware real.

La solución evita tres riesgos de la versión inicial:

1. La Raspberry deja de montarse como PCB expuesta: usa carcasa y ventilación.
2. El nodo de campo no depende de que una impresión FDM sea impermeable.
3. Batería, conectores y pasamuros tienen referencias y compatibilidad explícita.

## Archivos CAD

| Pieza | Malla | Dimensión | Próximo paso |
|---|---|---:|---|
| `pantalla_marco` | Manifold | 170 × 129 × 3,2 mm | Confirmar etiqueta/cotas de pantalla |
| `pantalla_pie` | Manifold | 54 × 46 × 16 mm | Imprimir 2 y probar estabilidad |
| `centro_bandeja` | Manifold | 168 × 76 × 10,65 mm | Probar carcasa RPi4 y TTGO |
| `centro_powerbank` | Manifold | 161,2 × 72,2 × 7 mm | Probar Baseus exacta |
| `nodo_base` | Manifold | 72,2 × 42,2 × 20,5 mm | Solo demo; probar encaje |
| `nodo_tapa` | Manifold | 72,2 × 42,2 × 4 mm | Solo demo; probar retención |
| `bateria_placa` | Manifold | 94 × 58 × 3 mm | Solo demo; probar correa |
| `nodo_bandeja_ip68` | Manifold | 106 × 75 × 5 mm | Probar dentro de Hammond |

Cada pieza tiene STL y 3MF. El pie se imprime dos veces: el kit contiene nueve
objetos físicos a partir de ocho geometrías.

## Centro maestro

| Necesidad | Solución definida | Estado |
|---|---|---|
| Sostener pantalla | Marco Waveshare + dos pies | CAD; pantalla candidata |
| Proteger Raspberry | Carcasa oficial RPi4 | Compra definida |
| Refrigerar | Ventilador oficial + disipador | Compra definida |
| Integrar gateway | Dock TTGO de bandeja | CAD |
| Energía portátil | Baseus 65 W / 20 Ah + cuna | CAD + compra definida |
| Cablear táctil/radio | Dos USB-A → micro-USB de datos | Topología definida |
| Evitar bajo voltaje | USB-C 5 V/3 A y prueba bajo carga | Ensayo pendiente |

**Bloqueo físico restante:** fotografiar la etiqueta trasera de la pantalla o
comprobar envolvente 164,9 × 124,27 mm y patrón 148,9 × 114,96 mm. Si no coincide,
solo se rediseña `pantalla_marco`; el resto del centro se conserva.

## Nodo de campo

| Necesidad | Solución definida | Estado |
|---|---|---|
| Alojar TTGO + batería | Bandeja interna separada | CAD |
| Proteger de lluvia | Hammond 1554F2GYCL IP68 | Compra definida |
| Proteger SMA | Pasamuros Amphenol IP67 | Compra definida |
| Energía segura | Pack 1S protegido | Dos opciones definidas |
| Adaptar conector | Pigtail GH 1,25 mm, empalme y multímetro | Procedimiento definido |
| Transportar/fijar | Accesorios/pies externos Hammond o correa | Elegir según el despliegue |
| Validar autonomía | Prueba con WiFi AP + LoRa | Pendiente |

La carcasa mantiene su IP solo si el pasamuros se instala y sella correctamente.
El conjunto modificado no hereda automáticamente la certificación del fabricante.

## Pruebas de aceptación

### Ajuste

1. Componentes entran sin forzar PCB, batería o conectores.
2. Ninguna correa comprime el pouch o pasa sobre un botón/puerto.
3. HDMI, USB y coaxial conservan radio de giro y alivio de tensión.
4. El equipo no se desprende al invertirlo y agitarlo manualmente.

### Eléctrica y térmica

1. Ejecutar dos horas con dashboard, pantalla, táctil y TTGO activos.
2. Registrar `vcgencmd measure_temp` cada 10 minutos.
3. Ejecutar `vcgencmd get_throttled`; el valor esperado es `0x0`.
4. Revisar `dmesg` por bajo voltaje, USB o desconexiones serie.
5. Completar un ciclo de batería real y registrar horas, no estimarlas.

### Radio y entorno

1. Confirmar antena conectada antes de cada transmisión.
2. Comparar RSSI/SNR con caja abierta y cerrada.
3. Probar el pasamuros tirando suavemente del cable, nunca del SMA de la PCB.
4. Hacer salpicadura solo con electrónica de ensayo y la caja cerrada.

## Criterio de “suficiente”

- **Para imprimir:** sí; ocho mallas manifold verificadas.
- **Para comprar:** sí; BOM con referencias y sustituciones aceptables.
- **Para demo interior:** sí, después de una impresión y prueba eléctrica.
- **Para campo:** todavía no; requiere ajuste, autonomía, temperatura, radio y
  sellado verificados físicamente.

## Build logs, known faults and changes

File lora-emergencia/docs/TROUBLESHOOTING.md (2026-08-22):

# TROUBLESHOOTING · Errores reales y sus soluciones

Estos son problemas que ya ocurrieron y cómo se resolvieron.

## La subida falla: "Unable to verify flash chip connection"

La subida conecta con el ESP32 pero falla al cambiar a 921600 baudios.

**Solución:** sube a 115200. Usa el FQBN con `UploadSpeed=115200`:

```bash
arduino-cli compile --upload -p <PUERTO> --fqbn esp32:esp32:ttgo-lora32:UploadSpeed=115200 <sketch>
```

Los scripts del repo ya lo hacen.

## El puerto no aparece

- Revisa que el cable sea **de datos**, no de solo carga.
- Instala el driver USB-serial si hace falta (ver SETUP.md).
- Prueba otro puerto USB.

## La subida falla al conectar

Mantén presionado el botón **BOOT** de la placa mientras empieza la subida. Suéltalo cuando veas "Writing...".

## El receptor no recibe nada

Esta es la falla nº1 de LoRa. Casi siempre es esto:

- Los 6 parámetros de `radio.begin()` NO coinciden entre las placas. Revisa freq, BW, SF, CR, sync, preámbulo. Deben ser idénticos.
- Una placa quedó en 868 y otra en 915.
- La antena no está enroscada (baja mucho el alcance, aunque de cerca a veces igual llega).

No hay mensaje de error cuando los parámetros no calzan. Simplemente no llega nada.

## La primera compilación tarda mucho

Es normal. La primera vez arma todo el core ESP32. Puede pasar de 2 minutos. Las siguientes compilaciones son rápidas. Si usas un timeout, corre la primera compilación en segundo plano.

## Leer el serial en macOS

`arduino-cli monitor` a veces no muestra nada al cerrarse rápido. Alternativa con `stty` + `cat`:

```bash
PORT=/dev/cu.usbserial-XXXX
stty -f "$PORT" 115200 raw -echo
cat "$PORT"
# Ctrl+C para salir
```

Al abrir el puerto puede aparecer texto basura: es el mensaje del bootloader de la ROM a otra velocidad. Ignóralo, lo importante son las líneas legibles.

## Tormenta de ACK / el gateway recibe su propio mensaje

Síntoma: el gateway imprime en bucle `RECV|ACK|ACK...` con un timestamp congelado, y el nodo nunca recibe el ACK.

Causa: mezclar recepción por interrupción (`setPacketReceivedAction` + `startReceive`) con `transmit()` bloqueante en la misma placa. Cuando la placa transmite, la interrupción de "TX terminado" dispara la misma bandera de "paquete recibido", y luego `readData()` lee de vuelta el propio FIFO de transmisión como si fuera un paquete nuevo. Eso crea un bucle de auto-respuesta.

Solución: no mezclar interrupción con `transmit()`. Usa el patrón BLOQUEANTE: `radio.transmit()` seguido de `radio.receive()`. Es lo que hacen `nodo_bidir` y `gateway_bidir` en este repo. Regla: en una placa half-duplex, o usas interrupciones para todo, o bloqueante para todo, pero no mezcles con `transmit()` de por medio.

## Resets intermitentes del gateway conectado a la Raspberry Pi

Los 4 puertos USB de la Pi 4B comparten 1.2 A. Si cuelgas varios aparatos, el gateway resetea.

- Usa la fuente de 3 A de la Pi.
- Si sigue, alimenta el gateway por un hub USB con energía propia, o dale corriente aparte.

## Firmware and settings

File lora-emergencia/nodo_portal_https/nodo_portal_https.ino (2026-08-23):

// NODO PORTAL HTTPS - MVP con ubicacion del telefono - TTGO LoRa32 T3 V1.6.1
// Usa el servidor HTTPS nativo del ESP-IDF (esp_https_server), compatible con core 3.x.
// WiFi abierto "AYUDA". HTTP :80 redirige a Safari/Chrome. HTTPS :443 con cert
// valido de ayuda.homiapp.xyz -> navigator.geolocation entrega el GPS real.
// Respaldo manual: Plus Code o direccion. El reporte viaja por LoRa 915 con ACK.
//
// Requiere: credentials.h (cert + clave, NO se sube a git).
#include <WiFi.h>
#include <DNSServer.h>
#include <RadioLib.h>
#include <esp_http_server.h>
#include <esp_https_server.h>
#include <Preferences.h>
#include <Wire.h>
#include <U8g2lib.h>
#include "credentials.h"

// OLED I2C del T3 V1.6.1 (SDA 21, SCL 22, 0x3C). Muestra el estado del punto de ayuda.
#define OLED_SDA 21
#define OLED_SCL 22
#define OLED_ADDR 0x3C
// Page-buffer (_1_): usa 128 bytes por pagina en vez de 1024 contiguos del full-buffer.
// Libera un bloque contiguo grande para que el handshake TLS no se quede sin RAM.
U8G2_SSD1306_128X64_NONAME_1_HW_I2C oled(U8G2_R0, U8X8_PIN_NONE, OLED_SCL, OLED_SDA);
bool tieneOled = false;
int enviados = 0;

bool detectarOled() {
  Wire.begin(OLED_SDA, OLED_SCL);
  Wire.beginTransmission(OLED_ADDR);
  return Wire.endTransmission() == 0;
}
// Muestra 3 lineas en la OLED del rescatista.
void oledMostrar(const String& l1, const String& l2, const String& l3) {
  if (!tieneOled) return;
  // Page-buffer: redibuja todo dentro del bucle firstPage/nextPage.
  oled.firstPage();
  do {
    oled.setFont(u8g2_font_ncenB10_tr);
    oled.drawStr(0, 14, l1.c_str());
    oled.setFont(u8g2_font_6x12_tr);
    oled.drawStr(0, 34, l2.c_str());
    oled.drawStr(0, 52, l3.c_str());
  } while (oled.nextPage());
}

// --- Pines LoRa (T3 V1.6.1) ---
#define LORA_SCK 5
#define LORA_MISO 19
#define LORA_MOSI 27
#define LORA_CS 18
#define LORA_RST 23
#define LORA_DIO0 26
#define LORA_DIO1 33
SX1276 radio = new Module(LORA_CS, LORA_DIO0, LORA_RST, LORA_DIO1);

const char* AP_SSID = "[AFECTADOS] RED DE AYUDA WOKI";  // 29 chars, limite softAP 32
const char* DOMAIN = "ayuda.homiapp.xyz";
IPAddress apIP(192, 168, 4, 1);
DNSServer dnsServer;
Preferences preferences;

// Direccionamiento estandar (frame: ORIGEN|DESTINO|TIPO|MSGID|payload...)
#define DST_CENTRO "CENTRO"
String NODE_ID = "a3f21c";
String NODE_LAT = "4.6767";
String NODE_LON = "-74.0483";
uint32_t seq = 0;
uint32_t activeSosSeq = 0;
bool hasActiveSos = false;

// ---- Loop bidireccional: recibir el estado que manda el centro ----
// El radio lo maneja SOLO loop() (un unico dueno) para no chocar con el envio.
// El task del servidor HTTPS ENCOLA el envio; loop() lo ejecuta y ademas escucha.
volatile bool rxFlag = false;             // la ISR marca que llego un paquete
void IRAM_ATTR onRx() { rxFlag = true; }
SemaphoreHandle_t txMtx = NULL;           // protege la cola de un solo envio
SemaphoreHandle_t reportMtx = NULL;       // serializa reportes HTTP/HTTPS completos
volatile bool txPend = false;             // hay un frame por enviar
volatile bool txDone = false;             // loop ya lo envio
volatile bool txOk = false;               // resultado del envio
String txMsg; uint32_t txId = 0;
char estadoBuf[24] = "-";                 // ultimo estado recibido del centro
unsigned long estadoAt = 0;               // millis del ultimo estado recibido

// ---------- utilidades ----------
String urldecode(String s) {
  String o; char c; int i;
  for (int k = 0; k < (int)s.length(); k++) {
    c = s[k];
    if (c == '+') o += ' ';
    else if (c == '%' && k + 2 < (int)s.length()) {
      i = strtol(s.substring(k + 1, k + 3).c_str(), NULL, 16);
      o += (char)i; k += 2;
    } else o += c;
  }
  return o;
}
String field(String body, String key) {
  int a = body.indexOf(key + "=");
  if (a < 0) return "";
  a += key.length() + 1;
  int b = body.indexOf('&', a);
  if (b < 0) b = body.length();
  return urldecode(body.substring(a, b));
}

// ---------- LoRa ----------
// Extrae el campo idx (0-based) de un string separado por '|'
String tok(const String& s, int idx) {
  int start = 0, count = 0;
  for (int i = 0; i <= (int)s.length(); i++) {
    if (i == (int)s.length() || s[i] == '|') {
      if (count == idx) return s.substring(start, i);
      count++;
      start = i + 1;
    }
  }
  return "";
}

// Procesa el estado de la solicitud activa enviado por el centro:
// CENTRO|<NODE_ID>|ST|<id>|<request_seq>|<estado>.
void procesarEntrante(const String& msg) {
  if (tok(msg, 1) == NODE_ID && tok(msg, 2) == "ST") {
    String requestSeq = tok(msg, 4);
    if (!hasActiveSos || requestSeq != String(activeSosSeq)) return;
    String est = tok(msg, 5);
    if (est.length() == 0) return;
    est.toCharArray(estadoBuf, sizeof(estadoBuf));
    estadoAt = millis();
    Serial.println("[NODO] estado del centro: " + est);
    oledMostrar("ACTUALIZACION", est, "puesto de mando");
  }
}

// Limpia un texto para que no rompa el formato '|' y lo corta a n caracteres.
// Presupuesto LoRa: un frame SOS con detalle=100 + lugar=40 queda en ~180 bytes,
// dentro del maximo de ~255 bytes de un paquete SX1276. Mas largo = mas tiempo
// en el aire y mas riesgo de colision, por eso se limita.
String sanN(String s, int n) {
  s.replace("|", " "); s.replace("\n", " "); s.replace("\r", " ");
  if ((int)s.length() > n) s = s.substring(0, n);
  return s;
}
String san(String s) { return sanN(s, 50); }

uint32_t nextSequence() {
  uint32_t id = seq++;
  preferences.putUInt("next_seq", seq);
  return id;
}

// Prioridad por defecto segun la categoria (0 = vida en riesgo)
String priDefault(String cat) {
  if (cat == "MEDICO" || cat == "RESCATE" || cat == "FUEGO") return "0";
  if (cat == "GRUA") return "1";
  return "3";
}

// Envio real del radio. SOLO se llama desde loop() (dueno unico del radio).
// CAD (listen-before-talk) + hasta 3 reintentos + espera de ACK dirigido. La
// espera del ACK usa la bandera de RX; si mientras tanto llega un estado del
// centro, lo procesa igual.
bool enviarConAck(String msg, uint32_t id) {
  bool acked = false;
  int intento = 0;
  while (!acked && intento < 3) {
    Serial.println("[NODO] TX (intento " + String(intento + 1) + "): " + msg);
    for (int i = 0; i < 6; i++) { if (radio.scanChannel() == RADIOLIB_CHANNEL_FREE) break; delay(random(20, 90)); }
    radio.standby();
    radio.transmit(msg);
    rxFlag = false;
    radio.startReceive();
    unsigned long t0 = millis();
    while (millis() - t0 < 1000 && !acked) {
      if (rxFlag) {
        rxFlag = false;
        String in;
        if (radio.readData(in) == RADIOLIB_ERR_NONE) {
          // ACK dirigido: CENTRO|<mi_id>|ACK|<msgid>
          if (tok(in, 1) == NODE_ID && tok(in, 2) == "ACK" && tok(in, 3) == String(id)) acked = true;
          else procesarEntrante(in);   // pudo llegar un estado mientras esperabamos el ACK
        }
        radio.startReceive();
      }
      delay(2);
    }
    if (!acked) { intento++; delay(random(100, 500)); }
  }
  Serial.println(acked ? "[NODO] ACK OK (id " + String(id) + ")" : "[NODO] sin ACK tras 3 intentos");
  if (acked) enviados++;
  oledMostrar(acked ? "ENVIADO OK" : "REENVIANDO...",
              "id " + String(id) + (acked ? "  confirmado" : "  sin ACK"),
              "reportes: " + String(enviados));
  radio.startReceive();                 // vuelve a escuchar al centro
  return acked;
}

// Llamado desde el task del servidor HTTPS. Encola el envio y espera a que
// loop() (dueno del radio) lo ejecute. Asi dos tasks nunca tocan el radio a la vez.
bool enviarFrame(String msg, uint32_t id) {
  xSemaphoreTake(txMtx, portMAX_DELAY);
  txMsg = msg; txId = id; txOk = false; txDone = false; txPend = true;
  xSemaphoreGive(txMtx);
  unsigned long t0 = millis();
  while (!txDone && millis() - t0 < 8000) delay(10);
  return txOk;
}

// SOS: pedir ayuda. Frame: ORIGEN|CENTRO|SOS|MSGID|cat|pri|lat|lon|lugar|detalle
bool enviarSOS(String cat, String pri, String lat, String lon, String lugar, String detalle) {
  xSemaphoreTake(reportMtx, portMAX_DELAY);
  lugar = sanN(lugar, 40); detalle = sanN(detalle, 100);
  if (pri.length() == 0) pri = priDefault(cat);
  if (lugar.length() == 0) lugar = "-";
  if (detalle.length() == 0) detalle = "-";
  uint32_t id = nextSequence();
  activeSosSeq = id;
  hasActiveSos = true;
  preferences.putUInt("active_sos", activeSosSeq);
  preferences.putBool("has_sos", true);
  strlcpy(estadoBuf, "-", sizeof(estadoBuf));
  estadoAt = 0;
  String msg = NODE_ID + "|" DST_CENTRO "|SOS|" + String(id) + "|" +
               cat + "|" + pri + "|" + lat + "|" + lon + "|" + lugar + "|" + detalle;
  bool sent = enviarFrame(msg, id);
  xSemaphoreGive(reportMtx);
  return sent;
}

// OK: reportarse a salvo con datos identificables.
// Frame: ORIGEN|CENTRO|OK|MSGID|nombre|doc|lat|lon|lugar
bool enviarOK(String nombre, String doc, String lat, String lon, String lugar) {
  xSemaphoreTake(reportMtx, portMAX_DELAY);
  nombre = san(nombre); doc = san(doc); lugar = san(lugar);
  if (lugar.length() == 0) lugar = "-";
  uint32_t id = nextSequence();
  String msg = NODE_ID + "|" DST_CENTRO "|OK|" + String(id) + "|" +
               nombre + "|" + doc + "|" + lat + "|" + lon + "|" + lugar;
  bool sent = enviarFrame(msg, id);
  xSemaphoreGive(reportMtx);
  return sent;
}

// ---------- pagina HTTPS ----------
#include "portal_page.h"

// Estilos compartidos
static const char* CSS =
  "body{font-family:-apple-system,Arial,sans-serif;margin:0;color:#111}"
  ".wrap{max-width:520px;margin:0 auto;padding:16px}"
  ".hdr{background:#d92d20;color:#fff;padding:16px;border-radius:0 0 12px 12px;text-align:center}"
  ".hdr h1{margin:0;font-size:22px}.hdr p{margin:4px 0 0;font-size:13px;opacity:.95}"
  "label{display:block;font-weight:700;margin:14px 0 6px}"
  "input{width:100%;padding:14px;font-size:16px;border:2px solid #ccc;border-radius:10px;box-sizing:border-box}"
  "button{width:100%;padding:18px;font-size:19px;font-weight:700;border:0;border-radius:12px;margin-top:10px;color:#fff}"
  ".b1{background:#1570ef}.b2{background:#d92d20}.b3{background:#b42318}.b4{background:#067647}"
  "a.gps{display:block;background:#111;color:#fff;padding:16px;font-size:16px;font-weight:700;border-radius:12px;text-decoration:none;text-align:center;margin-top:18px}"
  ".ok{background:#ecfdf3;border:2px solid #067647;color:#054f31;padding:16px;border-radius:12px;font-size:17px}"
  ".warn{background:#fffaeb;border:2px solid #b54708;color:#7a2e0e;padding:16px;border-radius:12px;font-size:17px}"
  ".note{font-size:12px;color:#666;margin-top:14px;text-align:center}";

// Portal cautivo (HTTP). Android y escritorio se van al dominio HTTPS, donde el
// GPS si funciona. iOS se queda aqui, y aqui PIDE AYUDA, sin GPS.
//
// Por que iOS no puede dar GPS en esta pantalla:
// WebKit bloquea navigator.geolocation en el motor cuando el origen no es
// seguro. Geolocation::shouldBlockGeolocationRequests() exige https/wss,
// loopback o file:; una IP privada como 192.168.4.1 no califica, y el CNA de
// Apple carga esta pagina por HTTP plano. Devuelve PERMISSION_DENIED sin
// mostrar ningun permiso. No hay rodeo.
// (WebKit r200686, bug 157423, 11-may-2016; W3C Geolocation, "request a position")
//
// Por eso el orden es: ACCION PRIMERO, instrucciones despues.
//  - El CNA se cierra al cambiar de app: decirle a alguien "abre Safari" le
//    borra la sesion. Si no pudo pedir ayuda antes, se queda sin pedir.
//  - NN/g (2018): el 42% del tiempo de vista cae en el 20% superior de la
//    pagina. Gastar esa franja en instrucciones es gastar la atencion escasa.
//  - El titulo va como texto, NO como barra roja. NN/g: "no hagas que
//    elementos no clicables parezcan botones; darle color de fondo a un
//    titulo lo hace parecer boton". El rojo queda como tinta y borde.
//  - El envio es un POST de formulario de verdad, con navegacion completa:
//    el CNA solo revisa la conectividad tras una navegacion real, nunca tras
//    un AJAX (Wireless Broadband Alliance).
// Limite duro del CNA: 128 KB en el HTML inicial y cero recursos externos.
// Esta pagina es de ~4 KB, todo inline.
String pageHttp() {
  String https = "https://" + String(DOMAIN) + "/";
  String intent = "intent://" + String(DOMAIN) + "/#Intent;scheme=https;package=com.android.chrome;S.browser_fallback_url=" + https + ";end";
  String h = "<!doctype html><html lang='es'><head><meta charset='utf-8'>";
  h += "<meta name='viewport' content='width=device-width,initial-scale=1'>";
  h += "<title>Punto de ayuda 911</title><style>";
  h += "*{box-sizing:border-box}body{margin:0;background:#0C0C0D;color:#F1F3F4;font:16px/1.5 system-ui,-apple-system,sans-serif}";
  h += ".w{max-width:440px;margin:0 auto;min-height:100vh;padding:20px 16px 28px;display:flex;flex-direction:column}";
  // Titulo: tinta roja y borde a la izquierda. Sin relleno y sin esquinas
  // redondeadas, que son las 2 senales que lo hacian parecer boton.
  h += "h1{margin:0;font-size:21px;font-weight:800;letter-spacing:-.01em;color:#FF6B60;";
  h += "border-left:4px solid #FF4438;padding-left:12px;text-align:left;cursor:default;-webkit-tap-highlight-color:transparent}";
  h += ".sub{color:#9AA0A6;font-size:14px;margin:8px 0 0;padding-left:16px}";
  h += ".lead{font-size:17px;font-weight:700;margin:26px 0 12px}";
  h += ".cats{display:grid;grid-template-columns:1fr 1fr;gap:10px;margin:0;padding:0;border:0}";
  // Los 5 botones son la accion. Superficie neutra con borde, igual que el
  // portal HTTPS, para que la persona reconozca la misma pantalla despues.
  h += ".cat{-webkit-appearance:none;appearance:none;font:inherit;border:1.5px solid #2E3033;background:#161719;color:#F1F3F4;";
  h += "border-radius:16px;padding:15px 10px;min-height:104px;display:flex;flex-direction:column;align-items:center;justify-content:center;gap:8px;";
  h += "text-align:center;font-weight:700;font-size:14.5px;cursor:pointer}";
  h += ".cat:active{transform:scale(.98);border-color:#4C9AFF}";
  h += ".cat:focus-visible{outline:3px solid #4C9AFF;outline-offset:3px}";
  h += ".cat svg{width:30px;height:30px}";
  h += ".cat.sel{border-color:#4C9AFF;background:#1B2432;box-shadow:0 0 0 1.5px #4C9AFF inset}";
  h += ".cat .fa{width:32px;height:32px;border-radius:7px;background:#2FBF71;display:grid;place-items:center}.cat .fa svg{width:20px;height:20px;color:#fff}";
  h += ".wide{grid-column:1/-1}";
  // Detalle opcional: subtipo, mensaje y lugar escrito. Alimentan el triage.
  h += ".lab{font-size:12px;font-weight:800;letter-spacing:.06em;text-transform:uppercase;color:#9AA0A6;margin:20px 0 8px}";
  h += ".chips{display:flex;flex-wrap:wrap;gap:8px}";
  h += ".chip{-webkit-appearance:none;appearance:none;font:inherit;background:#161719;border:1.5px solid #2E3033;color:#F1F3F4;";
  h += "border-radius:20px;padding:10px 14px;min-height:44px;font-size:14px;font-weight:600;cursor:pointer}";
  h += ".chip.sel{border-color:#4C9AFF;background:#1B2432;color:#fff}";
  h += ".chip:active{transform:scale(.98)}.chip:focus-visible{outline:3px solid #4C9AFF;outline-offset:3px}";
  // 16px es el minimo: por debajo, iOS hace auto-zoom y rompe el layout.
  h += ".txt{width:100%;background:#161719;border:1.5px solid #2E3033;color:#F1F3F4;border-radius:13px;";
  h += "padding:13px 14px;font:16px/1.45 inherit;margin-top:10px}";
  h += ".txt:focus{outline:none;border-color:#4C9AFF}";
  h += "textarea.txt{min-height:76px;resize:vertical}";
  // El GPS es una mejora opcional y va PLEGADO, debajo de la accion.
  h += "details{margin-top:22px;background:#161719;border:1.5px solid #2E3033;border-radius:13px;padding:2px 14px}";
  h += "summary{padding:13px 0;font-size:14.5px;font-weight:700;color:#4C9AFF;cursor:pointer;min-height:44px;display:flex;align-items:center}";
  h += ".step{border-top:1px solid #2E3033;padding:11px 0;font-size:13.5px;color:#C9CCCE}.step b{color:#4C9AFF}";
  h += ".sp{flex:1}";
  h += ".go{display:block;width:100%;-webkit-appearance:none;appearance:none;border:0;background:#FF4438;color:#fff;padding:20px;";
  h += "border-radius:18px;text-decoration:none;text-align:center;font-family:inherit;font-weight:800;font-size:19px;min-height:56px;margin-top:22px;cursor:pointer}";
  h += ".go small{display:block;font-weight:500;font-size:13px;opacity:.95;margin-top:4px}";
  h += ".go:active{transform:scale(.99)}.go:focus-visible{outline:3px solid #fff;outline-offset:3px}";
  h += ".msg{color:#9AA0A6;text-align:center;margin:18px 0;font-size:15px}";
  h += "@media (prefers-reduced-motion: reduce){.cat:active{transform:none}}";
  h += "</style></head><body><div class='w'>";
  h += "<h1>Punto de ayuda 911</h1>";
  h += "<div class='sub'>Estás conectado. No necesitas internet.</div>";

  // ---- iOS: pedir ayuda AQUI MISMO, sin GPS ----
  // Mismos 2 pasos que el portal HTTPS: situacion, y luego detalle opcional.
  // Un intento anterior mandaba el SOS con el primer toque, de un solo paso.
  // Salia mas rapido, pero perdia el subtipo y el mensaje, que son justo lo
  // que alimenta el triage del centro. Y aqui pesa mas todavia: sin GPS, el
  // texto del lugar es la unica pista de donde esta la persona.
  h += "<div id='ios' hidden>";
  h += "<div class='lead'>¿Qué está pasando?</div>";
  h += "<form method='POST' action='/report' id='f'>";
  h += "<input type='hidden' name='accion' value='sos'>";
  h += "<input type='hidden' name='cat' id='cat' value=''>";
  h += "<div class='cats' id='cats'>";
  h += "<button type='button' class='cat' data-cat='RESCATE'><svg viewBox='0 0 24 24' fill='none' stroke='currentColor' stroke-width='1.7'><circle cx='12' cy='7' r='3'/><path d='M5.5 21c0-4 2.9-6.5 6.5-6.5s6.5 2.5 6.5 6.5'/></svg><span>Persona atrapada</span></button>";
  h += "<button type='button' class='cat' data-cat='MEDICO'><span class='fa'><svg viewBox='0 0 24 24' fill='currentColor'><path d='M9 3h6v6h6v6h-6v6H9v-6H3V9h6z'/></svg></span><span>Persona herida</span></button>";
  h += "<button type='button' class='cat' data-cat='FUEGO'><svg viewBox='0 0 24 24' fill='none' stroke='currentColor' stroke-width='1.7'><path d='M12 2c1 3-2 4-2 7a2 2 0 0 0 4 0c2 2 3 3.5 3 6a5 5 0 0 1-10 0c0-3 3-4 5-13z'/></svg><span>Incendio</span></button>";
  h += "<button type='button' class='cat' data-cat='AGUA'><svg viewBox='0 0 24 24' fill='none' stroke='currentColor' stroke-width='1.8'><path d='M12 2s6.5 7 6.5 11.5a6.5 6.5 0 0 1-13 0C5.5 9 12 2 12 2z'/></svg><span>Inundación</span></button>";
  h += "<button type='button' class='cat wide' data-cat='GRUA'><svg viewBox='0 0 24 24' fill='none' stroke='currentColor' stroke-width='1.7'><path d='M3 17h13v-4l4 1v3h1M5 17a2 2 0 1 0 4 0 2 2 0 0 0-4 0zM16 17a2 2 0 1 0 4 0 2 2 0 0 0-4 0zM3 13V8h7l3 3'/></svg><span>Vía o vehículo bloqueado</span></button>";
  h += "</div>";
  h += "<div id='det' hidden>";
  h += "<div class='lab'>Detalle (opcional)</div>";
  h += "<div class='chips' id='chips'></div>";
  h += "<textarea class='txt' name='detalle' id='msg' maxlength='100' placeholder='Escribe un mensaje para el puesto de mando (opcional)'></textarea>";
  h += "<div class='lab'>¿Dónde estás? (opcional)</div>";
  h += "<input class='txt' name='lugar' id='lugar' maxlength='60' placeholder='Ej: Cra 12 # 4-30, o un punto conocido'>";
  h += "<button class='go' type='submit' id='send'>Pedir ayuda</button>";
  h += "</div></form>";
  h += "<details><summary>Mandar también mi ubicación GPS (opcional)</summary>";
  h += "<div class='step'>Esta pantalla de iPhone no puede leer el GPS. Pide ayuda arriba primero: llega igual.</div>";
  h += "<div class='step'><b>1.</b> Toca <b>Cancelar</b> arriba a la derecha.</div>";
  h += "<div class='step'><b>2.</b> Elige <b>Usar sin conexión</b>.</div>";
  h += "<div class='step'><b>3.</b> Abre <b>Safari</b> y entra a <b>" + String(DOMAIN) + "</b></div>";
  h += "</details></div>";
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
void loop() {
  dnsServer.processNextRequest();

  // Comando de prueba por serial: "SOS" o "SOS|GRUA|carro volcado".
  if (Serial.available()) {
    String cmd = Serial.readStringUntil('\n'); cmd.trim();
    if (cmd.startsWith("SOS")) enviarSosPrueba(tok(cmd, 1), tok(cmd, 2));
  }

  // 1. Si el servidor HTTPS encolo un envio, loop() lo ejecuta (dueno del radio).
  if (txPend) {
    xSemaphoreTake(txMtx, portMAX_DELAY);
    String msg = txMsg; uint32_t id = txId; txPend = false;
    xSemaphoreGive(txMtx);
    txOk = enviarConAck(msg, id);
    txDone = true;
  }
  // 2. Llego un frame del centro con el estado de mi solicitud.
  if (rxFlag) {
    rxFlag = false;
    String in;
    if (radio.readData(in) == RADIOLIB_ERR_NONE) procesarEntrante(in);
    radio.startReceive();
  }

  // Diagnostico de heap: si baja mucho, el handshake TLS resetea la conexion.
  if (millis() - lastDiag > 3000) {
    lastDiag = millis();
    Serial.print("[DIAG] heap="); Serial.print(ESP.getFreeHeap());
    Serial.print(" maxblock="); Serial.print(ESP.getMaxAllocHeap());
    Serial.print(" clientes="); Serial.println(WiFi.softAPgetStationNum());
  }
  delay(5);
}

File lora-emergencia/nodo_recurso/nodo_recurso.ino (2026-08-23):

// NODO RECURSO - TTGO LoRa32 T3 V1.6.1 (SX1276, 915 MHz)
// Recibe DISP y BC continuamente, los muestra en http://192.168.4.1 y permite
// aceptar/cambiar estado. Configure RESOURCE_ID/TYPE/ZONE antes de flashear.
#include <WiFi.h>
#include <WebServer.h>
#include <RadioLib.h>
#include "portal_assets.h"

#define LORA_SCK 5
#define LORA_MISO 19
#define LORA_MOSI 27
#define LORA_CS 18
#define LORA_RST 23
#define LORA_DIO0 26
#define LORA_DIO1 33

#define CENTER_ID "CENTRO"
#define BROADCAST "BCAST"

const char* RESOURCE_ID = "GRUA07";
const char* RESOURCE_TYPE = "GRUA";
String RESOURCE_ZONE = "NORTE";

SX1276 radio = new Module(LORA_CS, LORA_DIO0, LORA_RST, LORA_DIO1);
WebServer server(80);
volatile bool packetReceived = false;
volatile bool receiveInterruptEnabled = true;

long nextMessageId = 1;
unsigned long lastHeartbeat = 0;
String requestOrigin, requestSeq, requestCategory, requestPriority;
String requestLat, requestLon, requestPlace, requestDetail;
String assignmentState = "SIN_ASIGNACION";
String broadcastText, broadcastPriority, broadcastId;
unsigned long broadcastAckAt = 0;

void onPacketReceived() {
  if (receiveInterruptEnabled) packetReceived = true;
}

String field(const String& value, int index) {
  int start = 0, count = 0;
  for (int i = 0; i <= (int)value.length(); i++) {
    if (i == (int)value.length() || value[i] == '|') {
      if (count == index) return value.substring(start, i);
      count++;
      start = i + 1;
    }
  }
  return "";
}

String clean(String value) {
  value.replace("|", " "); value.replace("\n", " "); value.replace("\r", " ");
  if (value.length() > 80) value = value.substring(0, 80);
  return value;
}

void startListening() {
  packetReceived = false;
  receiveInterruptEnabled = true;
  radio.setPacketReceivedAction(onPacketReceived);
  radio.startReceive();
}

int transmitFrame(String frame) {
  receiveInterruptEnabled = false;
  radio.clearPacketReceivedAction();
  packetReceived = false;
  radio.standby();
  for (int attempt = 0; attempt < 6; attempt++) {
    if (radio.scanChannel() == RADIOLIB_CHANNEL_FREE) break;
    delay(random(20, 90));
  }
  int state = radio.transmit(frame);
  startListening();
  return state;
}

bool sendReliable(String kind, String payload) {
  long messageId = nextMessageId++;
  String frame = String(RESOURCE_ID) + "|" CENTER_ID "|" + kind + "|" + String(messageId);
  if (payload.length()) frame += "|" + payload;
  for (int attempt = 0; attempt < 3; attempt++) {
    if (transmitFrame(frame) != RADIOLIB_ERR_NONE) continue;
    unsigned long started = millis();
    while (millis() - started < 1200) {
      if (!packetReceived) { delay(2); continue; }
      receiveInterruptEnabled = false;
      packetReceived = false;
      String incoming;
      int state = radio.readData(incoming);
      if (state == RADIOLIB_ERR_NONE && field(incoming, 0) == CENTER_ID &&
          field(incoming, 1) == RESOURCE_ID && field(incoming, 2) == "ACK" &&
          field(incoming, 3) == String(messageId)) {
        startListening();
        return true;
      }
      startListening();
    }
    delay(random(100, 500));
  }
  return false;
}

void acknowledgeDownlink(const String& messageId) {
  transmitFrame(String(RESOURCE_ID) + "|" CENTER_ID "|ACK|" + messageId);
}

void handleRadioPacket() {
  if (!packetReceived) return;
  receiveInterruptEnabled = false;
  packetReceived = false;
  String frame;
  int state = radio.readData(frame);
  if (state != RADIOLIB_ERR_NONE) { startListening(); return; }

  String origin = field(frame, 0), destination = field(frame, 1);
  String kind = field(frame, 2), messageId = field(frame, 3);
  bool addressed = destination == RESOURCE_ID;
  bool broadcast = destination == BROADCAST;
  if (origin != CENTER_ID || (!addressed && !broadcast)) { startListening(); return; }

  if (kind == "DISP" && addressed) {
    // CENTRO|recurso|DISP|id|req_origin|req_seq|lat|lon|lugar|cat|pri|detalle
    requestOrigin = field(frame, 4); requestSeq = field(frame, 5);
    requestLat = field(frame, 6); requestLon = field(frame, 7);
    requestPlace = field(frame, 8); requestCategory = field(frame, 9);
    requestPriority = field(frame, 10); requestDetail = field(frame, 11);
    assignmentState = "PENDIENTE_ACEPTAR";
    acknowledgeDownlink(messageId);
    Serial.println("[RECURSO] despacho recibido " + requestOrigin + "/" + requestSeq);
    return;
  }

  if (kind == "BC" && broadcast) {
    // CENTRO|BCAST|BC|id|scope|priority|expiry|message
    String scope = field(frame, 4);
    if (scope == "ALL" || scope == "ZONE:" + RESOURCE_ZONE) {
      broadcastId = messageId;
      broadcastPriority = field(frame, 5);
      broadcastText = clean(field(frame, 7));
      // Confirmacion escalonada: evita que todos respondan al mismo tiempo.
      broadcastAckAt = millis() + random(300, 2500);
      Serial.println("[RECURSO] broadcast: " + broadcastText);
    }
  }
  startListening();
}

String jsonEscape(String value) {
  value.replace("\\", "\\\\"); value.replace("\"", "\\\"");
  value.replace("\n", " "); value.replace("\r", " ");
  return value;
}

void handleState() {
  String assignmentId = requestOrigin.length() && requestSeq.length()
    ? requestOrigin + ":" + requestSeq : "";
  String json = "{\"resource\":\"" + String(RESOURCE_ID) + "\",\"type\":\"" + RESOURCE_TYPE +
    "\",\"zone\":\"" + RESOURCE_ZONE + "\",\"assignmentState\":\"" + assignmentState +
    "\",\"assignmentId\":\"" + jsonEscape(assignmentId) +
    "\",\"requestOrigin\":\"" + jsonEscape(requestOrigin) + "\",\"requestSeq\":\"" + requestSeq +
    "\",\"category\":\"" + requestCategory + "\",\"priority\":\"" + requestPriority +
    "\",\"place\":\"" + jsonEscape(requestPlace) + "\",\"detail\":\"" + jsonEscape(requestDetail) +
    "\",\"broadcastId\":\"" + jsonEscape(broadcastId) +
    "\",\"broadcast\":\"" + jsonEscape(broadcastText) + "\",\"broadcastPriority\":\"" + broadcastPriority + "\"}";
  server.send(200, "application/json", json);
}
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

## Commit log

2026-08-22 Migra el proyecto lora-emergencia al repo del team + metadata de submission
    - Codigo, firmware y docs en lora-emergencia/ (enlace LoRa 915 con ACK, portal
    cautivo AYUDA, GPS por HTTPS, tablero del centro). Verificado en hardware.
    - Llena project-description.md y platanus-hack-project.jsonc (falta deploy-url).
    - credentials.h (clave privada) queda fuera por .gitignore.
    Claude-Session: https://claude.ai/code/session_01QRQW731hmdqziN4M8bXQqZ
2026-08-22 docs: OSS reutilizable + protocolo de mensajes + presupuesto de payload
    Research de repos OSS por valor/aplicabilidad para no reinventar la mensajeria.
    Veredicto: seguir con RadioLib y copiar el patron RHReliableDatagram (~40-60 lineas)
    para addressing+ACK+dedup, manteniendo el string '|' con un campo dst. Incluye
    tabla de cadenas literales por mensaje (bytes + airtime) y presupuesto de payload.
    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
2026-08-22 Protocolo minimo + firmware direccionado + tablero del centro
    - Frame estandar ORIGEN|DESTINO|TIPO|MSGID en todos los firmwares.
    - SOS con categoria + prioridad (0=vida) + GPS o nombre de lugar.
    - OK "estoy a salvo" con datos identificables (nombre + documento) para familia.
    - Gateway CENTRO: filtro por destino, ACK dirigido, anti-duplicados, decode SOS/OK.
    - CAD (listen-before-talk) para no perder mensajes con muchos usuarios.
    - Nodo rescatista: SoftAP AYUDA_AQUI_RESCATISTA_911, portal cautivo que redirige
    cualquier pagina a https://ayuda.homiapp.xyz (302) y pide GPS.
    - center.py: cola priorizada, maquina de estados (despacho/aceptar/resolver),
    lista de personas a salvo buscable por nom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
    [center.py, gateway_bidir.ino, nodo_bidir.ino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]
2026-08-22 Fix GPS en Android + entrada de despacho + guia del centro (CENTRO.md)
    - Portal: boton "Abrir en Chrome" (intent://) para Android. El WebView del portal
    cautivo bloquea navigator.geolocation; el popup solo sale en Chrome sobre HTTPS.
    Se quita el auto-redirect 302, que atrapaba a Android en el WebView.
    - Gateway: acepta "TX|<frame>" por USB y lo transmite por LoRa, para que el centro
    despache desde Python sin tocar firmware.
    - center/CENTRO.md: guia de handoff para construir el modulo del centro (interfaz
    serial in/out, modelo de datos, maquina de estados, API, roadmap).
    Claude-Session: https://claude.ai/code/session_01QRQW731hm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
    [gateway_bidir.ino, nodo_portal_https.ino]
2026-08-22 Feed "Red LoRa en vivo" en el command center
    Muestra en pantalla cada mensaje LoRa que cruza el centro: rescatista -> centro,
    centro -> recurso (operador) y de vuelta. Roles legibles, hora, direccion y tipo
    (SOS, ACK, DISP, STATUS, POS, HB, BC).
    Construido solo sobre el wire format que el gateway ya emite (RX|, ACK|, TX_SENT|,
    RX_DUPLICATE|). No toca el firmware ni command_core.py. En demo, el dispatch/broadcast
    registran el TX cuando el gateway no emite TX_SENT.
    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
2026-08-23 Prueba de alcance: firmware range_movil + RSSI en el feed en vivo
    - range_movil/: firmware para la placa que se camina. Ping automatico al CENTRO
    cada 900 ms, espera ACK, parpadea LED (GPIO25) y reporta RSSI. Sin ACK = fuera
    de rango.
    - center.py: el feed "Red LoRa en vivo" ahora muestra el RSSI de cada mensaje y
    tolera tipos que el store no maneja (ej PING). Asi el feed sirve de instrumento
    de rango: se ve el RSSI caer hasta que los pings dejan de llegar.
    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
2026-08-23 Portal HTTPS abre solo (302 en sondeos) SIN perder GPS ni features
    Aplica al firmware avanzado la apertura automatica del portal cautivo que estaba
    solo en nodo_portal.ino, sumando features en vez de reemplazar:
    - Sondeos Android/Windows (generate_204, gen_204, ncsi.txt, connecttest.txt) ->
    302 Location a la landing. El telefono ABRE el portal solo.
    - iOS y demas rutas -> landing 200 (el CNA de Apple la muestra sola).
    - Se conservan: GPS por HTTPS + boton Abrir en Chrome, SOS con categoria/prioridad,
    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
2026-08-23 Range test con OLED: la placa movil muestra RSSI y estado del enlace en pantalla
    - range_movil ahora usa la OLED del T3 (U8g2, SSD1306 128x64, I2C SDA21/SCL22).
    Muestra LINK OK / SIN LINK, RSSI, SNR y contador de exito ok X/Y.
    - Detecta el OLED por I2C antes de usarlo: si la placa no lo trae, sigue por serial
    sin colgarse.
    - Permite medir el alcance en campo SIN laptop, mirando solo la pantalla.
    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
2026-08-23 OLED en el gateway CENTRO: muestra estado y RSSI del ultimo mensaje
    Aditivo, no toca la logica del radio ni el wire format (RX|, ACK|, TX_SENT|
    siguen igual, center.py no se afecta). Detecta el OLED por I2C; si no hay, sigue
    por serial. Pantalla: CENTRO, estado, ultimo origen/tipo, RSSI y contador de msgs.
    Ahora las dos placas (movil y centro) muestran RSSI en su OLED para la prueba de
    alcance.
    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
2026-08-23 Simulador del operador de grua (vista /grua) sin 3ra placa
    - Nueva vista /grua: app del operador estilo Uber. Conectar en servicio, ver la
    solicitud asignada, Aceptar, Voy en camino, Llegue, Resuelto.
    - Endpoints /api/grua/connect|accept|status inyectan frames HB/ACC/ST via
    STORE.ingest, igual que haria el nodo_recurso real por LoRa. Aparecen en el feed
    de radio como GRUA07 -> CENTRO.
    - /api/dispatch: fallback SIM_DELIVERED cuando el recurso simulado esta conectado,
    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
2026-08-23 Plan del demo: guion 3 min, pantallas priorizadas y plan B
    Setup 2 placas + grua simulada. Prioriza pantallas para wow + claridad (dashboard
    + /grua protagonistas, celular de entrada, OLED como prueba fisica). Guion minuto
    a minuto, plan B por si el portal falla, checklist y reparto de roles.
    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
2026-08-23 Investigacion: voz por navegador -> texto corto -> LoRa, y features edge
    Veredicto: la transcripcion corre en el navegador del celular (Web Speech API
    on-device en Chrome 139+, Vosk-browser es-small ~39MB de respaldo offline), nunca
    en el ESP32 (sin RAM para Whisper). Esquema hibrido para texto por LoRa: plantilla
    + slots binarios + Unishox2 (frase de 116 B baja a ~11 B). Roadmap de features edge:
    triage por reglas, de-duplicacion por hash, prioridad en 1 byte, foto->etiqueta.
    Recomendacion demo: boton "Dictar" en el portal que llena el slot detalle del SOS,
    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
2026-08-23 Portal del ciudadano rediseñado segun estandares + fix de feedback de ubicacion
    Rediseño del portal siguiendo pantallas-auxilio.html (WCAG 2.2 AAA, ISO 3864/7010,
    CAP, USWDS, plain language): dark, botones >=104px, contraste 7:1, color normado,
    pictogramas, lenguaje simple. El ciudadano no ve jerga; el backend arma el frame SOS.
    FIX del bug reportado: ahora muestra la ubicacion GPS capturada (lat, lon, exactitud)
    en "Tu ubicacion" antes de enviar, y en la confirmacion "Esto fue lo que enviamos por
    radio". Igual para "Estoy bien" (nombre + documento + ubicacion).
    Validado e2e en Chrome: flujo SOS (cat/pri correctos: Extremo->0, Rescate) y flujo OK.
    Es portal_preview.html standalone; falta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
2026-08-23 Landing HTTP auto-redirige al portal HTTPS rediseñado (con GPS)
    Antes: la landing HTTP mostraba diseño viejo y no llevaba a ayuda.homiapp.xyz
    (el 302 apuntaba a la misma landing). El usuario no veia el UI nuevo ni el GPS.
    Ahora la landing es una pagina de transicion dark coherente que auto-redirige
    (meta refresh + location.replace) a https://ayuda.homiapp.xyz/, donde vive el
    portal rediseñado con captura de GPS. Boton grande de respaldo + intent a Chrome
    para Android. En Chrome real el salto es casi instantaneo.
    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
    [nodo_portal_https.ino]
2026-08-23 fix(center): adapt dashboard to Raspberry kiosk display
2026-08-23 Fix connection reset (RAM del TLS) + SoftAP robusto + validador e2e del portal
    Diagnostico con prints de heap: al conectar el celular, el bloque contiguo caia
    de 110KB a 42KB y no se recuperaba; Chrome/Safari abren varias conexiones HTTPS
    y el handshake TLS (~40KB c/u) agotaba el heap -> connection reset.
    - HTTPS: max_open_sockets=2 + lru_purge_enable (limita handshakes TLS concurrentes
    y purga el socket mas viejo en vez de rechazar).
    - SoftAP: max 8 clientes + eventos WiFi (STACONNECTED/STAIPASSIGNED) para confirmar
    asociacion y DHCP. Verificado: el celular obtiene IP (DHCP OK).
    - scripts/validar_portal.py: validador e2e (stdlib) de los sondeos de captive portal
    Android/iOS/Windows c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
    [nodo_portal_https.ino, validar_portal.py]
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2026-08-23 Estabiliza HTTPS del portal rescatista para el GPS (Camino A)
    Tres fixes para que el handshake TLS no agote la RAM contigua en el
    ESP32-PICO-D4. maxblock con 1 cliente subio de 42KB a 77KB (umbral ~40KB):
    - Cert chain de 4 a 3 certs (leaf + YE2 + Root YE, sin el cross-sign a
    ISRG Root X1). Root YE lo firma ISRG Root X2, presente en todo
    dispositivo 2021+. Ahorra 1598 bytes de heap por handshake.
    - OLED U8g2 de full-buffer (_F_, 1024 bytes contiguos) a page-buffer
    (_1_, 128 bytes). Libera el bloque contiguo que el handshake necesita.
    - HTTPS :443 arranca justo tras softAP(), antes de que DNS y HTTP :80
    fragmenten el heap.
    credentials.h (clave privada) sigue en .gitignore, no se sube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
    [nodo_portal_https.ino]
2026-08-23 fix(center): surface citizen reports and ingestion results
    [api.py, command_core.py, test_api.py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]
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2026-08-23 Centro notifica al rescatista por LoRa en cada cambio de estado (loop bidireccional)
    Cierra el loop del demo: cuando el operador prioriza/despacha o la grua acepta,
    avanza en ruta o resuelve, el centro transmite CENTRO|<nodo>|ST|<id>|<estado>
    al nodo del rescatista (send_broadcast, best-effort, sin exigir ACK).
    - api.py: helper _notify_citizen(request); enganchado en dispatch(), action()
    y simulate() (acciones ACC/ST del operador de grua).
    - command_core.py: get_request_by_node_seq(node, seq) para resolver la solicitud
    del ciudadano desde el payload de las acciones del operador.
    - test_api.py: test_dispatch_notifies_citizen_over_radio y
    test_operator_action_notifies_citizen_over_radio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
    [api.py, command_core.py, test_api.py]
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2026-08-23 Separar los 2 perfiles: centro (Juan Ortega) vs grua (Manuel Vargas)
    Son 2 apps distintas con 2 operadores distintos:
    - Centro de comando (dashboard): OPERADOR_CENTRO="Juan Ortega". Aparece en
    el topbar ("Operacion offline · Juan Ortega") y en el chip Operador de
    los formularios Solicitar grua / Accion humana.
    - Grua GRUA07 (grua.html, app del conductor): RESPONSABLE_GRUA="Manuel
    Vargas". Aparece en el header de su propia app ("Manuel Vargas · GRUA07")
    y como tag "Asignado" en la solicitud dentro del dashboard del centro.
    Antes ambos formularios del centro mostraban Manuel Vargas por error,
    mezclando el operador que llena el formulario con el conductor asignado.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
2026-08-23 Diferenciar el TIPO de operador en cada chip (grua vs centro)
    El chip "Operador" ahora lleva su tipo en el <label>, no un texto generico:
    - "Solicitar grúa" -> label "Operador de grúa" -> Manuel Vargas (conductor
    asignado a GRUA07). Antes decia "Operador" a secas con Juan Ortega, y
    quedaba pegado al selector de GRUA07, se leia como si fuera el operador
    del centro operando la grua (ambiguo, error reportado por el usuario).
    - "Acción humana" -> label "Operador de centro" -> Juan Ortega (puesto de
    mando), sin cambio de persona, solo la etiqueta explicita el tipo.
    operadorTag(label, name, detail) ahora recibe el tipo como parametro
    explicito en vez de un rol generico fijo.
    Co-Author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
2026-08-23 Acortar el home cuando es solo un puente hacia Chrome
    Con el salto anticipado a Chrome ya funcionando, la pantalla de home del
    portal cautivo se ve 2 veces: una ahi mismo, y otra vez (la real) al
    llegar a Chrome. El contenido explicativo (caja "Sin señal, pero
    funciona" + subtitulo largo) es redundante en esa primera vista: el
    ciudadano lo vuelve a ver segundos despues en Chrome.
    acortarHome() oculta la caja de alerta y acorta el subtitulo, pero SOLO
    se llama desde el callback de error del sondeo de GPS (gpsRoto=true
    confirmado). Si el GPS SI funciona ahi (ej. alguien entra directo por
    Chrome sin pasar por el portal cautivo), la funcion nunca se ejecuta y
    el home queda completo, con toda l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
2026-08-23 Un recurso puede atender varias categorias (fix: GRUA sin candidatos)
    Causa raiz: la tabla resources guarda un solo valor de kind, comparado
    por igualdad estricta contra la categoria de la solicitud. GRUA07 (el
    unico recurso fisico del demo) se registraba con kind=RESCATE, asi que
    nunca aparecia como candidato para su propia categoria natural GRUA
    ("via o vehiculo bloqueado", separada de RESCATE a proposito en la
    taxonomia) ni para ninguna otra. Por eso una solicitud GRUA quedaba en
    EN_REVISION con "Sin candidatos elegibles" sin ninguna forma de avanzar.
    - triage.kind_matches(resource_kind, category): el campo kind acepta
    varios valores separados por coma ("GRUA,RESCATE"); compatible con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
    [command_core.py, registrar_grua.py, test_command_core.py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]
2026-08-23 feat: add interactive 3D hardware catalog
    [bateria_placa.3mf, bateria_placa.stl, centro_bandeja.3mf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]
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2026-08-23 Mantener vivos los recursos simulados y avisar cuando un nodo caduca
    Sintoma: la tabla de Recursos mostraba 7 nodos "disponible", pero el
    detalle de una solicitud MEDICO decia "Sin candidatos elegibles" con
    MEDICO01 y MEDICO02 disponibles y de la categoria correcta.
    Causa: no era la categoria. Era la frescura del contacto.
    triage.compatible_resources() descarta cualquier recurso con last_seen
    mayor a RESOURCE_MAX_AGE_SECONDS (600 s): un nodo del que no se sabe
    nada hace 10 min puede estar sin bateria o fuera de alcance, y no se le
    debe despachar nada. Eso esta bien. El error estaba en el sembrado:
    mandaba UN solo HB+POS, mientras un nodo LoRa real late siempre. A los
    18 min los 6 recursos s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
    [sembrar_recursos.py]
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2026-08-23 No decir "pedimos ayuda por ti" cuando el pedido NO salio
    postReporte() se tragaba cualquier error del envio y devolvia 'PREVIEW'.
    enviar() ni miraba ese valor: siempre pasaba a la pantalla de exito con
    el recap y la linea de tiempo. Si el telefono perdia la red de la placa
    (pasa: Android se sale solo de una WiFi sin internet), el ciudadano veia
    "Pedimos ayuda por ti" y un timeline avanzando, con el pedido nunca
    enviado. Ese falso positivo es lo peor que puede hacer este sistema: la
    persona deja de buscar otra salida creyendo que ya la van a atender.
    - postReporte() devuelve {ok:false, error} ante un fallo de red Y ante un
    HTTP no-2xx (antes solo miraba la excepcion, un 500 pasaba por bue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
2026-08-23 Frases listas para el Motivo, y pulso continuo en lo que nadie respondio
    Motivo: el campo es obligatorio para registrar una accion, y redactarlo
    bajo presion cuesta tiempo. Ahora hay frases de un toque que lo rellenan
    (el operador puede editarlas o escribir la suya):
    - Despacho: cambian por CATEGORIA de la solicitud (medica, rescate,
    fuego, agua, grua) mas una comun a todas.
    - Accion humana: cambian por ACCION, no por categoria, porque tomar,
    cancelar, resolver y liberar se justifican distinto. Los chips se
    regeneran al cambiar el desplegable de accion.
    Delegacion en document para el clic: los chips se re-generan y un
    listener por chip se perderia.
    Mapa: una solicitud PENDIENTE (nadie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
2026-08-23 El boton "Pedir ayuda" nunca se apaga
    GOV.UK y el NHS dicen lo mismo de un boton deshabilitado: tiene mal
    contraste, no recibe foco de teclado y no explica POR QUE no se puede
    usar. Los 2 sistemas de diseno recomiendan no usarlo.
    En una emergencia pesa mas todavia. La norma NENA-STA-020.1-2020
    (§2.2.8) dice que la respuesta sale "con la mejor ubicacion
    disponible": la ubicacion es un dato deseable, no un requisito para
    atender.
    Ahora el boton siempre esta vivo. Si falta la situacion, al tocarlo
    sale un error concreto y la vista sube a las 5 opciones. Lo escrito
    no se borra.
2026-08-23 Portal cautivo de iPhone: pedir ayuda primero, GPS despues
    La pantalla del CNA de iOS era un callejon sin salida: solo daba 3
    pasos para abrir Safari. Nadie podia pedir ayuda desde ahi.
    Por que iOS no puede dar GPS en esa pantalla: WebKit bloquea
    navigator.geolocation en el motor cuando el origen no es seguro.
    shouldBlockGeolocationRequests() exige https/wss, loopback o file:,
    y el CNA carga la pagina por HTTP plano. Devuelve PERMISSION_DENIED
    sin mostrar permiso. No hay rodeo.
    (WebKit r200686, bug 157423; W3C Geolocation, "request a position")
    Cambios:
    1. Accion primero. Las 5 situaciones estan arriba y mandan el SOS
    ahi mismo, sin GPS, con un POST de formulario real. El CNA solo
    re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
    [nodo_portal_https.ino]
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2026-08-23 Aceptar tambien mueve la pantalla, y 3 huecos que salieron al revisar
    1. DESPACHADA y ACEPTADA seguian mandando el mismo texto. Ahora
    DESPACHADA dice "ESPERANDO UNIDAD" (la avisamos, no ha confirmado)
    y ACEPTADA dice "UNIDAD ASIGNADA". Con eso los 3 botones de la
    unidad mueven la pantalla del ciudadano: aceptar, en ruta y
    resolver.
    2. ENVIANDO y ENVIO_INDETERMINADO no tenian traduccion, asi que el
    codigo interno viajaba crudo hasta la pantalla y la OLED. Ver
    "ENVIO_INDETERMINADO" no le dice nada a alguien asustado. Los 2
    pasan a "ESPERANDO UNIDAD".
    3. scripts/validar_loop_lora.py se quedo con los textos viejos
    ("GRUA ASIGNADA", "GRUA EN CAMINO"). Habria dado FAIL so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
    [api.py, nodo_portal_https.ino, test_api.py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]
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
